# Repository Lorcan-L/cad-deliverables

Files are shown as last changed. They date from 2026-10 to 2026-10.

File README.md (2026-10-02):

# CAD 交付文件

本仓库公开制作深化图纸、可编辑CAD、逐件下料、采购清单与复核说明；R04同版交互三维可用于装配定位，R03保留为历史资料。

## 当前项目

[HW73005-L2000体验桌](https://lorcan-l.github.io/cad-deliverables/hw73005-l2000/)默认R04：22页图册、83项部件、35项五金组件、19种平板激光DXF与1种矩管锯切资料。R03/R02/R01历史下载保持原路径。

[R04同版三维装配查看器](https://lorcan-l.github.io/cad-deliverables/hw73005-l2000/files/R04/viewer/)可按件号旋转、分离、定位孔和线路，并跳转22页图册；三维用于装配定位，制作仍以正式图纸为准。

[AI 接单能力蒸馏方案](https://lorcan-l.github.io/cad-deliverables/ai-order-sop/)以 R04 和工程师反馈为回放材料，提出 Skill、状态工作流、独立校验器与分级交付的实施路径；方案本身不代表生产放行。

## 文件结构

project.json记录版次、可用状态、大小和SHA256。当前文件及同版三维位于files/R04；R03历史三维仍位于files/R03/viewer。预览来自各版最终PDF。

## 验收边界

R04为制造审核版，未生产放行。材料、割缝、折弯与V槽、结构荷载、五金配装及电气须首件和实物检验；数字回读不等同接收方CAD操作验收。

## 本地及Pages

仓库根运行`python3 -m http.server 8765`。GitHub Pages从main分支根目录发布。

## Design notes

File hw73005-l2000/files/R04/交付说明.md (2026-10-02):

# HW73005-L2000_R04 制造审核交付说明

2026-10-02；单位mm；每桌数量。此版为制造审核版，尚未生产放行。

## 交付内容

- DWG2004可编辑工程图、同版DXF、22页矢量PDF。PDF文字已转路径，不支持文字选取。
- 83项部件与35项五金组件的XLSX；公开参考价按销售包装换算，H04锁具套件仍缺精确单价。
- 19种平板激光DXF、1种矩管锯切说明，以及1张不另领料的S03A V槽工序辅图。
- 下料与工序索引.csv、page_manifest.json、validation.json。

## 已验证

- 图册22页；DWG回读22布局、10996模型实体、215原生尺寸。
- 全22页PDF逐页目检；下料文件已逐件几何与预览复核；同版SHA见validation.json。
- DXF的CUT层为名义净形；CAM割缝补偿不得混入图形。ETCH/GROOVE/INFO/REFERENCE不可作切穿。

## 生产放行前须确认

- 材料牌号、公差、割缝；同材同厚试折反算R/K与V槽余厚，复核刀具和回弹。
- 折盘与焊接首件、装配外包和孔位；H26压入H25后的保持力、可拔力和顶面齐平；SOSS 101开合。
- 4.0m国标16A CCC厂制主线规格、报价、外径及近C防拉脱拉力；JB1最终接头开孔模板。
- H04锁具完整套件价格；接收方CAD打开、量测、编辑及工厂首件验收。

历史R01/R02/R03不由本交付包改写；公开发布仅作制造审核资料，不代表生产放行。

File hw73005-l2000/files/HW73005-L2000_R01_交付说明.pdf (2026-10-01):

HW73005-L2000 · R01 · 2026-10-01 · 单位mm | 1

# HW73005-L2000

# 体验桌制作深化交付说明

R01 · 2026-10-01

## 本版依据顾客DWG有效模型、引用块、尺寸和五张参考照片制作。顾客确认桌面共2组翻盖，每组1个三位五孔并 带3USB的排插，总计2个；色号、光泽、图示指定公差及外观工艺按样板。

控制项 | 同版结论
成品外包 | 2000×1200×900；单位mm
桌面 | T18阻燃多层三聚氰胺板，双贴面；周边T0.25科技木皮
金属 | 侧边/腿T1.5，底盘T1.0，C筋T2.0；外观按样板
供电配置 | 桌面排插2；桌肚八位五孔排插2；明装五孔安全插座1
过线小件 | 外护套20；内盖10；镀锌内片10
成果 | 原生DWG 2004、同版PDF、BOM四表、交付说明与ZIP
当前级别 | R01成型深化稿。含设计调整、配作接口和首件工序；尚未生产放行。

# 文件使用边界

## DWG中每个图页有独立布局，模型实体以mm绘制；总装/零件图按图签比例输出，明确标出的局部放大图除外。 纸面标注优先，不从截图量尺寸。图签未填写实际审核人的姓名。

## 数字结构校核、PDF视觉检查和公开下载验证各自独立。它们不替代接收方CAD实机编辑、实际样板核对、工厂 折弯试制、电气装配检验或首件验收。

# 图号、PDF页码与件号索引

页 | 图号 | 内容 | 件号
1 | A01 | 整桌总装 · 三视、基准与装配尺寸 | A01
2 | A02 | 总装拆件 · 构件分离轴测与安装层次 | W01、W02A、W02B、A05、S01、S02、S04 、S05、S07、A07
3 | A04 | 钢结构总成 · 底视布置、三视与焊接 | A04
4 | A03 | 桌面与翻盖总成｜孔位、毛刷及护口布置 | A03
5 | A05 | 承托盒总成｜两组翻盖下方安装 | A05
6 | W01 | W01 桌面成品板｜实际切口与封边控制 | W01
7 | W02 | W02A / W02B 翻盖板｜有槽与实板配对 | W02A、W02B
8 | W03 | W03 承托盒长侧板｜阻燃多层板 | W03
9 | W04 | W04A / W04B 承托盒短侧板｜有孔与无孔分件 | W04A、W04B
10 | W05 | W05 承托盒底板｜托底构造与三视 | W05
11 | S01 | 长边斜腹板 · 成型与端部放样 | S01
12 | S02 | 短边斜腹板 · 成型与端部放样 | S02
13 | A07 | 刀形桌腿总成 · 分缝、脚件与过线 | A07
14 | S03A | 刀形腿壳 · 成型三视与焊缝 | S03A
15 | S03BC | 刀形腿封板 · 内端板与底封板 | S03B、S03C
16 | S04 | 桌肚底盘 · 折边、检修口与定位 | S04
17 | S07 | 检修门 · 门缝、铰链与排插固定 | S07
18 | S05 | S05 长向 C 型加强筋成型制作 | S05
19 | S06 | S06 U 型卡槽成型制作与安装 | S06
20 | A06 | A06 小孔过线护口组件｜配合与安装 | A06
21 | M01 | M01 304不锈钢过线外护套｜20件/桌 | M01
22 | M02 | M02 304不锈钢过线内盖｜10件/桌 | M02
23 | M03 | M03 内盖镀锌内贴片｜10件/桌 | M03
24 | E01 | 电气安装与走线｜位置、连接及R01过线调整 | E01、E02、E03、E04、E05、E06
25 | H01 | 五金与毛刷配套｜数量、接口及模板配钻 | H01、H02、H03、H04、H05、H06、H07、H 08、H09、B01、B02

BOM中的总成行用于装配追溯，不与子件重复领料；左右或异形件分别计数。线缆、管材和保护材料按现场实际长度配置，未知值保持空值， 不以0代替。

# R01尺寸协调与设计改变

项目 | 原图问题 / 本版处理
总高 | 源钢腿882加脚伸出5及桌面18会达到905；本版采用钢腿877、脚伸出5、桌面18，闭合为900。
桌体外包 | 源底视深向几何1200而覆字1190；本版金属1990×1190，桌面四边各退5。
加强筋 | 源T3线稿与T2文字冲突，采用T2；30×97、唇13，净距430、外跨490。
筋端干涉 | 原斜端与腹板内面局部交叉；本版上端及斜面向桌内净退至少1，保留阶梯和底退台。
翻盖 | 每组开口300×140；A有槽盖、B实截面各1片；每片298×58×18，长度方向1+298+1。
承托盒 | 每盒330×230×96；R01选T15阻燃多层板侧板、T5底板；每盒一个短侧板φ50过线孔。
底盘/检修门 | 底盘外包1769.4×969.4×15，定位115.3/115.3；检修孔X500，Y190/850，1000×160；门994.8×154.8，边缝2.6。
腿分片/底板 | 开口刀形壳+内端板+底封板；底封板T1.5、M8焊母8、调节脚8。分缝和底板厚为R01选定。
桌面紧固 | R01定12枚Φ4×12木螺钉；钢件φ4.5；木板预钻φ2.5深10，避免打穿。
过线冲突 | 源≥25铁管与刀形腿净腔约24.7不相容。本版提出管止于腿上口、腿内线缆保护引出；需实物样板/工厂复核该改变。

# 加工、装配与外协执行

## 木作：先核对板材和样板，按W01孔槽加工；翻盖从同纹理区配取并保持A/B方向。工厂结合实际刀具、锯缝和封 边厚度分配余量，不将成品2000×1200直接当基板尺寸。全桌20个小孔按外护套主体φ10.9配合试钻，φ11.9是法 兰，不能误作通孔。

## 钣金：按成型三视和截面开工艺展开；结合实际材料、内R、折弯扣除和焊接收缩先试1件。腹板端口、刀形壳与 底封板需按1:1成型轮廓配切。先焊母和内附件、后封壳；骨架点固校方，再对称分段焊。外露焊缝打磨及表面处 理按样板。

## 车加工：M01/M02采用304不锈钢棒；按同版剖面保留法兰、台阶、通孔/盲孔及圆角。M03为φ6×3镀锌内片。先 加工一组外护套/内盖试配，再按图示公差与样板执行；内片粘接后不得脱落或凸出妨碍装配。

## 装配：钢架完成外观处理后装脚、门、护口与线缆保护；试装桌面、承托盒和翻盖，检查中心毛刷净槽20及启闭 空间。排插及固定器避开门锁舌和合页转轴。接线采用源指定3×1.5mm²，端子连接处加黄腊管，线缆夹持并消除

锐边。

# 必须在工厂完成的具体闭合项

对象 | 所缺实物或工艺数据 | 影响
S01/S02/S03/S04/ S05/S06/S07 | 实际板材、折弯机/模具、K因子或实测扣除、焊接收缩 | 不能将成型外包当最终激光展开料
S03C及腿端口 | 首件壳体与腹板成型实物 | 底板内轮廓和顶斜口需套样配切
锁/铰链/排插固定 器/毛刷 | 实际品牌型号及安装模板、样板 | 孔形、夹持接口及毛刷卡入尺寸需实配
腿内过线 | 顾客样板或等效实物、实际护管和线缆 | 核实≥25管与腿腔矛盾的解决方案
整桌 | 首件与使用条件 | 静载/稳定性、翻盖与检修门、脚调节、电气检 验尚未实测

# 原图参考照片与对应工序

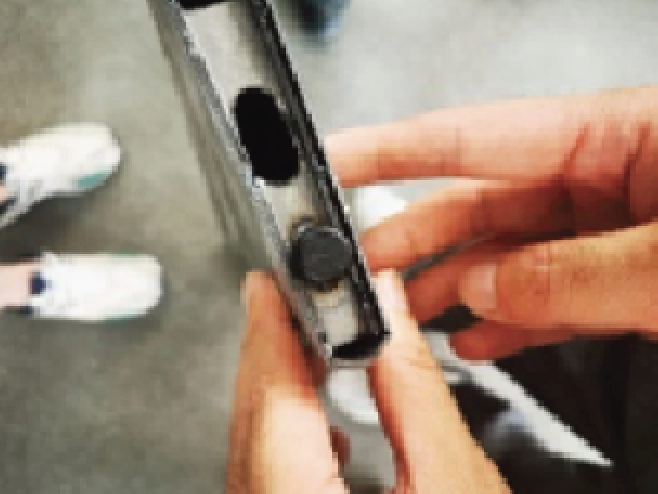
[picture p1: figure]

刀形腿内脚件：隐形调节脚及底部装配。

来源：顾客DWG有效图片 C908

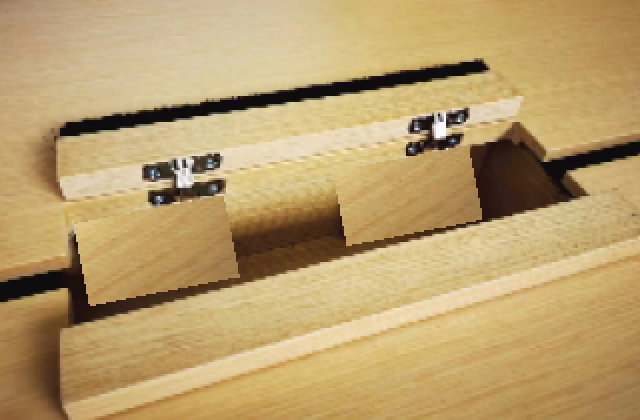
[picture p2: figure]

翻盖合页示意：闭合、开启与接缝按实配。

来源：顾客DWG有效图片 C909

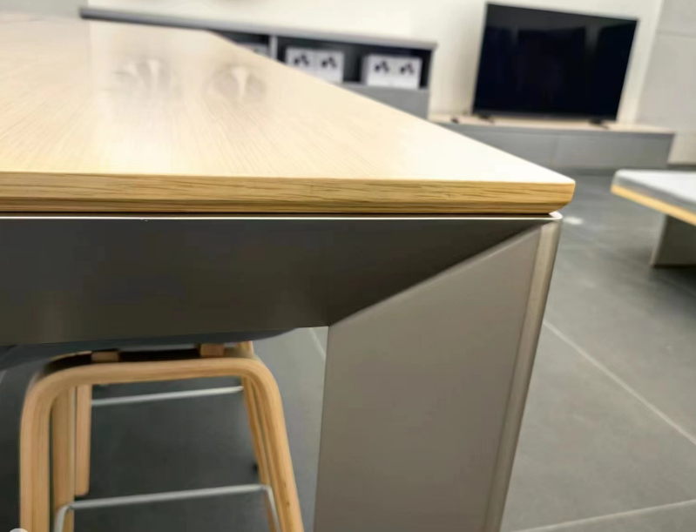
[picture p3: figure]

木饰面与钢侧边：纹理、封边和外观按样板。

来源：顾客DWG有效图片 C90A

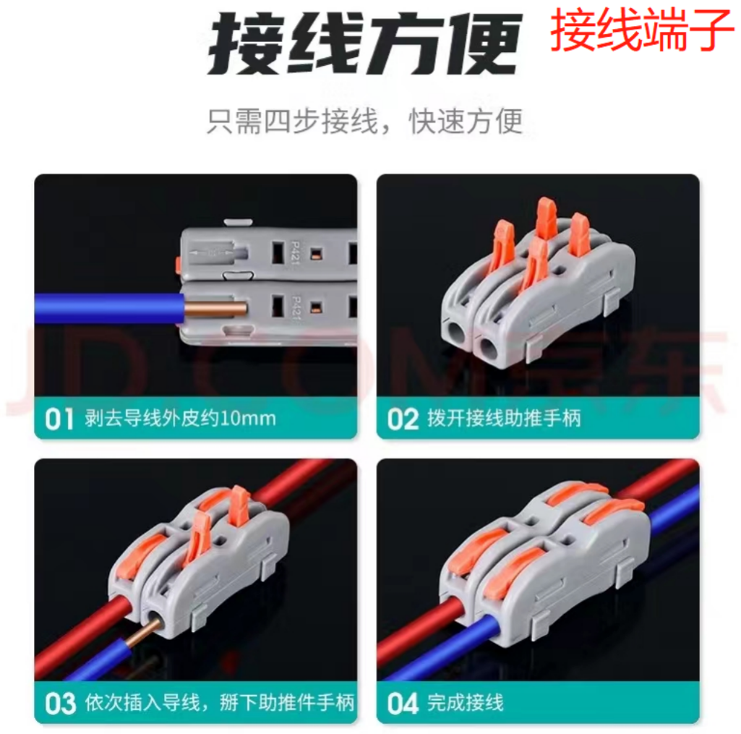
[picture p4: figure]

端子参考：按实际端子和线径完成绝缘保护。

来源：顾客DWG有效图片 C90B

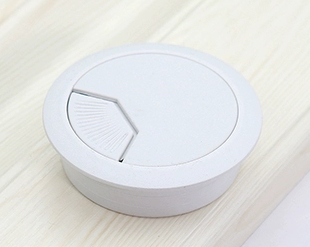
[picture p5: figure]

白色护口：承托盒φ50安装孔，选件实配。

来源：顾客DWG有效图片 D95E

# 逐类验证记录

类别 | 检查范围 / 结果
来源 | 顾客DWG：有效模型/引用块与五张图片已提取 旧未引用说明未纳入；原件副本只读归档
三视/接口 | 总装、分总成及制作件：已绘并进行图页复核；配作接口另列 各件front/top/side字段指向对应图页；曲面壳、折弯展开和到货五金仍须首件
CAD结构 | 同版DXF/DWG：DWG2004回读及逐实体校核通过 真AC1018、mm、25布局、144原生尺寸；29031项数值比较最大差5.83e-11，小于1e-7；转换副本补齐尺寸缓存和 VIEWPORTS图层
PDF视觉 | 全图册：25页逐页目检通过 中文、页码、图签、裁切与重叠检查；第9页尺寸已修；PDF SHA256 0c985bdb8ef0cef5bd1bed98eaff329f0e4b17fdf5297fe6138f533186925f31
同版清单 | 件号/页码/数量：42项件号、数量和父级核对通过 25图号映射一致，无缺失父级或自指；装配与领料分别计数；E04/E05长度留空
制造 | 钣金展开及腿配切：外部待定 需实际板材/刀具、折弯扣除、成型首件和焊接收缩；未发布最终展开下料
外购接口 | 锁/铰链/排插/毛刷：按到货模板及样板配作 型号未指定；本版已定安装基准，孔形/型材卡入尺寸不得猜测
过线冲突 | 刀形腿与≥25铁管：R01提出调整，实物待核 腿净腔约24.7；管止于腿上口，腿内线缆加保护与夹持；不得当原管贯穿已满足
接收方CAD | 实际接收软件/版本：未执行 ODA转换和ezdxf回读不替代接收方CAD操作验收
首件/电气 | 工厂实物：未执行 强度稳定性、脚调节、门盖启闭及电气检验须实物完成

# 文件身份与使用

### 正式下载文件及SHA-256以网页 project.json 和交付包内交付清单.json为准。哈希用于核对下载完整性，不是加工

## 正确性证明。原顾客文件保存在本地source目录，未被覆盖。

## 未完成的外部验收：实际接收方CAD打开/重生成/编辑、工厂展开及首件、电气装配测试。公开本版用于复核和工 厂深化配作，不等同于批量生产放行。

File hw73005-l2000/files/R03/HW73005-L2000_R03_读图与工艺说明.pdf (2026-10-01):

HW73005-L2000 · R03 · 单位mm · 未生产放行 | 1

# 体验桌 R03 读图与工艺说明

## 先定位，再看接口，最后按尺寸加工。

图册52页；BOM共84项。三维网页、装配模型、PDF、二维CAD及清单共用件号。总成数量用于装配追溯，不能 与子件相加领料。

1 找件号 | I01制作件与总成；I02五金；I03电气。按件号查三维图、加工/接口图和孔号。
2 看位置 | 整桌 A02 / P05；桌面 V02 / P06；木盒 V10 / P07；钢架 V03 / P08；检修 V04 / P09。
3 看接口 | 五金局部 V05 / P10、V07 / P12；电器 V06 / P11；端子箱 V08 / P13；PE/入口 V09 / P14。
4 看尺寸 | 按引线旁的图号及页码打开制作三视。图纸里的跨图引用和目录带PDF内链；CAD中每张图有同名布 局。
5 查线孔 | 电气导航 E01 / P43；原理 E02 / P44；端子 E03 / P45；入口、C筋及木盒孔见E04～E06。
6 用三维 | 按件号搜索 → 选中 → 只看选中。分离滑杆用于拆装关系；看孔与路线时自动回到安装位置。选择孔 号可查看孔径、所在件及经过线路。

## 图形读法

彩色实体表示已建的成型几何或采购件简化外形；线框安装区不表示厂家完整实体。小符号表示已知安装位置而 外形待核。虚线板件用于定位；三维轴测不能量取加工尺寸。

外形未核的排插、插座、箱体接头等不伪造孔径。标为“待核”的孔禁止按规划点直接钻孔。

## R03修订与装配顺序

木盒出线 | 原短侧W04A取消。两块近侧W03A开φ50，孔心局部165/51；远侧W03无此孔，W04B统一4块。H0 6从外面装入22、内凸约7。见W03 / P22、E06 / P48。
内部装配 | 四根螺接横梁、木盒及电器留在钢架；八点M6使整块桌面可拆。检修口和工具通道不作走线占用。
分线箱 | E07采购一套：1557HA2GY箱体1件＋另购1557HPL内板1件。E15为150导轨1段＋端挡2件＋绝缘 端板3件，不能只采购裸导轨。
移动检修 | 载板名义下放175.45。防坠索孔心距183不是盖板垂降；盖板服务位和两组独立锚点按S10F / P16。线束和PE不承重。
模型修正 | 后门排插固定器按全局X1100/1400布置；箱内19端子操作面向下，导轨包络以线框表示。所有模型 页码重新绑定R03图册。

## 现场装配顺序

① 钢架点固校方、焊接和表面处理 → ② 装四横梁、盒抱角和检修支承 → ③ 装木盒、端子箱和成品五金 → ④ 按线路号穿孔、固定、端接并检查PE → ⑤ 试门盖及载板全行程 → ⑥ 装桌面、翻盖和毛刷 → ⑦ 完成首件检验后放行。

检修时先停负载、断电、拔下总输入并由检修者控制插头，验无电后再操作。松防脱螺钉之前确认相应防坠索已 可靠连接。回装检查夹线、接地、紧固与启闭。

## 制作控制 · 按图号回查

W01 / P20 | B：φ10，顶钻深11.5；C：φ10起试，孔深≤14；C：留面≥4，嵌母齐底；基板1999.5×1199.5；四边 T0.25木皮；外R15
W02 / P21 | 2×φ10深11.5；u=50 / 248；底余厚6.5；A在低Y侧，槽口朝中间；B在高Y侧；每盖两只BH104；端 缝各1；周边缝2；A/B各2片，同板顺纹；底槽沿A盖全长；抬90°检修，勿踩踏
D02 / P25 | RS 326-9808；2根×1m；段间缝1；总覆盖1420；每段2枚φ3×8木螺钉；座孔φ3.5；木盲钻≤6；BH 104共8只；φ10顶钻深11.5；距开合边6.8；边缝2；抬90°检修
S03A / P29 | 冷轧钢板T1.5；数量4；鼻端保留R8；内R6.5；端板分缝朝桌内；顶口u18..131.062降100；首件检 截面及腹板贴合；切割 → 包折 → 试装；装底板焊母 → 封板焊接；外露缝磨平后表面处理
S03BC / P30 | B/C各4片；冷板T1.5；C沿壳内廓配切，缝0.2；C下表面内沉1；先焊M8母，通规后封B；不设腿内 过线孔
S05 / P33 | 冷板T2；数量2；截面30×97；斜边净退≥1；先试装再焊；展开按首件试折，不取投影周长；C口相 向；净距430；M5柱朝C内；详E03/E16
S09B / P38 | 钢板T3；宽40×包40×高35；槽6.6×12沿X；距端13；竖腿焊于C筋外腹面；焊后校准8耳共面；内R 与扣除经首件试折
S10C / P41 | 钢板T3；宽20；数量4；右侧绕Z转180°；先焊M5母；四臂下面Z874共面；吊线只接左前/右后；固 定锚见S10F；M4×16头部至木底净≥0.75
A06 / P52 | H25 CHC-S18BL：20只；孔φ14 +0.5/0；H26 045.00.332：10只；有线孔不装盖；衬套入孔16；法 兰2；加盖总突出4；跨品牌组合：首件验卡紧与拔出保持

本页只汇总当前R03工艺控制。孔位、三视、板厚及节点尺寸均以同版制作图为准；历史迁出的长说明不作为当前加工指令。

## 电气工艺说明 · 1

## NE01 现场保护 · E02 / P44

QF0为现场边界，过流允许值不大于10A，Type A 30mA；曲线、分断和上下级配合由现场核定，不表示已安装。 I1+I2+I3+I4+I5≤I_allow≤10A，I_allow取上游、P0/X0、线束及最弱器件的最小允许值，不得相加各排插标称功率

。

## NE02 原装线与支路 · E02 / P44

P0整根国标10A/C13成品线；四排插各接独立固定插座，保留原装线和插头，不互相串接、不剪改。W00/W1~W 5铜芯护套线3×1.5mm²，L棕/N蓝/PE黄绿，两端永久套号。

## NE03 端子工艺 · E03 / P45

WAGO2002按厂家剥线10~12mm；软线适配端头冷压，一夹一线，不用浸锡线夹压。L灰/N蓝各自用一根2002-4 06六连桥，PE专用接地脚与连续导轨，绝不N-PE跨接。端挡249-116两只、隔板2002-1291三只，DIN35×7.5轨 约150实装核。

## NE04 绝缘和抗拉 · E04 / P46

X0使用6100.3300、RC320-03后罩、TE735278全绝缘快接L/N/PE各一；不从视图猜端脚顺序。后罩/快接不抗拉 ，独立机械夹护套；黄腊管只附加绝缘，不替代护套、护口、封闭盒和应力释放。

## NE05 保护连接 · E03 / P45

E16七条2.5mm²黄绿线：XPE6到PE0、PE0到焊组、另三梁到焊组、两门到焊组。11只FV2-5、2只FV2-4，10只 M5×20焊柱及各齿/平垫/防松母、2套门M4紧固、1只3202533套管；不含E21~E24中央两线。PE不断开，不经开 关熔断器，不用油漆面、铰链或结构螺钉代替。

## NE06 断电检修 · E03 / P45

停负载、断现场保护、拔P0并由检修者控制插头挂牌；测试器前后自验并验无电，等待成品电源放电。确认两防 坠线承重后卸防脱螺钉，下放载板175.45；盖索孔心距183，服务位见S10F；线不受拉再检修。按端子号复接， 验PE连续性、极性、绝缘、端子、抗拉、门全启闭与保护动作，负载预算核定后复装送电。

## NE07 入口弯线 · E04 / P46

W00护套外径≤8.5，厂家允许静态最小弯曲半径≤30；后罩至Z834、木底Z882，线弯外包不得超Z882。该约束是 选线条件，尚待到货曲率和全轨迹首件；活动段另核，不把折线当可实际锐折。入口切口28(+0.2/0)×20(+0.2/0)， R≤3，2φ3.5孔距40±0.2。

## NE08 C孔和过梁层 · E05 / P47

两S05 C腹板φ20/T2仅穿护套线，护管止于孔前；实际护管外径≤25方可进入Z848..882净34的过梁层，路线中心 暂Z865。DN25不是外径25；线夹、弯头、护口内径和侧向通路均需实物核定，不绕C筋近乎无净空端部。

## NE09 门排插包络 · E05 / P47

GN-604每门一只；400×100×86.5是固定器、原线及用户插头总验收包络，顶≤Z870，不能冒充厂家外形。X3/X4 固定插座符号只指安装区，配合门启闭、锁舌、铰链、8点工具柱试装后锁定支架/孔。

## NE10 木盒原装线 · E06 / P48

R03将两个原装线孔移至近侧W03A长板，取消W04A短端孔：孔心左X600/右X1400、Y492.5/Z842，局部165/51 ；φ50/T15，Häfele429.99.735白护口入孔22向内约7。板外Y485至C筋Y385净100，孔边至最近横梁面净155， 上边余15/下边26。U1/U2从长边孔接X1/X2；原装插头通过、护口拆装顺序和弯曲半径仍需首件，禁止剪改原装 插头或梁。

## NE11 待核开孔 · E04 / P46

JB1 K10~K16中心继承R02路线端点，接头型号、孔径、绝缘和抗拉尚待选型；不得照规划点钻孔。X1~X5外包/ 固定孔未知，保持null。箱内150轨、19端子和182方内板按E03设计面Z862装配；内板柱高/紧固孔与盖内净距首 件核。中国适用认证、到货CCC、完整保护和通电试验未执行，不据图直接生产放行。

## NE12 中央移动余量 · E03 / P45

JB1盖向下，200×200×70；左右接头突出≤30。载板下放175.45；盖索孔心距183、锚点垂降181.227，服务位见 S10F；各两条防坠索独立承重；电缆和两条2.5mm²中央PE额外维护余量初设≥250，按厂家弯曲半径及全程实物 定长，PE不吊重。E21两线独立回PE0；E22/E23环端各两只，E24移动M4套两套。

## NE13 用户孔 · E06 / P48

W01二排20孔，X235+170n（n0..9）、Y250/950，φ14+0.5/0，配CHC-S18BL内φ12。UC01~UC20仅表示预留 过孔，用户设备和下方终点未指定；不将任意孔接到本机市电支路。闲置10孔盖与衬套为跨品牌组合，首件配装 待核。

## 同版使用与验收范围

有效文件 | 本次仅成套使用R03。R01/R02保留作历史记录，不混用旧W04A短侧孔、旧模型坐标及旧页码。
二维工程 | DWG/DXF含原生尺寸、线弧和同图号布局。按制作三视加工；最终折弯展开仍需工厂用实际板厚、 内R及折弯扣除试折确定。
三维工程 | 装配DXF/DWG使用同源网格面、实例块和件号信息。采购包络为线框；用于定位和拆件，不是参数 化实体或展开加工模型。
采购与替代 | 按采购XLSX中的型号、套件组成、包装量及原厂来源核实。替代品改变外径、板厚、孔距、锁舌或 接头时，回到接口图复核。
实物首件 | 承载、稳定性、焊缝、脚件净空、翻盖、插头通过、下放余量、线夹抗拉、PE连续性、绝缘/极性和 保护动作尚待工厂及电气首件。
三维访问 | 优先从交付网页打开三维索引。ZIP内viewer目录是同版备份；离线查看时需通过本地HTTP服务打开 ，直接双击HTML可能无法载入模块。

本轮验证区分图面可读性、同源几何和文件完整性。程序检查、模型核对及浏览器操作不替代接收方CAD编辑验 证或实物验收。

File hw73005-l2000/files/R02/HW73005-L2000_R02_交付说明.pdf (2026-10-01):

HW73005-L2000 · R02 · 2026-10-01 · 单位mm | 1

# HW73005-L2000

# 体验桌制作深化交付说明

# R02 · 可拆检修修订 · 2026-10-01

## 本版按“桌面检修、灵活固定、成品五金清单、线路图、桌肚内部加强及检修位置”的反馈修订。沿用顾客DWG外 形及两组桌面供电配置，新增内部机构和可重复拆装接口。颜色、光泽、图示指定公差及外观工艺按样板。

控制项 | R02同版结论
成品外包 | 2000×1200×900；T18阻燃多层三聚氰胺板双贴面；T0.25科技木皮封边
固定与加强 | 桌面8点M6机螺钉/嵌母；4根40×50×T2可拆横梁；承托盒固定钢架
检修 | 2个长检修门、1个中央检修盖；盒及排插留在钢架；中央接线吊板可下放
供电 | 2个桌面三位五孔+3USB排插；2个桌肚八位排插；1个安全五孔；五路并联
小护口/毛刷 | 20套CHC-S18BL护口配10只成品盖；毛刷按固定板和翻盖分5段
成果 | 37页图册、84项BOM、独立采购清单、交付说明及ZIP
当前级别 | 成型深化稿；已绘成品接口、三视及检修动作，尚未生产放行。

# 使用规则

## R01保留作为历史版本；本次制造复核只使用R02整套文件，不混用旧脚孔、护口孔、12点木螺钉及检修门坐标。 DWG按mm绘制，每图号有独立布局；局部放大按页内说明。不得从截图量取加工尺寸。

## 模型/尺寸校核、PDF目检和下载哈希各自独立；不替代接收方CAD编辑、厂家实物配装、结构承载或电气首件验

收。

# 图号与PDF页码索引（1～19）

页 | 图号 | 图页内容 | 件号
1 | A01 | 整桌总装 · 三视、基准与装配尺寸 | A01
2 | A02 | 总装拆件 · 构件分离轴测与安装层次 | W01、 W02A、 W02B、 A05、 S01、 S02、 S04、 S05、 S07、 A07、 S08、 S10A、 S10B
3 | A04 | 钢结构总成 · 底视布置、三视与焊接 | A04
4 | A03 | 桌面与翻盖总成｜孔位、毛刷及护口布置 | A03
5 | A05 | 承托盒总成｜两组翻盖下方安装 | A05
6 | W01 | W01 桌面成品板｜实际切口与封边控制 | W01
7 | W02 | W02A / W02B 翻盖板｜有槽与实板配对 | W02A、 W02B
8 | W03 | W03 承托盒长侧板｜阻燃多层板 | W03
9 | W04 | W04A / W04B 承托盒短侧板｜有孔与无孔分件 | W04A、 W04B
10 | W05 | W05 承托盒底板｜托底构造与三视 | W05
11 | D02 | 翻盖与成品毛刷安装 · 顶装桶铰链、承托及分段 | W01、 W02A、 W02B
12 | S01 | 长边斜腹板 · 成型与端部放样 | S01
13 | S02 | 短边斜腹板 · 成型与端部放样 | S02
14 | A07 | 刀形桌腿总成 · 分缝与成品脚件 | A07
15 | S03A | 刀形腿壳 · 成型三视与焊缝 | S03A
16 | S03BC | 刀形腿封板 · 内端板与底封板 | S03B、 S03C
17 | S04 | 桌肚底盘 · 折边、检修口与定位 | S04
18 | S07 | 检修门 · 门缝、铰链与排插固定 | S07
19 | S05 | S05 长向 C 型加强筋成型制作 | S05

总成行用于装配追溯，不与子件重复领料；各件数量均按每张桌。线缆长度、包装数量与装配用量分开，未定数值保留空值。

# 图号与PDF页码索引（20～37）

页 | 图号 | 图页内容 | 件号
20 | S06 | S06 U 型卡槽成型制作与安装 | S06
21 | A08 | R02 内部加强与检修 · 八点拆面、横向框架及接近通道 | A08
22 | S08 | S08 可拆横梁总成 / S08A 矩管身 · 成型三视与端接口 | S08、 S08A
23 | S09A | S09A 横梁端板 · 焊母接口及C腹板连接 | S09A
24 | S09B | S09B 桌面固定耳 · 原检修口上方八点可拆接口 | S09B
25 | S09C | S09C 承托盒抱角 · 盒固定在钢架且可拆 | S09C
26 | S10 | S10 中央检修盖与吊检修板 · 三视、支承及防坠 | S10A、 S10B
27 | S10C | S10C 检修板悬臂 · 左右转向装配、焊母及防坠锚点 | S10C
28 | S10DE | S10D 补强片 / S10E 锁接收座 · 成型三视与接触剖面 | S10D、 S10E
29 | S10F | S10F 中央检修服务位 · 成品索长度、独立锚点及实体行程 | S10A、 S10B、 S10C、 H23、 H24
30 | D01 | D01 桌面可拆固定 · M6嵌件节点、工具柱及拆卸顺序 | W01、 S09B、 H09
31 | E01 | R02 电气物理布线｜成品入口、五末端及三向检修位置 | E01、 E02、 E03、 E04、 E05、 E06、 E07、 E08、 E09、 E10、 E11、 E12、 E13、 E14、 E15、 E16、 E17、 E18、 E19、 E20、 E21、 E22、 E23、 E24
32 | E02 | R02 五路电气原理｜L/N/PE分别接线，连接示意不按空间比例
33 | E03 | R02 端子接线与检修｜逐点编号、线色线径、脱开与复装
34 | H01 | H01 成品五金采购索引与每桌用量 | H05、 H06、 B01、 B03、 H23、 H24
35 | H02 | H02 桌面、调节脚及防脱紧固接口 | H01、 H02、 H09、 H10、 H11、 H13、 H14、 H15、 H16、 H17、 H18、 H22
36 | H03 | H03 检修门、工具锁与小翻盖安装接口 | H03、 H04、 H07、 H12、 H19、 H20、 H21
37 | A06 | A06 成品小孔衬套与闲置孔盖装配接口 | A06、 H25、 H26

总成行用于装配追溯，不与子件重复领料；各件数量均按每张桌。线缆长度、包装数量与装配用量分开，未定数值保留空值。

# R01 → R02 修订及接口替换

对象 | 本版改变
可拆桌面 | 原12枚木螺钉改8组M6×12+平垫+RAMPA SKD30 M6×12。孔心X580/850/1150/1420，Y328/872；木底预钻10～10.5、深≤14。
内部横梁 | 4根RHS40×50×T2，管长472，端板T3后总长478；每端2枚M6×20及4mm垫层，共16螺钉、64片1mm垫。
承托盒 | 两个330×230×96承托盒由8个S09C抱角托住；8枚M4×25由盒内穿端板紧固。拆桌面时盒与电器留钢架。
长检修门 | 窗口X500..1500，Y180..340/860..1020；994.8×154.8门四边缝2.6。HG-OTA75合页及MS705-1-1锁均绘真实接口。
中央检修 | 净窗300×340，X850..1150/Y430..770；340×380盖搭接20；240×300接线吊板独立支承，盖及吊板各4枚防脱螺钉。
脚与高度 | 成品TG-20：φ20×高6、M8×15；底封板内沉1，外露5。脚孔移u80/110、v13.9665避开腿壳窄端，取消旧34×14穿线 孔。
小护口 | 原定制M01/M02/M03退出R02领料，换CHC-S18BL20套+Häfele盖10。W01安装孔改φ14(+0.5/0)，外法兰φ18；跨品 牌盖须实配。
翻盖/毛刷 | BH104桶铰链每盖2只共8；顶面φ10深11.5，闭合共面时可见链节。SU-30S角码承托。毛刷分160/298/500/298/160 五段，两298段随A盖抬起。
供电入口 | 取消腿内穿主电源；成品国标10A/C13线接桌底X0 C14。X0中心280/430，28×20切口、两φ3.5孔中心距40。原厂RC320-03后罩保护端接。
线路图 | E01物理布线，E02五路L/N/PE原理，E03端子/检修。四排插保留原插头，禁止互插；上游QF0为现场供电边界。

# 加工与装配顺序

## 1. 木作先核板材和样板。W01按切口、φ14护口孔和八点嵌母盲孔加工；嵌母试装后确认不鼓面。BH104从顶面

### 钻φ10深11.5，不能从底面反钻；四盖保持A/B方向和连续木纹。SU-30S配φ3×12螺钉，不使用长于侧板厚度的原

## 配螺钉。

## 2. 钣金以真实成型三视、源线弧截面和节点为基准。实际内R、折弯扣除、焊接收缩由工厂试折确定；成型外包不 是激光展开料。刀腿底封板依成型内腔留0.2配切，先焊母、后封壳；两脚φ20包络与斜内壁最小余量约0.4，首件 检查不可省略。

## 3. 钢架点固校正后对称焊接。两C筋各8个φ6.6横梁连接孔、1个φ20护口孔；四横梁及端板先核净长和转出动作， 再紧固。固定耳、盒抱角、中央悬臂、补强片和锁座按本版坐标焊装。

## 4. 两承托盒放入抱角；从盒内装M4×25和垫片。安装两桌面排插及固定分支插座，原装线整理并夹持。毛刷铝座 按五段裁切、去毛刺，每段两枚φ3×8固定；毛刷沉入28×7槽，不宣称刷顶齐台面。

## 5. 固定中央接线盒至吊板，接好两独立防坠件与专用柔性PE，再固定四枚防脱螺钉。防坠件锚点和标准长度按S1

### 0/S10C/H02最终图执行；不得自行剪短、打结或用电缆承重。

## 6. 安装长门成品合页、锁、接收座及排插固定器。门上的电缆和PE留活动弧，开门后八个φ12工具通道保持可达 。试合门、拔插总入口、中央盖拆装和吊板下放，确认不夹线再进入电气检验。

## 7. 最后安装木桌面。M6螺钉从检修门向上旋入，采用细杆长5mm内六角工具；不从上表面打穿。确认全部桌面载 荷落在钢架支承面，再锁紧八点。

不能省略的实物确认 | 对应图/说明
腿壳截面、脚可调/不碰壳、整桌900高 | A07、S03A/S03BC、H02
BH104方向、盖缝、独立承托、插头实插净空 | W01/W02、D02、H03
横梁转出与门工具通道 | A08、S08/S09、D01
防坠/下放、线束弯曲、触电防护与接地 | S10、E01～E03

# 检修路径与拆装操作

## 所有检修先停止负载、断开现场供电并拔总输入P0；由检修者控制插头，确认下游无电。拆木面前先移走用户设 备及穿过小孔/毛刷的线，避免外部线缆牵挂。

场景 | 入口与操作 | 回装检查
桌面插拔/小翻盖 | 从桌面两组翻盖操作；盖向上手扶约90°，BH104无停留扭矩。 | 闭合由SU-30S独立承托；不靠铰链承受台 面载荷。
整面拆卸 | 开两长检修门，沿X580/850/1150/1420、Y328/872直达八枚M6；全部 拆下后多人平稳抬面。 | 承托盒和电器留钢架；确认八点嵌母未松 脱、工具通道无新线束。
更换桌面排插 | 断电后打开翻盖并拔对应原装插头；必要时拆整面，从盒内卸4枚M4后 取该盒。 | 不剪原装插头，不让木板承担接线盒重量 。
长门排插 | 开启相应转舌锁，下翻门并保护活动线/PE；需拆门时使用可缩轴合页 。 | 锁舌搭接S10E、门缝2.6，线圈不进入合 页和锁区域。
中央接线检修 | 先确认中央盖两防坠件，松4颗防脱螺钉将盖挂至窗外；再确认吊板两 独立防坠件，松4颗防脱螺钉后受控下放。 | S10F名义下放175.45；实物线缆弯曲限制 优先。下放件有机械支承，PE仅负责保护 连接。
横梁拆换 | 断电、拆桌面及相关承托盒/吊件；标记并断开该梁PE，再松端部M6， 按A08上移越过C下唇，再转约35°上取。 | 附件先移除；复装先恢复PE并测连续性； 转出不能带盒硬扭，不以481.75转角包络 代替实物演练。

## 复装后逐项确认螺钉、防脱件、防坠件、线缆夹持、保护接地、门盖启闭及工具通道；按电气检验记录合格后恢 复供电。

# 成品五金采购清单的使用方法

## 独立采购XLSX是本版对外询价入口。每行区分厂家技术来源、销售入口、每桌装配用量、包装量及到货条件。官 网可订购或经销商列货不等于国内现货；未下单，不在图册中承诺交期。

采购组 | 锁定内容 | 到货必核
桌面与钢架紧固 | RAMPA SKD30 439612001、M6×12、M6×20、DIN988 垫片及各规格DIN929焊母 | 螺纹、长度、焊母定位凸台；焊母与通孔不能混为普通 间隙孔
调节/门五金 | LAMP TG-20、HG-OTA75、恒珠MS705-1-1完整套件 | 锁芯/35长舌/GH18版本；不能混用同名不同锁舌长度
翻盖 | SOSS BH104×8、LAMP SU-30S×8、指定长度木螺钉及软垫 | T18试装、顶钻方向、角码承托、螺钉不得穿板
小孔 | CHC-S18BL×20、Häfele045.00.332盖×10 | 跨品牌组合不是厂家认证配套；试插拔/卡紧；包装数量 不等于使用数量
中央检修 | NBK SSC-M5-8共8、匹配M5焊母、防坠成品共4 | 有效牙长及板层厚度、防脱动作、标准防坠长度、锚点 保持力
毛刷 | RS PRO326-9808，1m成品2根 | 基座/毛长与28×7槽实配；按5段切割留锯缝
电气 | E01～E03列成品排插与插座，E07后续列分线盒、端子、 后罩及端接辅件 | CCC/适用认证、原装线、保护门、外包、插头与门盖净 空

## 采购先按清单型号及图号核实，再选择同型号销售渠道。任何替代品改变外径、板厚、安装孔、锁舌、接头或线 径时，都应回到相应图页核对，不能只以外观相似替换。

## R02取消原定制小护口的车加工领料，但S08/S09/S10等钢制支架、端板、抱角仍按本项目制作图加工；它们属于 结构制造件。未知线缆长度须在样机布线后定长，不填0，不凭二维投影折线直接领料。

# 线路图与电气执行边界

### 五路星形并联：现场保护QF0 → 接地插座 → 原装国标10A/C13成品线P0 → 桌底C14入口X0 → 中央分线盒JB1 →

### X1～X5。X1/X2供两桌面排插，X3/X4供两门排插，X5为安全五孔。四排插均保留原装插头及软线。

图页 | 执行内容
E01 物理布线 | 标出X0、JB1、五个固定终端、两C筋护口、活动线和总输入隔离；坐标只是布置中心，成品外包另须实测 。
E02 L/N/PE原理 | L、N各6只WAGO2002直通端子、各自独立6连桥；7只专用PE端子经已接地DIN轨连接。PE不得与N跨接 。
E03 端子与检修 | 列电源/支路去向、端子标记及检修顺序；线端永久套号，弹簧端子按厂家适配线径和剥线长度执行。

### X0的SCHURTER6100.3300配原厂RC320-03绝缘后罩及6.35×0.81全绝缘母快接；后罩/出口及独立应力释放按E

## 页执行。主进线改沿腿外侧可拆线夹固定，腿内不再强穿≥25护管。

## 上游保护尚属现场边界；浅盒只装分线端子，不伪称已装入普通深型RCBO。总允许电流按现场保护、10A入口及 最弱器件/敷设条件取最小值；设备USB电源的AC输入也计入同时负载，不能将各排插标称功率相加。

## 四根螺接横梁分别通过专用PE焊柱连接主框架；两活动门、中央盖和吊板使用独立柔性PE跨接，不依靠铰链、漆 面接触或防坠钢索导电。电线和PE均不得承担盖或盒重量。

## 放行前需要：适用认证与型号实物一致、上游保护配合、五支路负载记录、端接与夹持、极性、绝缘、保护接地 连续性及保护动作检验。当前图册未宣称这些实物检验已完成。

# 原图参考照片与R02对应关系


刀形腿隐形脚：R02按TG-20重新核定宽端孔位。

来源：顾客DWG有效图片 C908


原翻盖意向：R02采用BH104顶装并独立承托。

来源：顾客DWG有效图片 C909


木饰面与钢侧边：纹理、封边及外观按样板。

来源：顾客DWG有效图片 C90A


原端子意向：R02以WAGO端子及分路图为执行依据。

来源：顾客DWG有效图片 C90B


原白护口意向：盒端φ50孔按成品实配。

来源：顾客DWG有效图片 D95E

# 逐类验证与未完成的实物验收

类别 | 范围 / 结果
来源 | 顾客DWG：有效模型/引用块与五张图片已提取 旧未引用说明未纳入；原件副本只读归档
三视/接口 | 总装、分总成及制作件：已绘并进行图页复核；配作接口另列 各件front/top/side字段指向对应图页；曲面壳、折弯展开和到货五金仍须首件
CAD结构 | 同版DXF/DWG：DWG2004回读通过；37布局、202原生尺寸、49,208项数值一致 同版DXF/DWG SHA绑定；最大绝对差5.82×10⁻¹¹mm；audit错误0，修复0
PDF视觉 | 全图册：37页已逐页目检通过 最终PDF SHA绑定01～20、21～30、31～33及34～37页报告；中文/尺寸/图签和检修接口可读
同版清单 | 件号/页码/数量：84项件号、父级、图号、页码与三视引用检查通过 含8条装配追溯行，不与子件重复领料；E04/E05长度保留空值；两份XLSX另附公式/超链接验证
制造 | 钣金展开及腿配切：外部待定 需实际板材/刀具、折弯扣除、成型首件和焊接收缩；未发布最终展开下料
外购接口 | 成品五金及电器：已选可购型号，分列厂家实证和到货项 hardware_sources及electrical_design；M6嵌母、桶铰链、锁、合页和护口接口已纳图
拆装检修 | 八点桌面、四横梁、三检修口：R02机构与工具通道已绘 八点Y328/872、两门Y180/860、中央300×340；实物动作/强度未验证
电气 | 总输入与五支路：三页物理布线/原理/端子表已绘 排插原插头保留；X0可达总入口；L/N/PE分配及活动件PE跨接
接收方CAD | 实际接收软件/版本：未执行 ODA转换和ezdxf回读不替代接收方CAD操作验收
首件/电气 | 工厂实物：未执行 强度稳定性、脚调节、门盖启闭及电气检验须实物完成

# 文件身份

### 同版文件与SHA-256以公开网页project.json和ZIP内交付清单.json为准；哈希仅用于核对下载完整性。R01原件和

## 顾客文件保留未覆盖。此版可供工厂按明确接口试制与复核，最终展开、承载稳定性、到货适配和电气首件均须 实际完成后放行。

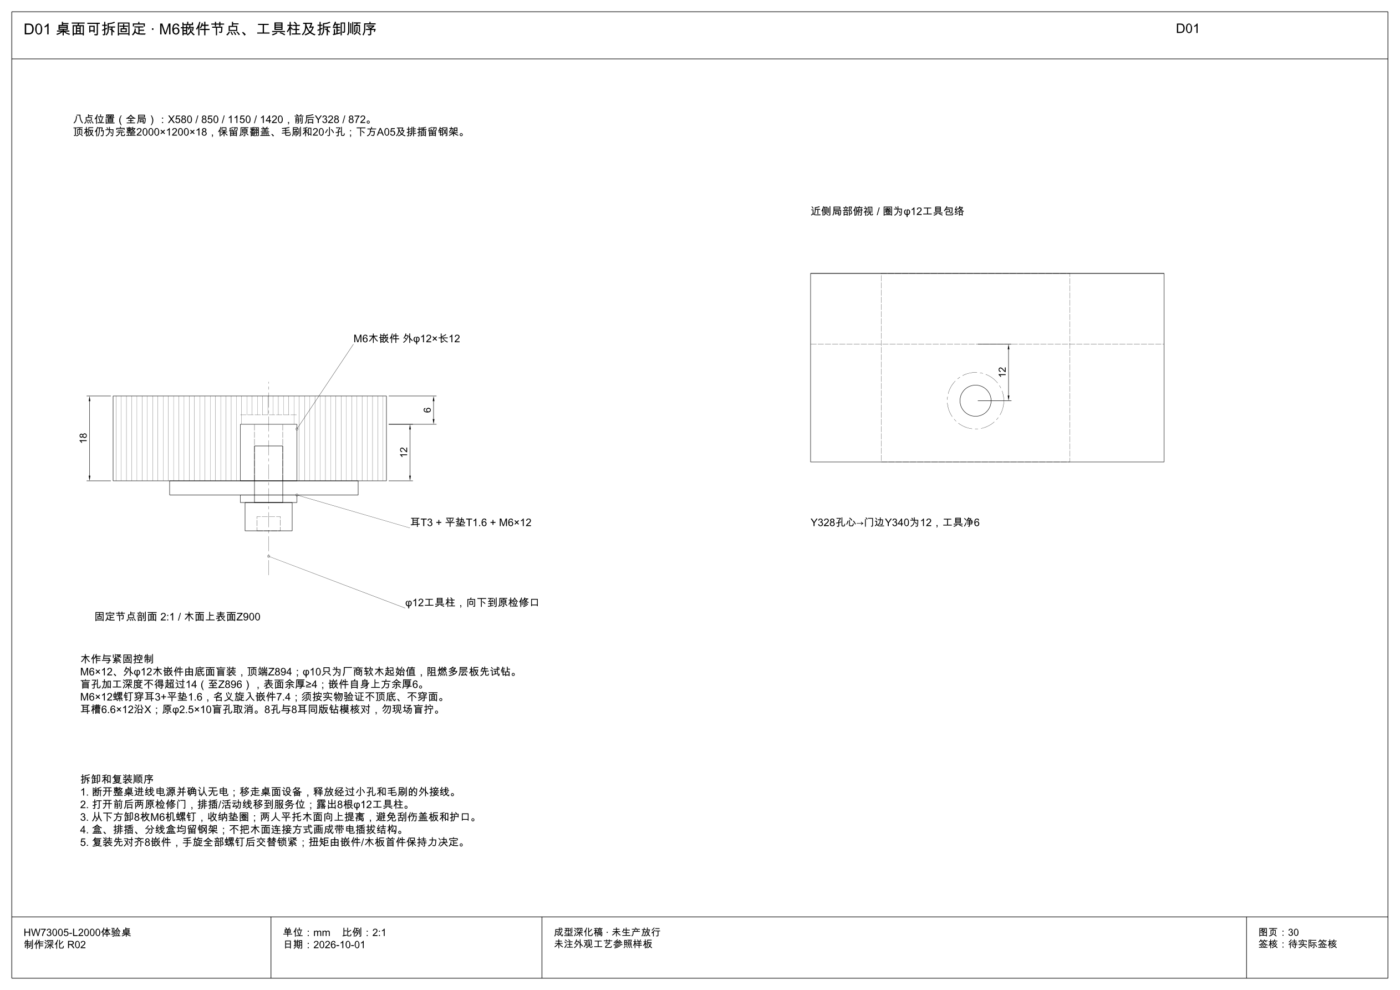
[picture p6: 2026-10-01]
hw73005-l2000/previews/R02/D01-page-30.png

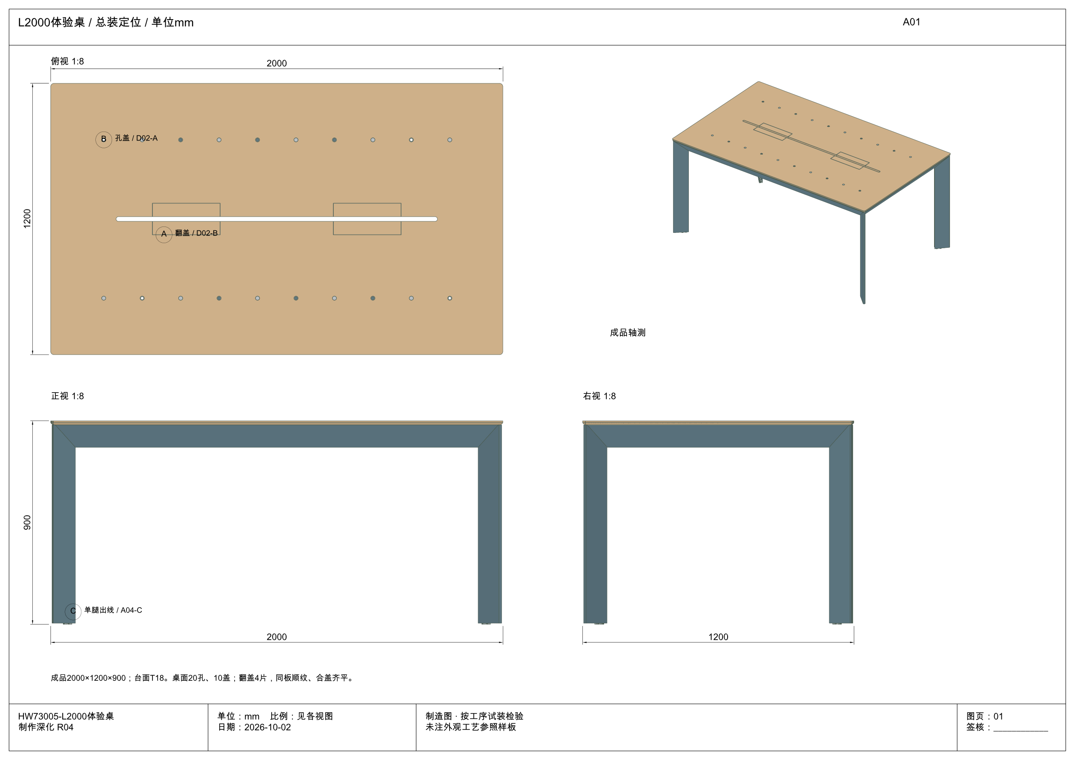
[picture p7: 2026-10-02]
hw73005-l2000/previews/R04/page-01.png

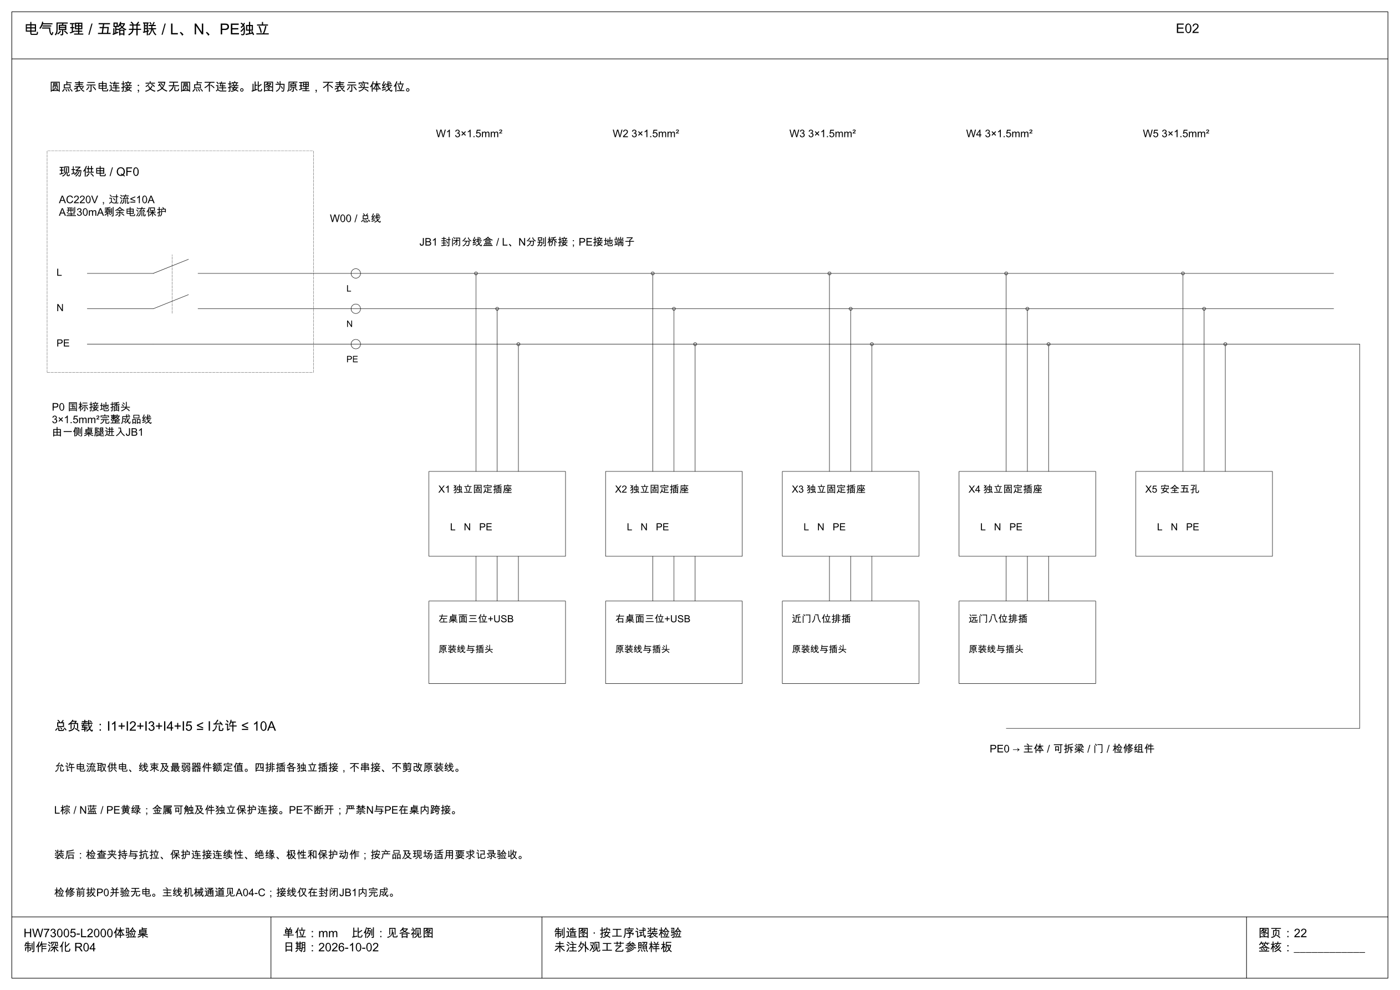
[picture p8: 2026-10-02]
hw73005-l2000/previews/R04/page-22.png

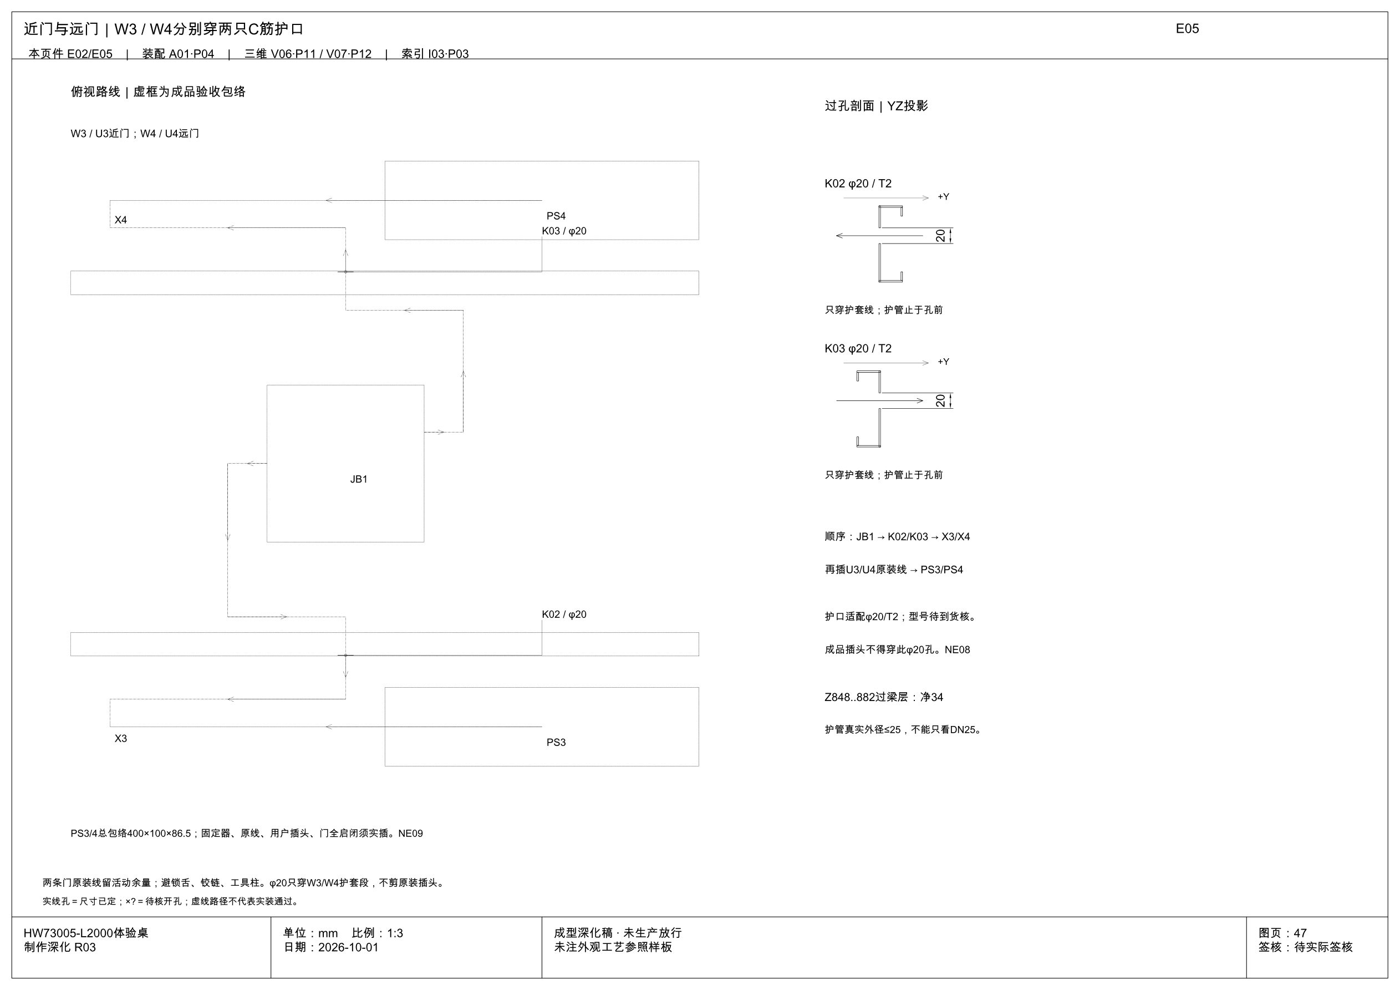
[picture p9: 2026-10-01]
hw73005-l2000/previews/R03/E05-page-47.png

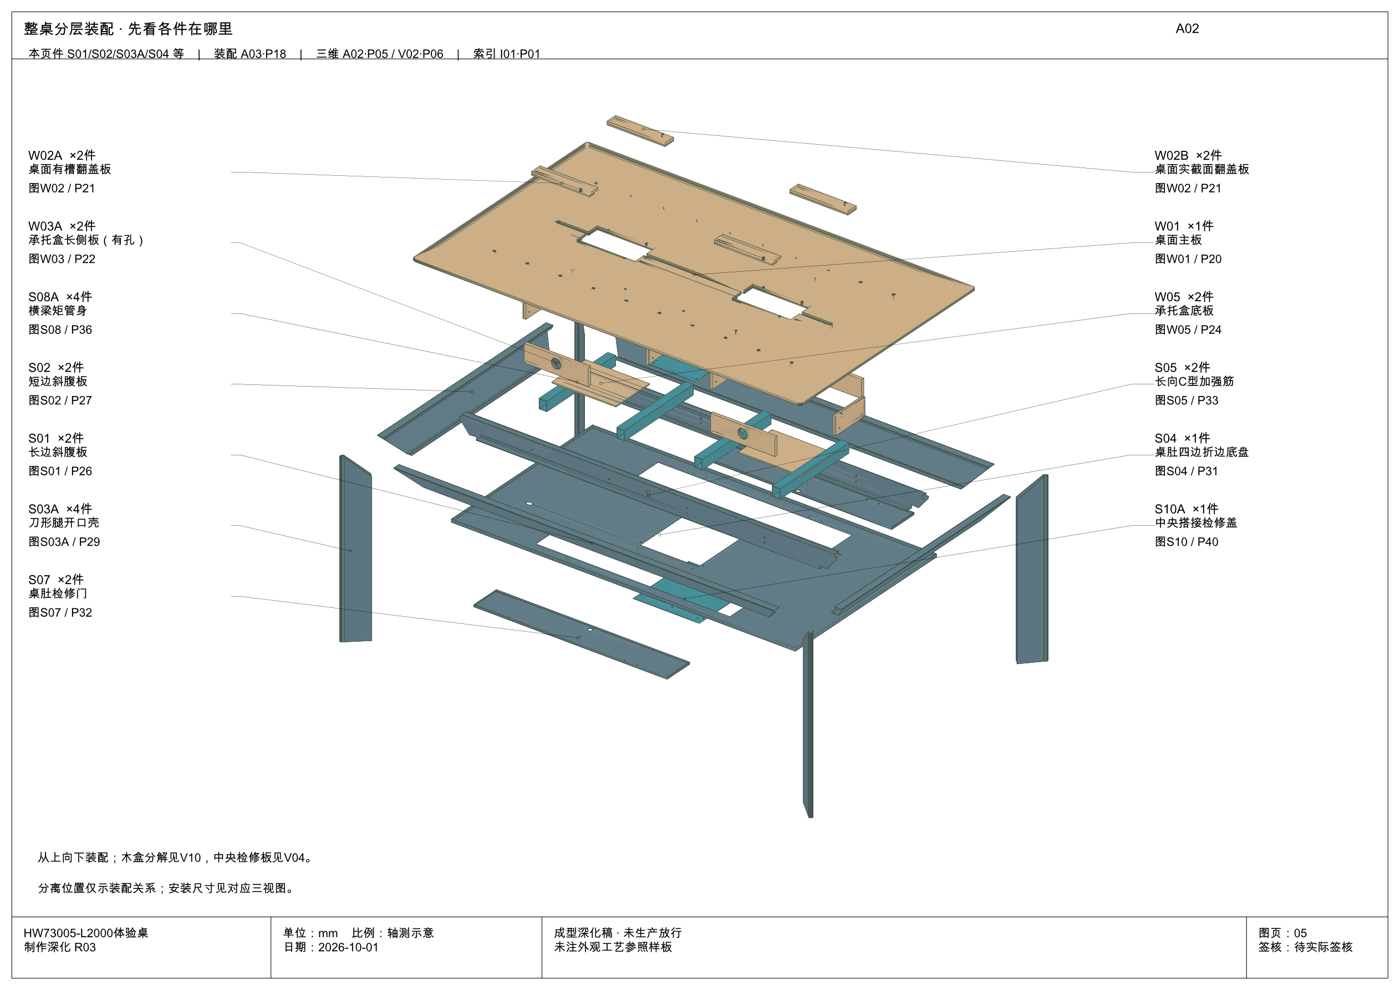
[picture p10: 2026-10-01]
hw73005-l2000/previews/R03/A02-page-05.png

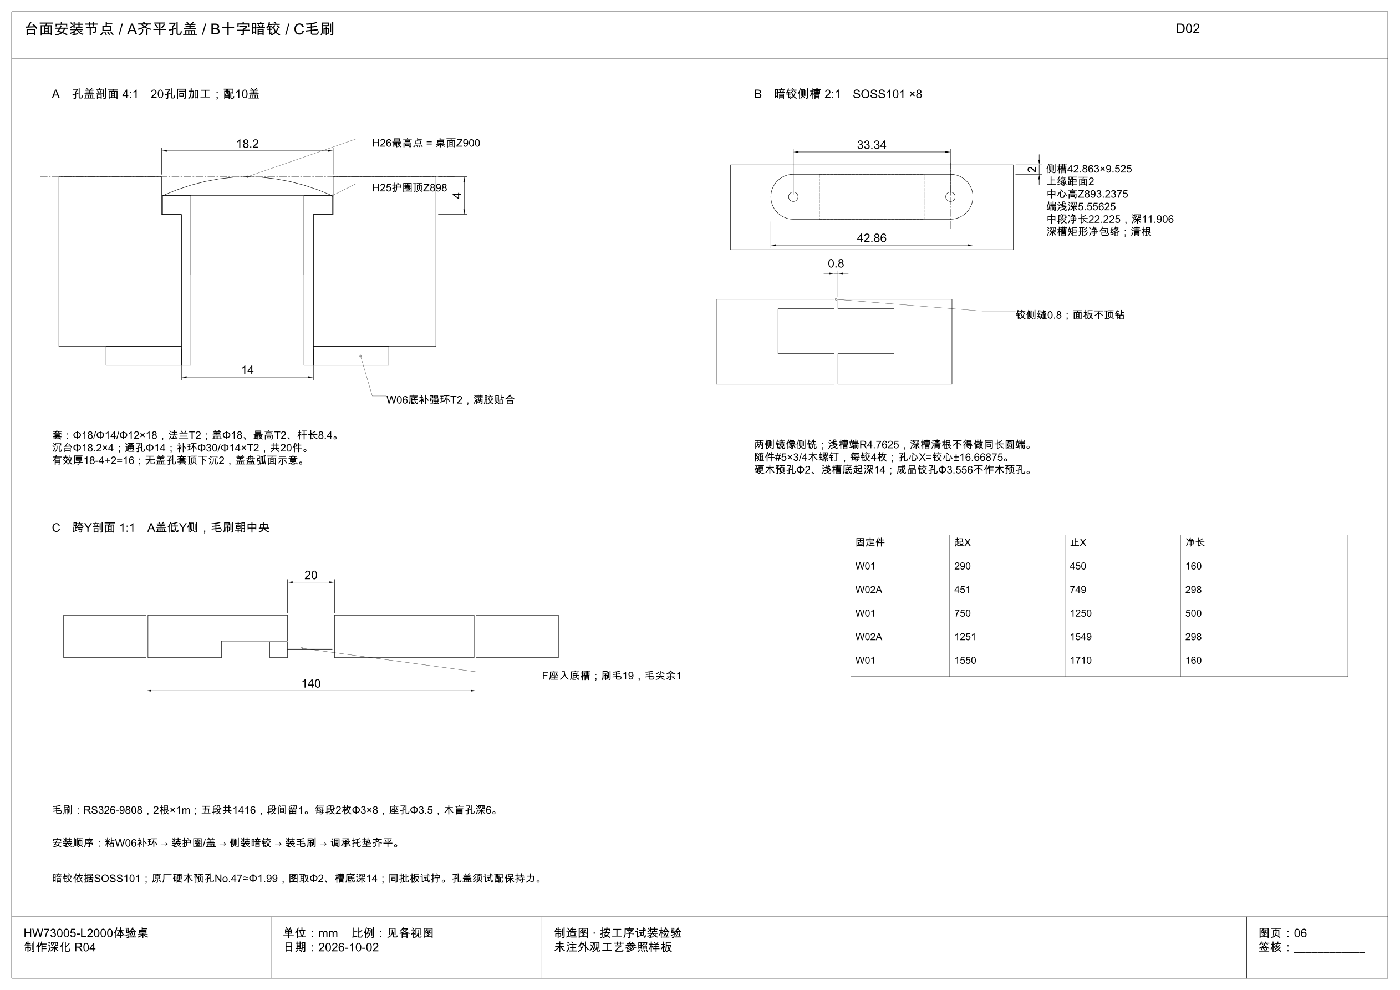
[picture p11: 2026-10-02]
hw73005-l2000/previews/R04/page-06.png

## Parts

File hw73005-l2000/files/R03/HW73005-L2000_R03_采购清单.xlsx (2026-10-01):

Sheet: 采购总表
五金与电气成品采购总表
HW73005-L2000 R03 核对日期 2026-10-01 成型深化稿，未生产放行
本批桌数 | 1
黄色格可改批量；空数量/空包装表示待核，不能当0。套内子件见“配套拆分”，可点击来源见“来源链接”。
件号 | 名称 | 类别 | 品牌 / 型号 | 所属装配 | 每桌用量 | 单位 | 本批用量 | 图号 | 包装量 | 包装单位 | 成品 / 已核规格 | 安装及待核条件 | 采购状态
H01 | 薄型调节脚 | 五金 | LAMP / Sugatsune；TG-20 | A07 | 8 | 只 | 8 | H02 |  |  | 底φ20；M8×1.25；螺杆长15；底高6；总高21 | S03C内沉1，脚底名义外露5；每腿2只；调节后复核整桌900高及螺纹搭接；S03C脚孔局部u80/110、v13.9665，孔距30 | 中国官方页有订购入口；库存未核
H02 | M8六角焊接螺母 | 五金 | 标准件；DIN 929 M8 钢本色 | S03C | 8 | 只 | 8 | H02 | 1 | 只 | M8×1.25；对边14；螺母厚6.5；定位凸台径10.45最大 | S03C定位孔φ10.5 H11；不能沿用原φ8.5；焊后通规检查 | 准确规格商品/可选规格页可网购；中国配送及实时库存未核
H03 | 检修门可脱卸合页 | 五金 | LAMP / Sugatsune；HG-OTA75 / 170-090-942 | S07 | 4 | 只 | 4 | H03 |  |  | 展开50×75×T1.5；4×φ3.8；孔距38×63.5；轴径6；厚向包络9.5 | 每门2只；孔中心相对铰链展开中心为(±19, ±31.75)；轴线方向沿75边；M3穿透连接 | 中国官方页有订购入口；库存未核
H04 | 直槽工具转舌锁（完整套件） | 五金 | 益升华恒珠 Hengzhu；MS705-1-1 | S07 | 2 | 套 | 2 | H03 |  |  | 面头φ28×4；开孔φ22.5与20.1方形交集；GH18；H19.5；锁舌35×20×T3（35为轴心至端） | 适门T1~5，含35长舌、螺母、止退件；锁头法兰贴门底Z782，末端接触面H19.5为Z801.5；S10E接收顶Z801.3留0.2，不能按近轴GH18定位接收面。锁舌扫掠留净。 | 国内厂家官方商城入口；须按完整套件型号订购并核库存
H05 | 排插滑拆固定器组 | 五金 | UGREEN 绿联；LP332 / 每组2套 | S07 | 2 | 组 | 2 | H01 |  |  | 每门2套滑拆固定器；包装尺寸99.5×45×9.2非工程外形 | GN-604背部与喷涂门内面平整清洁，按厂家胶粘并充分固化；每组2套同向滑轨；不钻排插壳。活动门倒置、抗滑脱和热老化未获厂家证明，须连同用户插头做启闭/抗拉首件验证。 | 厂家直链天猫成品；活动门应用为待验证候选
H06 | 承托盒白色穿线护口 | 五金 | Häfele；429.99.735 | W03A | 2 | 只 | 2 | H01 | 1 |  | φ50安装孔；两件式；经销规格入孔深22 | W03A长侧T15板φ50孔；局部u165/v51，全局(600/1400,492.5,842)，孔朝近侧-Y。筒向盒内突出约7；保持周围净空，按厂家允许压装或胶粘。可取盖穿原装插头，再恢复护口；开口及插头穿越须首件核实。 | 可网购具体型号；到货φ50孔配装及入孔深待复核
H07 | 小翻盖隐藏桶式铰链 | 五金 | SOSS；BH104 | A03 | 8 | 只 | 8 | H03 |  |  | 桶径10；盲孔φ10深11.5；孔心距朝开口边6.8；D≥2；E≤1.8；最小板厚12.7；开启180° | T18盖及桌面均从顶面钻φ10深11.5；剩板厚6.5。每盖u50/248、孔心距外侧开合边6.8；180°展开对应桌面闭合共面，操作抬90°。 | 厂家官网可加入购物车；中国现货和进口交期未核
H09 | 桌面M6机螺钉 | 五金 | 标准件；ISO 4762 / DIN 912 M6×12 | A03 | 8 | 只 | 8 | H02 | 1 | 只 | M6×1；公称杆长12；配平垫6.4×12×1.6 | 穿T3固定耳＋T1.6垫片，进入桌面嵌母7.4；由桌下拆装；成对点X580/850/1150/1420×Y328/872 | 准确规格商品/可选规格页可网购；中国配送及实时库存未核
H10 | 桌面M6木用嵌入螺母 | 五金 | RAMPA；SKD30 439612001 | W01 | 8 | 只 | 8 | H02 |  |  | 外径12；L12；内牙M6；内六角SW6；厂家底孔10.0~10.5 | 从桌面底安装；试样底孔φ10.5深14、面层最小保留4；嵌件法兰与底面齐，深度限位钻孔 | 厂家官网可在线订购；中国现货和进口交期未核
H11 | M6平垫圈 | 五金 | 标准件；ISO 7089 / DIN 125-A 6 | A03 | 8 | 只 | 8 | H02 | 1 | 只 | φ6.4×φ12×T1.6 | 与8只M6×12配套；覆盖6.6×12长圆调节孔 | 准确规格商品/可选规格页可网购；中国配送及实时库存未核
H12 | 检修门合页螺钉配套 | 五金 | 标准件；M3×8盘头＋M3防松螺母＋M3平垫 | S07 | 16 | 套 | 16 | H03 |  |  | M3×0.5×8；每合页4套 | 穿φ3.8合页孔与门/底盘配孔；每套1螺钉1平垫1防松螺母；组装后验轴芯可操作 | 准确规格商品/可选规格页可网购；中国配送及实时库存未核
H13 | 检修盖及吊板防脱螺钉 | 五金 | NBK；SSC-M5-8 | A04 | 8 | 只 | 8 | H02 |  |  | M5×0.8；杆长8；末端牙长4；颈径3.9；头φ8.5×5；内六角4 | 中央盖4：T1.5攻M5防脱＋T1底盘＋T2补强＋DIN929 M5，夹紧栈4.5，啮合3.5。吊板4：T2攻M5防脱＋T3臂＋DIN929 M5，夹紧栈5，啮合3。 | NBK中国官方询价/官方1688渠道；库存未核
H25 | 成品过线衬套 | 五金 | LAMP / Sugatsune；CHC-S18BL | A06 | 20 | 只 | 20 | A06 | 1 | 只 | 外缘φ18；嵌入φ14；内孔φ12；总高18；法兰高2 | W01孔φ14+0.5/0；按桌面/设备过线设计装20只；衬套面高出桌面2 | 厂家美国官网可按只加购物车；中国配送和库存未核
H26 | 闲置孔成品盖 | 五金 | Häfele；045.00.332 | A06 | 10 | 只 | 10 | A06 | 500 | 只 | 适φ12孔；头φ18；H2；插杆8.4 | 装入CHC-S18BL内φ12；组合总突出约4；首件实配通过前不得当认证配套 | 国外经销商网购500只/包；单桌用10只，中国配送及实时库存未核
H14 | 检修盖及吊板M5焊接螺母 | 五金 | 标准件；DIN929 M5 钢本色 | A04 | 8 | 只 | 8 | H02 | 1 | 只 | M5×0.8；对边10；厚4；定位凸台6.96最大 | 盖T2补强片或吊板T3臂均φ7 H11定位后焊；盖4、板4；对应SSC-M5-8。 | 准确规格商品/可选规格页可网购；中国配送及实时库存未核
H15 | 横梁M6连接螺钉配套 | 五金 | 标准件；ISO4762 M6×20＋ISO7089平垫6 | S09A | 16 | 套 | 16 | H02 |  |  | M6×20；头下垫6.4×12×T1.6；每套各1 | C筋T2＋每螺栓4mm调整片＋S09A T3端板＋DIN929M6；每端2点，共16套。 | 准确规格商品/可选规格页可网购；中国配送及实时库存未核
H16 | 横梁M6焊接螺母 | 五金 | 标准件；DIN929 M6 钢本色 | S09A | 16 | 只 | 16 | H02 | 100 | 只 | M6×1；对边11；厚5；定位凸台7.96最大 | S09A T3端板φ8 H11；焊母朝管腔；孔心(30,18)/(30,42) | 准确规格商品/可选规格页可网购；中国配送及实时库存未核
H17 | 承托盒M4连接螺钉配套 | 五金 | 标准件；M4×25＋M4平垫 | S09C | 8 | 套 | 8 | H02 |  |  | M4×25；每套1螺钉1平垫 | 轴水平X；穿木板φ4.5后入抱角焊母 | 准确规格商品/可选规格页可网购；中国配送及实时库存未核
H18 | 承托盒M4焊接螺母 | 五金 | 标准件；DIN929 M4 钢本色 | S09C | 8 | 只 | 8 | H02 | 1 | 只 | M4×0.7；对边9；厚3.5；定位凸台5.97最大 | T2抱角φ6 H11定位焊；与M4×25配套 | 准确规格商品/可选规格页可网购；中国配送及实时库存未核
H19 | 翻盖独立承托角码 | 五金 | LAMP / Sugatsune；SU-30S / 120-030-070 | A03 | 8 | 只 | 8 | H03 |  |  | 30×30×宽12×T2.5；4×φ3.5沉φ6.5；两面孔距直角基准11/24 | 每盖两短端各1只；角码钢顶Z882−实测含胶软垫厚（名义879.77）；X450..480/720..750及+800；Y中心552/648 | 成品或标准件可订购；未下单、实时库存未核
H20 | 角码木螺钉 | 五金 | Wovar；WV007880 / φ3×12沉头TX10 | A03 | 16 | 只 | 16 | H03 | 200 | 只 | 每角码竖面2只；杆φ3、长12 | 经T2.5角码横向入T15板约9.5；预钻孔径按实际木料试样，深度限位 | 准确规格商品/可选规格页可网购；中国配送及实时库存未核
H21 | 角码软垫 | 五金 | Fugendichtband24；100191 / EAN4260627935185 | A03 | 8 | 片 | 8 | H03 | 1 | 片200×300 | 实心EPDM片200×300×T2，胶另约0.22~0.24；裁8片24×12 | 含胶名义2.23；按实测总厚定位角码钢顶Z882−实测厚，使软垫顶882 | 德国厂家网店可下单1片；国内配送和库存未核
B01 | 成品毛刷条 | 五金 | RS PRO；RS PRO 326-9808 | A03 | 2 | 根 | 2 | H01 | 1 | 根 | 每根1000；尼龙毛长19；F型铝座；截面总26.5、座6.7×6.7 | 切160+298+500+298+160=1416；4处1缝合计覆盖1420；低Y侧28×7槽，刷毛向+Y，尖端留1 | 成品或标准件可订购；未下单、实时库存未核
B03 | 毛刷固定木螺钉 | 五金 | QUARKZMAN；000338aa230623qmaneu / φ3×8 | A03 | 10 | 只 | 10 | H01 | 100 | 只 | 每毛刷段2枚；5段共10枚 | 成品铝型材自配φ3.5孔；不得把型材截面剪短；木板槽后余厚11，限深避免穿面 | 准确规格商品/可选规格页可网购；中国配送及实时库存未核
H22 | 横梁调整垫片 | 五金 | WKOOA；W29338 / DIN988 6×12×1 | S09A | 64 | 片 | 64 | H02 | 100 | 片 | 内径6、外径12、厚1；每个螺栓4片叠为4 | 16个M6螺栓位置×4片=64；每端2螺栓8片；使478总长梁装入486内净距 | 厂家网店100片/包可加入购物车；国内配送和库存未核
H23 | 检修盖及吊板防坠索 | 五金 | Elesa+Ganter；GN111.2-150-C-BL | A04 | 4 | 根 | 4 | H01 | 1 | 根 | 钢索φ1.6；索环根间150；两端片孔φ5.3、宽14、T1.5；拉直孔心距约183 | 盖2根、吊板2根；载板平差X40/Y20、初始Z差2，下放约175.45；盖竖挂平差10、上下差182.73；有效长度按实物核 | 经销网店可加入购物篮但页面无现货；须核交期及中国配送
H24 | 防坠索端片紧固配套 | 五金 | 标准件；ISO7045 M4×16＋2×DIN9021 M4＋DIN985 M4 | A04 | 8 | 套 | 8 | H01 |  |  | 每套1盘头螺钉、2大垫φ4.3×12×T1、1防松母；M4母总高5 | 悬臂螺钉从上向下，头＋上垫最大4.25；端片直接贴钢件下侧，下垫及防松母夹紧；木底净0.75 | 螺钉准确型号可网购；套内垫圈与螺母分购，国内配送及库存未核
E01 | 桌面三位五孔+3USB排插 | 电气 | 公牛UU3653（候选） | A04 | 2 | 个 | 2 | E06 |  |  | 厂家官网：3个五孔AC，1USB-A+2USB-C，USB最大输出65W | AC额定值、到货外包、原装线规格、同时插3只用户插头时翻盖净空；若样板要求3个USB-A，本型号不等同，仍须换配 | 端口数量符合3USB概念；非3USB-A；机电外包待核
E02 | 桌肚八位五孔排插 | 电气 | 公牛GN-604（候选） | S07 | 2 | 个 | 2 | E05 |  |  | 厂家官网8位，最大10A，250V，过载保护，3m/5m原装线 | 本体外包、固定器、绕线余量及门启闭干涉 | 孔位数与接口额定可核，外形待实物
E03 | 明装安全五孔插座 | 电气 | 正泰NEW1-C11100A（采购候选） | A01 | 1 | 个 | 1 | E01 |  |  | 可检索到明装五孔销售型号 | 未取得完整厂家安装图、接线端子图与到货CCC证书；不锁定孔距和外包 | 仅采购候选，不以商城文案作电气安装证据
E07 | 中央成品分线盒与内板 | 电气 | Hammond1557HA2GY箱体＋1557HPL内板各1 | S10B | 1 | 套 | 1 | E04 |  |  | 箱体外包200×200×70；另购1557HPL原厂内板，工程图外182×182、T2.05、4φ4孔距170；网页187规格概略不作加工依据。 | R03内板操作面Z862为安装设计；原盒内柱高度/紧固件和内盖真实净距首件核；改孔后不宣称IP68。 | 主选，裸盒外包已核
E08 | 排插独立固定分支插座 | 电气 | 公牛GN-N1110或同级带保护门单插座（候选） | A01 | 4 | 只 | 4 | E01 |  |  | 厂家GN-N1110为自接线10A/250V、1+1插口、防拉脱，原装插头可插入 | 固定安装方法、外包和完整CCC/接线说明；到货后用绝缘固定支架，无厂家许可不得钻穿壳体 | X1~X4隐藏分支插座；不得用四位排插替代星形固定分线
E09 | C14电源入口 | 电气 | SCHURTER6100.3300 C14电源入口 | A01 | 1 | 只 | 1 | E04 |  |  | C14，IEC10A/250V，6.3×0.8快接，螺钉固定，原厂含尺寸图 | 中国适用认证和到货同版外形；后罩另列E18、快接E19、紧固E20。 | X0安装接口候选，禁止按UL15A当中国10A接口升级
E10 | 国标10A/C13成品电源线 | 电气 | 百格/亿晟PSB-10W—C13-10W成品线，订3×1.5mm² | A01 | 1 | 条 | 1 | E04 |  |  | 厂家列国标双头线、10A/250V、3×0.75~1.5、长度可定 | 选定1.5版本的完整CCC证书和绝缘外径；网购成品替代可核广昌兴PCC311331D51003，但商城参数不替代厂家证书 | 主选3×1.5完整成品；SCHURTER6051.2032虽CCC但3×1.0不符合本项目线径，已排除
E11 | L灰色直通端子 | 电气 | WAGO2002-1201 | A01 | 6 | 只 | 6 | E03 |  |  | 灰色2.5mm²导轨直通端子，单电位，适用DIN35×7.5 | XL0~5；端子与电流/导线厂家数据复核后实施 | XL0~5；端子与电流/导线厂家数据复核后实施
E12 | N蓝色直通端子 | 电气 | WAGO2002-1204 | A01 | 6 | 只 | 6 | E03 |  |  | 蓝色2.5mm²导轨直通端子，单电位，适用DIN35×7.5 | XN0~5；与L分隔、不同色 | XN0~5；与L分隔、不同色
E13 | 黄绿PE端子 | 电气 | WAGO2002-1207 | A01 | 7 | 只 | 7 | E03 |  |  | 黄绿2.5mm²专用PE端子，适用DIN35×7.5 | XPE0~6；连续导轨、接地脚与PE0导通须验证 | XPE0~6；连续导轨、接地脚与PE0导通须验证
E14 | 六位连续跨接桥 | 电气 | WAGO2002-406 | A01 | 2 | 根 | 2 | E03 |  |  | 6位连续跨接桥，厂家2002系列配套 | L/N各一根；严禁错购/020-000三对独立桥 | L/N各一根；严禁错购/020-000三对独立桥
QF0 | 施耐德A9D32610（外部保护候选） | 电气 | 施耐德A9D32610（外部保护候选） |  |  | 待定 |  |  |  |  | 官方10A、1P+N、C曲线、6kA、30mA、TypeA；可隔离L/N | 本地适用认证、曲线/分断能力/上游选择性及外部箱体；某市场已替代，不锁定采购 | 现场边界内候选，不计已装件、不假定现场已具备
E18 | C14原厂绝缘后罩 | 电气 | SCHURTER RC320-03，3-125-663 | A01 | 1 | 只 | 1 | E04 |  |  | 原厂列适配6100-3；尺寸31.2×23.5×51，出线口内径8.5、外颈径11.5。 | 主选原厂后罩；销售页支持订购但未称现货，安装全罩合与线径首件核定 | 主选原厂后罩；销售页支持订购但未称现货，安装全罩合与线径首件核定
E19 | 全绝缘快接母端 | 电气 | TE Connectivity735278 | A01 | 3 | 只 | 3 | E04 |  |  | 全绝缘母快接6.35×0.81，适1~1.5mm²，直型长21.6，导体绝缘径≤3.3，尼龙绝缘。 | L/N/PE各1只；厂家配套工具压接及拉脱验收 | L/N/PE各1只；厂家配套工具压接及拉脱验收
E20 | C14入口固定紧固件 | 电气 | M3×8沉头螺钉、平垫、防松螺母 | A01 | 2 | 套 | 2 | E04 |  |  | 按SCHURTER6100.3300厂家2×φ3.5固定孔及沉孔配置。 | 两套入口固定件；实际叠厚和尾端突出量首件核定，不作PE连接 | 两套入口固定件；实际叠厚和尾端突出量首件核定，不作PE连接
E21 | 中央组件柔性PE线 | 电气 | 黄绿柔性铜芯PE线2.5mm² | A01 | 2 | 根 | 2 | E03 |  |  | S10A与S10B各1条独立回固定钢架；截面为R02设计值，长度待实测。 | 活动线材按厂家允许弯曲条件选配；250维护余量不当作总领料长度 | 活动线材按厂家允许弯曲条件选配；250维护余量不当作总领料长度
E22 | 中央PE移动端M4环端子 | 电气 | JST FV2-4 | A01 | 2 | 只 | 2 | E03 |  |  | M4环端，厂家适线1.04~2.63mm²；匹配2.5mm²移动端。 | 两根中央PE各1只；依厂家工具压接 | 两根中央PE各1只；依厂家工具压接
E23 | 中央PE固定端M5环端子 | 电气 | JST FV2-5 | A01 | 2 | 只 | 2 | E03 |  |  | M5环端，厂家适线1.04~2.63mm²；匹配2.5mm²固定端。 | 两根中央PE各1只；PE0预留两环端可靠夹持空间，禁止无限叠端 | 两根中央PE各1只；PE0预留两环端可靠夹持空间，禁止无限叠端
E24 | 中央组件PE专用紧固件 | 电气 | M4×10螺钉、平垫、齿形垫、防松螺母 | A01 | 2 | 套 | 2 | E03 |  |  | 配S10A孔(1000,450)、S10B孔(1000,460)，两孔φ4.5为R02结构接口。 | 每移动组件1套，螺纹向上；去漆、防松并测连续性，PE不兼吊线 | 每移动组件1套，螺纹向上；去漆、防松并测连续性，PE不兼吊线
E06 | 绝缘套管及线号配套 | 电气 | 永久线号、绝缘套管配套 | A01 | 1 | 套 | 1 | E03 |  |  | W00/W1~W5两端线号、L/N/PE颜色与端子号；按实测裁切热缩或黄腊管，只作附加绝缘。 | 数量按接线点配足，不重复采购E11~E14端子或跨接桥；实际套管内径按导体和端头外包确定 | 数量按接线点配足，不重复采购E11~E14端子或跨接桥；实际套管内径按导体和端头外包确定
E15 | 导轨端挡与绝缘端板 | 电气 | WAGO210-112导轨、249-116端挡2只、2002-1291端/隔板3只 | A01 | 1 | 套 | 1 | E03 |  |  | DIN35×7.5长150；19端子宽98.8＋端挡2×6＋隔板3×0.8＝113.2，轨两端各余18.4；箱内排序见terminalLayout。 定型210-112为35×7.5、T1、EN60715；采购2m一支截150，腰宽/R/槽孔模板仍按厂家实物。 | 端挡2、L/N/PE每组闭合侧各1板；导轨须连续并与PE端子可靠连接；不把端挡当接地件 | 端挡2、L/N/PE每组闭合侧各1板；导轨须连续并与PE端子可靠连接；不把端挡当接地件
E16 | 金属件保护连接配套 | 电气 | 固定钢组/三梁/两门7条黄绿2.5mm²跨接与端头紧固包 | A01 | 1 | 套 | 1 | E03 |  |  | 7条线分别为XPE6→PE0、PE0→焊接主框架、其余3根螺接梁→主框架、两活动门→主框架；JST FV2-5 11只、FV2-4 2只，WAGO侧1端用Phoenix3202533（AI2.5-10BU）冷压套管，不另算环端。 | 线长待实测；10柱及指定叠层已落钢图，焊接保持力/防松/PE连续性首件核验；与中央E21~E24去重。 | 线长待实测；10柱及指定叠层已落钢图，焊接保持力/防松/PE连续性首件核验；与中央E21~E24去重。
E04 | 三芯内部分支线束 | 补充采购 | 3×1.5mm²；W00/W1~W5 | A01 |  | m |  | E01 |  |  | 3×1.5mm²；W00/W1~W5 | W00外径≤8.5且厂家静态弯曲半径≤30；活动段另核；不剪改排插原线 | 长度待实测；未填0或估算领料
E05 | 桌肚过线保护管 | 补充采购 | 实际外径≤25；本版过梁层净34 | A01 |  | m |  | E05 |  |  | 实际外径≤25；本版过梁层净34 | 源≥25管须核外径，DN25不等于外径25；不进入桌腿 | 长度待实测；未填0或估算领料
E17 | 进线与线束固定护口配套 | 补充采购 | 适配线径的成品线夹/防拉脱件 | A01 | 1 | 套 | 1 | E04 |  |  | 适配线径的成品线夹/防拉脱件 | X0独立夹护套；后罩/快接不抗拉；不破坏原装护套 | 数量与接口已定；产品适用认证/到货模板/实物验收待核

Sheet: 配套拆分
组合紧固件与接地包拆分
HW73005-L2000 R03 核对日期 2026-10-01 成型深化稿，未生产放行
本批桌数 | 1
本表子项已包含在采购总表父级内，不能与父级套件叠加计数；建议包数只在包装量已知时计算。
子项编号 | 父级套件 | 独立采购规格 | 每桌用量 | 单位 | 本批用量 | 每包装量 | 建议包数 | 计数 / 裁切说明
H05.1 | H05 | LP332 | 4 | 只 | 4 |  |  | 每套2×2套；；；

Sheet: 来源链接
厂家技术依据与购买页面
HW73005-L2000 R03 核对日期 2026-10-01 成型深化稿，未生产放行
本批桌数 | 1
技术来源用于型号/尺寸核对，购买页面用于采购入口；官方首页入口不等同现货。仅有技术链接的条目仍需锁定购买SKU。
对应编号 | 来源类型 | 可点击链接 | 已核事实 / 边界 | 完整URL（复制用）
H01 | 技术依据 | 打开 global.sugatsune.com (https://global.sugatsune.com/cn/zh-cn/tech/products/22772_t) | PDF第22页（目录页662） | https://global.sugatsune.com/cn/zh-cn/tech/products/22772_t
H01 | 厂家附加来源 | 打开 www.sugatsune.com (https://www.sugatsune.com/content/page-files/product-literature/catalog-201c-641-667-casters-and-leveling-glides.pdf) | PDF第22页（目录页662） | https://www.sugatsune.com/content/page-files/product-literature/catalog-201c-641-667-casters-and-leveling-glides.pdf
H01 | 购买页面 | 打开 global.sugatsune.com (https://global.sugatsune.com/cn/zh-cn/tech/products/22772_t) | PDF第22页（目录页662） | https://global.sugatsune.com/cn/zh-cn/tech/products/22772_t
H02 | 技术依据 | 打开 www.nufast.co.uk (https://www.nufast.co.uk/uploads/DIN_929.pdf) | 第1页M8行 | https://www.nufast.co.uk/uploads/DIN_929.pdf
H02 | 厂家附加来源 | 打开 eshop-sk.boellhoff.com (https://eshop-sk.boellhoff.com/out/media/pdf/DIN_929_Stahl___en.pdf) | 第1页M8行 | https://eshop-sk.boellhoff.com/out/media/pdf/DIN_929_Stahl___en.pdf
H02 | 购买页面 | 打开 www.orbitalfasteners.co.uk (https://www.orbitalfasteners.co.uk/products/m8-mild-steel-hexagon-we-ld-nut-self-colour) | 第1页M8行 | https://www.orbitalfasteners.co.uk/products/m8-mild-steel-hexagon-we-ld-nut-self-colour
H03 | 技术依据 | 打开 global.sugatsune.com (https://global.sugatsune.com/cn/zh-cn/tech/products/21654_t?category=100218) | 第1页下半HG-OTA75 | https://global.sugatsune.com/cn/zh-cn/tech/products/21654_t?category=100218
H03 | 厂家附加来源 | 打开 www.sugatsune.com (https://www.sugatsune.com/content/site-assets/501_PDF/HG-OT.pdf) | 第1页下半HG-OTA75 | https://www.sugatsune.com/content/site-assets/501_PDF/HG-OT.pdf
H03 | 购买页面 | 打开 global.sugatsune.com (https://global.sugatsune.com/cn/zh-cn/tech/products/21654_t?category=100218) | 第1页下半HG-OTA75 | https://global.sugatsune.com/cn/zh-cn/tech/products/21654_t?category=100218
H04 | 技术依据 | 打开 www.hengzhu.com (https://www.hengzhu.com/cn/product/587/Locks/MS705) | 官方当前尺寸图上半MS705-1-1 | https://www.hengzhu.com/cn/product/587/Locks/MS705
H04 | 厂家附加来源 | 打开 www.hengzhu.com (https://www.hengzhu.com/upload/image/20250827/1756267038328022627.jpg) | 官方当前尺寸图上半MS705-1-1 | https://www.hengzhu.com/upload/image/20250827/1756267038328022627.jpg
H04 | 购买页面 | 打开 www.hengzhu.com (https://www.hengzhu.com/cn/static/mall-shop) | 官方当前尺寸图上半MS705-1-1 | https://www.hengzhu.com/cn/static/mall-shop
H05 | 技术依据 | 打开 www.lulian.cn (https://www.lulian.cn/product/751-cn.html) | 不把包装尺寸充当外形；承载额定、装配外包、店铺实时库存未核。 | https://www.lulian.cn/product/751-cn.html
H05 | 购买页面 | 打开 detail.tmall.com (https://detail.tmall.com/item.htm?id=630347182725) | 不把包装尺寸充当外形；承载额定、装配外包、店铺实时库存未核。 | https://detail.tmall.com/item.htm?id=630347182725
H06 | 技术依据 | 打开 www.hafele.com (https://www.hafele.com/INTERSHOP/static/WFS/Haefele-HAC-Site/-/Haefele-HAC/en_US/opentext/assets/hac/Closet_Catalog_2022.pdf) | 目录129页；白色φ50型号表。深度22见经销规格，完整安装图待核。 | https://www.hafele.com/INTERSHOP/static/WFS/Haefele-HAC-Site/-/Haefele-HAC/en_US/opentext/assets/hac/Closet_Catalog_2022.pdf
H06 | 购买页面 | 打开 www.wurthmachinery.com (https://www.wurthmachinery.com/50mm-Cable-Grommet-with-Spring-Loaded-White.html) | 目录129页；白色φ50型号表。深度22见经销规格，完整安装图待核。 | https://www.wurthmachinery.com/50mm-Cable-Grommet-with-Spring-Loaded-White.html
H07 | 技术依据 | 打开 www.soss.com (https://www.soss.com/product/barrel-hinge/) | 尺寸图第1页；安装说明第2页BHC104行 | https://www.soss.com/product/barrel-hinge/
H07 | 厂家附加来源 | 打开 www.soss.com (https://www.soss.com/wp-content/uploads/2015/04/SOSS_BH104R.pdf) | 尺寸图第1页；安装说明第2页BHC104行 | https://www.soss.com/wp-content/uploads/2015/04/SOSS_BH104R.pdf
H07 | 购买页面 | 打开 www.soss.com (https://www.soss.com/product/barrel-hinge/) | 尺寸图第1页；安装说明第2页BHC104行 | https://www.soss.com/product/barrel-hinge/
H09 | 技术依据 | 打开 www.nbk1560.com (https://www.nbk1560.com/en-US/products/specialscrew/nedzicom/socketheadcapscrew/SNS/) | 8点为R02设计数量；拧紧扭矩按实际阻燃多层板试验，不能套用钢连接满扭矩。 | https://www.nbk1560.com/en-US/products/specialscrew/nedzicom/socketheadcapscrew/SNS/
H09 | 购买页面 | 打开 www.f-e-s.co.uk (https://www.f-e-s.co.uk/m6-x-12-socket-cap-screws-grade-12-9-zinc-plated-din-912.html) | 8点为R02设计数量；拧紧扭矩按实际阻燃多层板试验，不能套用钢连接满扭矩。 | https://www.f-e-s.co.uk/m6-x-12-socket-cap-screws-grade-12-9-zinc-plated-din-912.html
H10 | 技术依据 | 打开 www.rampa.com (https://www.rampa.com/eu/en/rampa-inserts-type-skd30/439612001010) | 第1页439 612 001行 | https://www.rampa.com/eu/en/rampa-inserts-type-skd30/439612001010
H10 | 厂家附加来源 | 打开 www.rampa.com (https://www.rampa.com/na/en/rampadownloads/092e80313dbe48e18b4c28e5343939fe) | 第1页439 612 001行 | https://www.rampa.com/na/en/rampadownloads/092e80313dbe48e18b4c28e5343939fe
H10 | 购买页面 | 打开 www.rampa.com (https://www.rampa.com/eu/en/rampa-inserts-type-skd30/439612001010) | 第1页439 612 001行 | https://www.rampa.com/eu/en/rampa-inserts-type-skd30/439612001010
H11 | 购买页面 | 打开 www.mofakult.fr (https://www.mofakult.fr/en/washer-m6-6-4-12-1-6-galvanized-29733) | 不要用不同厚度弹垫替代，否则有效啮合长度变化。 | https://www.mofakult.fr/en/washer-m6-6-4-12-1-6-galvanized-29733
H12 | 购买页面 | 打开 www.vital-parts.co.uk (https://www.vital-parts.co.uk/phillips-pan-head-machine-screws-din-7985h/17017-pph7985h-m3-8-a2) | 合页叶片T1.5＋门T1.5（或支撑板）；M3×8避免长端侵入活动区。 | https://www.vital-parts.co.uk/phillips-pan-head-machine-screws-din-7985h/17017-pph7985h-m3-8-a2
H13 | 技术依据 | 打开 www.nbk1560.com (https://www.nbk1560.com/en-US/products/specialscrew/nedzicom/captivescrew/SSC/SSC-M5/SSC-M5-8/) | 第1页M5及安装示意 | https://www.nbk1560.com/en-US/products/specialscrew/nedzicom/captivescrew/SSC/SSC-M5/SSC-M5-8/
H13 | 厂家附加来源 | 打开 www.nbk1560.com (https://www.nbk1560.com/images/en/product/captivescrew/SSC/SSC_1.pdf) | 第1页M5及安装示意 | https://www.nbk1560.com/images/en/product/captivescrew/SSC/SSC_1.pdf
H13 | 购买页面 | 打开 www.nbk1560-chn.com.cn (https://www.nbk1560-chn.com.cn/products/specialscrew/nedzicom/captivescrew/SSC/) | 第1页M5及安装示意 | https://www.nbk1560-chn.com.cn/products/specialscrew/nedzicom/captivescrew/SSC/
H25 | 技术依据 | 打开 www.sugatsune.com (https://www.sugatsune.com/content/site-assets/201B_PDF/CHC-S.pdf) | 第1页CHC-S18BL行 | https://www.sugatsune.com/content/site-assets/201B_PDF/CHC-S.pdf
H25 | 厂家附加来源 | 打开 www.sugatsune.com (https://www.sugatsune.com/content/site-assets/201B_PDF/CHC-S.pdf) | 第1页CHC-S18BL行 | https://www.sugatsune.com/content/site-assets/201B_PDF/CHC-S.pdf
H25 | 购买页面 | 打开 www.sugatsune.com (https://www.sugatsune.com/split-cable-grommet-chc-s18bl/) | 第1页CHC-S18BL行 | https://www.sugatsune.com/split-cable-grommet-chc-s18bl/
H26 | 技术依据 | 打开 hafelethailand.com (https://hafelethailand.com/wp-content/uploads/2025/12/13-Tooling-Screws-and-Consumables.pdf) | PDF第35页（FF13.35）045.00.332 | https://hafelethailand.com/wp-content/uploads/2025/12/13-Tooling-Screws-and-Consumables.pdf
H26 | 厂家附加来源 | 打开 hafelethailand.com (https://hafelethailand.com/wp-content/uploads/2025/12/13-Tooling-Screws-and-Consumables.pdf) | PDF第35页（FF13.35）045.00.332 | https://hafelethailand.com/wp-content/uploads/2025/12/13-Tooling-Screws-and-Consumables.pdf
H26 | 购买页面 | 打开 www.ungrund.store (https://www.ungrund.store/OE-12mm-Abdeckkappe-fuer-Blindbohrung-tiefschwarz-VE-500/PID426816.1) | PDF第35页（FF13.35）045.00.332 | https://www.ungrund.store/OE-12mm-Abdeckkappe-fuer-Blindbohrung-tiefschwarz-VE-500/PID426816.1
H14 | 技术依据 | 打开 www.nufast.co.uk (https://www.nufast.co.uk/uploads/DIN_929.pdf) | 订单具体SKU、包装量和库存待采购核对。 | https://www.nufast.co.uk/uploads/DIN_929.pdf
H14 | 购买页面 | 打开 boltworld.co.uk (https://boltworld.co.uk/products/m5-hexagon-weld-nut-self-colour-din-929/) | 订单具体SKU、包装量和库存待采购核对。 | https://boltworld.co.uk/products/m5-hexagon-weld-nut-self-colour-din-929/
H15 | 技术依据 | 打开 www.misumi.com.cn | 订单具体SKU、包装量和库存待采购核对。 | https://www.misumi.com.cn/
H15 | 购买页面 | 打开 www.fixaball.co.uk (https://www.fixaball.co.uk/products/m6-socket-cap-screw-high-tensile-12-9-zinc-din-912) | 订单具体SKU、包装量和库存待采购核对。 | https://www.fixaball.co.uk/products/m6-socket-cap-screw-high-tensile-12-9-zinc-din-912
H16 | 技术依据 | 打开 www.nufast.co.uk (https://www.nufast.co.uk/uploads/DIN_929.pdf) | 订单具体SKU、包装量和库存待采购核对。 | https://www.nufast.co.uk/uploads/DIN_929.pdf
H16 | 购买页面 | 打开 www.orbitalfasteners.co.uk (https://www.orbitalfasteners.co.uk/products/m6-mild-steel-hexagon-we-ld-nut-self-colour) | 订单具体SKU、包装量和库存待采购核对。 | https://www.orbitalfasteners.co.uk/products/m6-mild-steel-hexagon-we-ld-nut-self-colour
H17 | 技术依据 | 打开 www.misumi.com.cn | 订单具体SKU、包装量和库存待采购核对。 | https://www.misumi.com.cn/
H17 | 购买页面 | 打开 www.fastenersfixingsandtools.co.uk | 订单具体SKU、包装量和库存待采购核对。 | https://www.fastenersfixingsandtools.co.uk/products/soc-cap-for-zinc-m4x25odin-912-grd129-300mm-keyoo
H18 | 技术依据 | 打开 www.nufast.co.uk (https://www.nufast.co.uk/uploads/DIN_929.pdf) | 订单具体SKU、包装量和库存待采购核对。 | https://www.nufast.co.uk/uploads/DIN_929.pdf
H18 | 购买页面 | 打开 schrauben-expert.de (https://schrauben-expert.de/weld-groove-DIN-929-M4-Steel) | 订单具体SKU、包装量和库存待采购核对。 | https://schrauben-expert.de/weld-groove-DIN-929-M4-Steel
H19 | 技术依据 | 打开 global.sugatsune.com (https://global.sugatsune.com/cn/zh-cn/arch/products/22735_a) | 第1页上段SU-30/S | https://global.sugatsune.com/cn/zh-cn/arch/products/22735_a
H19 | 厂家附加来源 | 打开 www.sugatsune.com (https://www.sugatsune.com/content/site-assets/201B_PDF/474.pdf) | 第1页上段SU-30/S | https://www.sugatsune.com/content/site-assets/201B_PDF/474.pdf
H19 | 购买页面 | 打开 global.sugatsune.com (https://global.sugatsune.com/cn/zh-cn/arch/products/22735_a) | 第1页上段SU-30/S | https://global.sugatsune.com/cn/zh-cn/arch/products/22735_a
H20 | 技术依据 | 打开 www.misumi.com.cn | 订单具体SKU、包装量和库存待采购核对。 | https://www.misumi.com.cn/
H20 | 购买页面 | 打开 www.wovar.co.uk (https://www.wovar.co.uk/chipboard-screws-galvanised-3x12mm/) | 订单具体SKU、包装量和库存待采购核对。 | https://www.wovar.co.uk/chipboard-screws-galvanised-3x12mm/
H21 | 技术依据 | 打开 www.fugendichtband24.de (https://www.fugendichtband24.de/EPDM-Vollgummimatte-2mm-Staerke-200mm-x-300mm-einseitig-selbstklebend-ca-65-Shore-A.htm) | Shore A约65；每桌切8片净面积2304mm²；1片原板足够。含胶厚必须到货实测。 | https://www.fugendichtband24.de/EPDM-Vollgummimatte-2mm-Staerke-200mm-x-300mm-einseitig-selbstklebend-ca-65-Shore-A.htm
H21 | 购买页面 | 打开 www.fugendichtband24.de (https://www.fugendichtband24.de/EPDM-Vollgummimatte-2mm-Staerke-200mm-x-300mm-einseitig-selbstklebend-ca-65-Shore-A.htm) | Shore A约65；每桌切8片净面积2304mm²；1片原板足够。含胶厚必须到货实测。 | https://www.fugendichtband24.de/EPDM-Vollgummimatte-2mm-Staerke-200mm-x-300mm-einseitig-selbstklebend-ca-65-Shore-A.htm
B01 | 技术依据 | 打开 uk.rs-online.com (https://uk.rs-online.com/web/p/door-seals/3269808) | 第2页3269808行 | https://uk.rs-online.com/web/p/door-seals/3269808
B01 | 厂家附加来源 | 打开 docs.rs-online.com (https://docs.rs-online.com/635a/A700000015884303.pdf) | 第2页3269808行 | https://docs.rs-online.com/635a/A700000015884303.pdf
B01 | 购买页面 | 打开 uk.rs-online.com (https://uk.rs-online.com/web/p/door-seals/3269808) | 第2页3269808行 | https://uk.rs-online.com/web/p/door-seals/3269808
B03 | 技术依据 | 打开 www.misumi.com.cn | 订单具体SKU、包装量和库存待采购核对。 | https://www.misumi.com.cn/
B03 | 购买页面 | 打开 www.ubuy.do (https://www.ubuy.do/en/productde/JSV81LXF4-quarkzman-3-mm-x-8-mm-phillips-pan-head-self-tapping-screw-pack-of-100-304-stainless-steel-round-head-wood-screw-fu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) | 订单具体SKU、包装量和库存待采购核对。 | https://www.ubuy.do/en/productde/JSV81LXF4-quarkzman-3-mm-x-8-mm-phillips-pan-head-self-tapping-screw-pack-of-100-304-stainless-steel-round-head-wood-screw-fu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
H22 | 技术依据 | 打开 www.wkooa.com (https://www.wkooa.com/product/6x12x1-shim-washers-stainless-steel-round-metric-din988-w29338) | 成品调整片，不能按8个梁端误计32；安装实测总厚及孔径通过性。 | https://www.wkooa.com/product/6x12x1-shim-washers-stainless-steel-round-metric-din988-w29338
H22 | 购买页面 | 打开 www.wkooa.com (https://www.wkooa.com/product/6x12x1-shim-washers-stainless-steel-round-metric-din988-w29338) | 成品调整片，不能按8个梁端误计32；安装实测总厚及孔径通过性。 | https://www.wkooa.com/product/6x12x1-shim-washers-stainless-steel-round-metric-din988-w29338
H23 | 技术依据 | 打开 www.ganternorm.com (https://www.ganternorm.com/en/products/3.2-Mounting-Positioning-Leveling-with-Retaining-Cables-Screws-Clamping-and-Supporting-Elements/Retaining-cables/GN-111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) | 第1页C型双端片及150规格 | https://www.ganternorm.com/en/products/3.2-Mounting-Positioning-Leveling-with-Retaining-Cables-Screws-Clamping-and-Supporting-Elements/Retaining-cables/GN-111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
H23 | 厂家附加来源 | 打开 www.elesa-ganter.com.cn (https://www.elesa-ganter.com.cn/siteassets/PDF/ZH/GN%20111.2.pdf) | 第1页C型双端片及150规格 | https://www.elesa-ganter.com.cn/siteassets/PDF/ZH/GN%20111.2.pdf
H23 | 购买页面 | 打开 biotek.hu (https://biotek.hu/termek/ele85413-gn-1112-150-c-bl?lang=en) | 第1页C型双端片及150规格 | https://biotek.hu/termek/ele85413-gn-1112-150-c-bl?lang=en
H24 | 技术依据 | 打开 www.westfieldfasteners.co.uk (https://www.westfieldfasteners.co.uk/Standards/Washer-od3nom-M.pdf) | 悬臂T3＋两垫T1＋端片T1.5＋防松母高5，M4×16末端余4.5；已核下方不撞梁/箱体。盖锚(860/1140,440)，底盘锚同X、Y400。 | https://www.westfieldfasteners.co.uk/Standards/Washer-od3nom-M.pdf
H24 | 购买页面 | 打开 www.vital-parts.co.uk (https://www.vital-parts.co.uk/phillips-pan-head-machine-screws-din-7985h/17031-pph7985h-m4-16-a2) | 悬臂T3＋两垫T1＋端片T1.5＋防松母高5，M4×16末端余4.5；已核下方不撞梁/箱体。盖锚(860/1140,440)，底盘锚同X、Y400。 | https://www.vital-parts.co.uk/phillips-pan-head-machine-screws-din-7985h/17031-pph7985h-m4-16-a2
E01 | 技术依据 | 打开 www.gongniu.cn (https://www.gongniu.cn/show-186-625-1.html) | 厂家官网：3个五孔AC，1USB-A+2USB-C，USB最大输出65W | https://www.gongniu.cn/show-186-625-1.html
E02 | 技术依据 | 打开 www.gongniu.cn (https://www.gongniu.cn/show-24-814-1.html) | 厂家官网8位，最大10A，250V，过载保护，3m/5m原装线 | https://www.gongniu.cn/show-24-814-1.html
E03 | 购买页面 | 打开 www.ehsy.com (https://www.ehsy.com/product-CYV274) | 可检索到明装五孔销售型号 | https://www.ehsy.com/product-CYV274
E07 | 技术依据 | 打开 www.hammfg.com (https://www.hammfg.com/part/1557HA2GY) | 箱体外包200×200×70；另购1557HPL原厂内板，工程图外182×182、T2.05、4φ4孔距170；网页187规格概略不作加工依据。 | https://www.hammfg.com/part/1557HA2GY
E07 | 安装说明 | 打开 www.hammfg.com (https://www.hammfg.com/files/products/1557/wall-mount-foot-installipt.pdf?v=1697662067) | 箱体外包200×200×70；另购1557HPL原厂内板，工程图外182×182、T2.05、4φ4孔距170；网页187规格概略不作加工依据。 | https://www.hammfg.com/files/products/1557/wall-mount-foot-installipt.pdf?v=1697662067
E07 | 购买页面 | 打开 twen.rs-online.com (https://twen.rs-online.com/web/p/pcb-mounting-enclosures/1974346) | 箱体外包200×200×70；另购1557HPL原厂内板，工程图外182×182、T2.05、4φ4孔距170；网页187规格概略不作加工依据。 | https://twen.rs-online.com/web/p/pcb-mounting-enclosures/1974346
E07 | 厂家附加来源 | 打开 www.hammfg.com (https://www.hammfg.com/part/1557HA2GY) | 箱体外包200×200×70；另购1557HPL原厂内板，工程图外182×182、T2.05、4φ4孔距170；网页187规格概略不作加工依据。 | https://www.hammfg.com/part/1557HA2GY
E07 | 厂家附加来源 | 打开 www.hammfg.com (https://www.hammfg.com/part/1557HPL) | 箱体外包200×200×70；另购1557HPL原厂内板，工程图外182×182、T2.05、4φ4孔距170；网页187规格概略不作加工依据。 | https://www.hammfg.com/part/1557HPL
E07 | 厂家附加来源 | 打开 www.hammfg.com (https://www.hammfg.com/files/parts/pdf/1557HPL.pdf) | 箱体外包200×200×70；另购1557HPL原厂内板，工程图外182×182、T2.05、4φ4孔距170；网页187规格概略不作加工依据。 | https://www.hammfg.com/files/parts/pdf/1557HPL.pdf
E08 | 技术依据 | 打开 www.gongniu.cn (https://www.gongniu.cn/show-213-967-1.html) | 厂家GN-N1110为自接线10A/250V、1+1插口、防拉脱，原装插头可插入 | https://www.gongniu.cn/show-213-967-1.html
E09 | 技术依据 | 打开 www.schurter.com (https://www.schurter.com/de/datasheet/6100-3) | C14，IEC10A/250V，6.3×0.8快接，螺钉固定，原厂含尺寸图 | https://www.schurter.com/de/datasheet/6100-3
E09 | 厂家附加来源 | 打开 www.schurter.com (https://www.schurter.com/en/pdf/english/typ_6100-3.pdf) | C14，IEC10A/250V，6.3×0.8快接，螺钉固定，原厂含尺寸图 | https://www.schurter.com/en/pdf/english/typ_6100-3.pdf
E10 | 技术依据 | 打开 www.ibiger.com (https://www.ibiger.com/Products/sxwwst.html) | 厂家列国标双头线、10A/250V、3×0.75~1.5、长度可定 | https://www.ibiger.com/Products/sxwwst.html
E10 | 购买页面 | 打开 item.jd.com (https://item.jd.com/product/vUDomLiQGLyNsxPIm4fmTA.html) | 厂家列国标双头线、10A/250V、3×0.75~1.5、长度可定 | https://item.jd.com/product/vUDomLiQGLyNsxPIm4fmTA.html
E11 | 技术依据 | 打开 www.wago.com (https://www.wago.com/global/rail-mount-terminal-blocks/2-conductor-through-terminal-block/p/2002-1201) | 灰色2.5mm²导轨直通端子，单电位，适用DIN35×7.5 | https://www.wago.com/global/rail-mount-terminal-blocks/2-conductor-through-terminal-block/p/2002-1201
E12 | 技术依据 | 打开 www.wago.com (https://www.wago.com/gb/rail-mount-terminal-blocks/2-conductor-through-terminal-block/p/2002-1204) | 蓝色2.5mm²导轨直通端子，单电位，适用DIN35×7.5 | https://www.wago.com/gb/rail-mount-terminal-blocks/2-conductor-through-terminal-block/p/2002-1204
E13 | 技术依据 | 打开 www.wago.com (https://www.wago.com/de/reihenklemmen/2-leiter-schutzleiterklemme/p/2002-1207) | 黄绿2.5mm²专用PE端子，适用DIN35×7.5 | https://www.wago.com/de/reihenklemmen/2-leiter-schutzleiterklemme/p/2002-1207
E14 | 技术依据 | 打开 www.wago.com (https://www.wago.com/gb/rail-mount-terminal-blocks/jumper/p/2002-406) | 6位连续跨接桥，厂家2002系列配套 | https://www.wago.com/gb/rail-mount-terminal-blocks/jumper/p/2002-406
QF0 | 技术依据 | 打开 www.se.com (https://www.se.com/in/en/product/A9D32610/acti-9-idpn-n-vigi-rcbo-1p%2Bn-10a-c-curve-6000a-30ma-type-a/) | 官方10A、1P+N、C曲线、6kA、30mA、TypeA；可隔离L/N | https://www.se.com/in/en/product/A9D32610/acti-9-idpn-n-vigi-rcbo-1p%2Bn-10a-c-curve-6000a-30ma-type-a/
E18 | 技术依据 | 打开 www.schurter.com (https://www.schurter.com/en/datasheet/RC320) | 原厂列适配6100-3；尺寸31.2×23.5×51，出线口内径8.5、外颈径11.5。 | https://www.schurter.com/en/datasheet/RC320
E18 | 厂家附加来源 | 打开 www.schurter.com (https://www.schurter.com/en/datasheet/typ_RC320.pdf) | 原厂列适配6100-3；尺寸31.2×23.5×51，出线口内径8.5、外颈径11.5。 | https://www.schurter.com/en/datasheet/typ_RC320.pdf
E18 | 购买页面 | 打开 eu.mouser.com (https://eu.mouser.com/en/ProductDetail/Schurter/3-125-663?qs=7D1LtPJG0i0StJU2LYjKow%3D%3D) | 原厂列适配6100-3；尺寸31.2×23.5×51，出线口内径8.5、外颈径11.5。 | https://eu.mouser.com/en/ProductDetail/Schurter/3-125-663?qs=7D1LtPJG0i0StJU2LYjKow%3D%3D
E19 | 技术依据 | 打开 www.te.com (https://www.te.com/en/product-735278.html) | 全绝缘母快接6.35×0.81，适1~1.5mm²，直型长21.6，导体绝缘径≤3.3，尼龙绝缘。 | https://www.te.com/en/product-735278.html
E19 | 厂家附加来源 | 打开 www.te.com (https://www.te.com/commerce/DocumentDelivery/DDEController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) | 全绝缘母快接6.35×0.81，适1~1.5mm²，直型长21.6，导体绝缘径≤3.3，尼龙绝缘。 | https://www.te.com/commerce/DocumentDelivery/DDEController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
E19 | 购买页面 | 打开 www.digikey.com (https://www.digikey.com/en/products/detail/te-connectivity-amp-connectors/735278/2054388) | 全绝缘母快接6.35×0.81，适1~1.5mm²，直型长21.6，导体绝缘径≤3.3，尼龙绝缘。 | https://www.digikey.com/en/products/detail/te-connectivity-amp-connectors/735278/2054388
E20 | 技术依据 | 打开 www.schurter.com (https://www.schurter.com/en/pdf/english/typ_6100-3.pdf) | 按SCHURTER6100.3300厂家2×φ3.5固定孔及沉孔配置。 | https://www.schurter.com/en/pdf/english/typ_6100-3.pdf
E21 | 待补来源 | 尚无可核直接链接 | 活动线材按厂家允许弯曲条件选配；250维护余量不当作总领料长度
E22 | 技术依据 | 打开 www.jst-mfg.com (https://www.jst-mfg.com/product/pdf/eng/eRING2.pdf) | M4环端，厂家适线1.04~2.63mm²；匹配2.5mm²移动端。 | https://www.jst-mfg.com/product/pdf/eng/eRING2.pdf
E22 | 购买页面 | 打开 cz.mouser.com (https://cz.mouser.com/ProductDetail/JST-Commercial/FV2-4?qs=cIziFXvMxOUAUZffk7L1Xw%3D%3D) | M4环端，厂家适线1.04~2.63mm²；匹配2.5mm²移动端。 | https://cz.mouser.com/ProductDetail/JST-Commercial/FV2-4?qs=cIziFXvMxOUAUZffk7L1Xw%3D%3D
E23 | 技术依据 | 打开 www.jst-mfg.com (https://www.jst-mfg.com/product/pdf/eng/eRING2.pdf) | M5环端，厂家适线1.04~2.63mm²；匹配2.5mm²固定端。 | https://www.jst-mfg.com/product/pdf/eng/eRING2.pdf
E24 | 待补来源 | 尚无可核直接链接 | 每移动组件1套，螺纹向上；去漆、防松并测连续性，PE不兼吊线
E06 | 待补来源 | 尚无可核直接链接 | 数量按接线点配足，不重复采购E11~E14端子或跨接桥；实际套管内径按导体和端头外包确定
E15 | 厂家附加来源 | 打开 www.wago.com (https://www.wago.com/gb/accessories/screwless-end-stop/p/249-116) | DIN35×7.5长150；19端子宽98.8＋端挡2×6＋隔板3×0.8＝113.2，轨两端各余18.4；箱内排序见terminalLayout。 定型210-112为35×7.5、T1、EN60715；采购2m一支截150，腰宽/R/槽孔模板仍按厂家实物。 | https://www.wago.com/gb/accessories/screwless-end-stop/p/249-116
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

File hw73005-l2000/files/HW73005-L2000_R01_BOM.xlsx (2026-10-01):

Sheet: 零件清单
体验桌零件与采购清单
HW73005-L2000 L2000体验桌 R01 尺寸单位 mm
批量（套） | 1 |  | 版次日期 | 2026-10-01
黄色单元格为本批套数。本批数量 = 单套数量 × 套数；空白数量表示待核实。总成与子件不叠加汇总。
编号 | 零件名称 | 所属总成 | 制造 / 采购类别 | 材料 | 厚度 mm | 单套数量 | 单位 | 本批数量 | 成品尺寸 mm | 开料尺寸 mm | 工艺 / 表面处理 | 图号 | PDF 页 | 状态 | 计数口径 | 依据 | 备注
A01 | 体验桌总装 | 整桌 | 装配 | 详见子件 |  | 1 | 套 | 1 | 2000×1200×900 |  | 按图装配→试装检验 | A01 | 1 | 图纸数字核对；实物首件未执行 | 装配数量；材料按子件领用 | 顾客DWG；R01尺寸协调 | 总成数量不重复计入领料
A04 | 焊接钢结构总成 | A01 | 装配 | 详见子件 |  | 1 | 套 | 1 | 1990×1190×882（含脚） |  | 按图装配→试装检验 | A04 | 3 | 图纸数字核对；实物首件未执行 | 装配数量；材料按子件领用 | 顾客DWG；R01尺寸协调 | 总成数量不重复计入领料
A03 | 桌面翻盖总成 | A01 | 装配 | 阻燃多层三聚氰胺板+科技木皮 | 18 | 1 | 组 | 1 | 2000×1200×18 | 不另计材料 | 同板裁切、开槽、钻孔、封边、磨边 | A03 | 4 | 成型三视已绘；五金安装按实物配孔 | 装配数量；材料按子件领用 | 原图总装顶视及D节点；同版控制R01 | R01成品含封边；Ø10.9名义孔配合按样板；不得把护套Ø11.9法兰当通孔。底面12个φ2.5深10盲孔配H09木螺钉。
A05 | 翻盖承托盒总成 | A03 | 装配 | R01选用阻燃多层板 |  | 2 | 组 | 2 | 330×230×96；内净300×200 | 不另计材料 | 侧板围合、底板托底；预装后配孔固定 | A05 | 5 | 成型三视已绘；五金安装按实物配孔 | 装配数量；材料按子件领用 | 原图总装顶视及D节点；同版控制R01 | 盒材质原图未单独引线；R01选材。有孔端朝走线侧。
W01 | 桌面主板 | A03 | 木作 | 阻燃多层三聚氰胺板+科技木皮 | 18 | 1 | 件 | 1 | 2000×1200×18 | 基板1999.5×1199.5×18，四周封T0.25木皮 | 同板裁切、开槽、钻孔、封边、磨边 | W01 | 6 | 成型三视已绘；五金安装按实物配孔 | 制造零件数量 | 原图总装顶视及D节点；同版控制R01 | R01成品含封边；Ø10.9名义孔配合按样板；不得把护套Ø11.9法兰当通孔。底面12个φ2.5深10盲孔配H09木螺钉。
W02A | 桌面有槽翻盖板 | A03 | 木作 | 同桌面T18阻燃多层三聚氰胺板 | 18 | 2 | 件 | 2 | 298×58×18，底侧28×7让位 | 同W01原板顺纹裁切；保留锯缝工艺量 | 同板取料、开让位、磨边、五金配孔 | W02 | 7 | 成型三视已绘；五金安装按实物配孔 | 制造零件数量 | 原图总装顶视及D节点；同版控制R01 | 源D 0x8469…0x846e；R01长度298；安装在开口Y低值侧，槽口朝中央毛刷。
W02B | 桌面实截面翻盖板 | A03 | 木作 | 同桌面T18阻燃多层三聚氰胺板 | 18 | 2 | 件 | 2 | 298×58×18，实截面 | 同W01原板顺纹裁切；保留锯缝工艺量 | 同板取料、磨边、五金配孔 | W02 | 7 | 成型三视已绘；五金安装按实物配孔 | 制造零件数量 | 原图总装顶视及D节点；同版控制R01 | 源D 0x8465…0x8468；R01长度298；安装在开口Y高值侧，不复制A盖让位槽。
W03 | 承托盒长侧板 | A05 | 木作 | R01选用阻燃多层板 | 15 | 4 | 件 | 4 | 330×91×15 | 按成品净形，磨边余量按工艺 | 裁切、磨边、饰面、试装配孔 | W03 | 8 | 成型三视已绘；五金安装按实物配孔 | 制造零件数量 | 原图总装顶视及D节点；同版控制R01 | 每盒2片；源330/300、230/200链推算T15，材质为R01选择。
W04A | 承托盒短侧板（有孔） | A05 | 木作 | R01选用阻燃多层板 | 15 | 2 | 件 | 2 | 200×91×15，φ50孔中心100/51 | 按成品净形 | 裁切、开φ50孔、护口试装、磨边 | W04 | 9 | 成型三视已绘；五金安装按实物配孔 | 制造零件数量 | 原图总装顶视及D节点；同版控制R01 | 源0x84dd圆心/半径；每盒有孔端1件，朝接线通道。
W04B | 承托盒短侧板（实板） | A05 | 木作 | R01选用阻燃多层板 | 15 | 2 | 件 | 2 | 200×91×15 | 按成品净形 | 裁切、磨边、试装配孔 | W04 | 9 | 成型三视已绘；五金安装按实物配孔 | 制造零件数量 | 原图总装顶视及D节点；同版控制R01 | R01另一端保留实板；不按未证实的对称关系增加过线孔。
W05 | 承托盒底板 | A05 | 木作 | R01选用阻燃多层板 | 5 | 2 | 件 | 2 | 330×230×5 | 按成品净形 | 裁切、磨边、围板托底装配 | W05 | 10 | 成型三视已绘；五金安装按实物配孔 | 制造零件数量 | 原图总装顶视及D节点；同版控制R01 | T5为源D节点实线归一结果；材质选用在R01声明。
S01 | 长边斜腹板 | A04 | 钣金 | 冷轧钢板 | 1.5 | 2 | 件 | 2 | 上口1958.5 / 下口1779.06 × 高100；截面横包110.3 | 按成型图、实际板材与折弯机试折反算 | 激光切割→折弯/成型→端口放样→点固校方→焊接打磨→按样板表面处理 | S01 | 11 | 成型控制；展开补偿按设备首件 | 制造零件数量 | 顾客DWG有效图形 + R01分片 | 颜色、光泽、焊缝处理按样板；去毛刺、不得割手
S02 | 短边斜腹板 | A04 | 钣金 | 冷轧钢板 | 1.5 | 2 | 件 | 2 | 上口1158.5 / 下口979.056 × 高100；截面横包110.3 | 按成型图、实际板材与折弯机试折反算 | 激光切割→折弯/成型→端口放样→点固校方→焊接打磨→按样板表面处理 | S02 | 12 | 成型控制；展开补偿按设备首件 | 制造零件数量 | 顾客DWG有效图形 + R01分片 | 颜色、光泽、焊缝处理按样板；去毛刺、不得割手
A07 | 刀形桌腿焊接总成 | A04 | 装配 | 冷轧钢板 + M8脚件 |  | 4 | 组 | 4 | 131.062×27.933×882（含脚5） |  | 点固→校正→焊接→打磨→装脚 | A07 | 13 | R01分片与高度修正 | 装配数量；材料按子件领用 | 顾客DWG有效图形 + R01分片 | 颜色、光泽、焊缝处理按样板；去毛刺、不得割手
S03A | 刀形腿开口壳 | A07 | 钣金 | 冷轧钢板 | 1.5 | 4 | 件 | 4 | 131.062×27.933×877（低端777） | 按成型图、实际板材与折弯机试折反算 | 激光切割→包折/卷弯→焊接打磨 | S03A | 14 | 成型控制；首件顶口放样 | 制造零件数量 | 顾客DWG有效图形 + R01分片 | 颜色、光泽、焊缝处理按样板；去毛刺、不得割手
S03B | 刀形腿内端封板 | A07 | 钣金 | 冷轧钢板 | 1.5 | 4 | 件 | 4 | 24.733×777×1.5 | 24.733×777×1.5 | 激光切割→焊接→打磨 | S03BC | 15 | 成型控制；展开补偿按设备首件 | 制造零件数量 | 顾客DWG有效图形 + R01分片 | 颜色、光泽、焊缝处理按样板；去毛刺、不得割手
S03C | 刀形腿底封板 | A07 | 钣金 | 冷轧钢板 | 1.5 | 4 | 件 | 4 | 随壳内轮廓配切；外包≤128.1×24.9 | 沿S03A成型内轮廓留0.2间隙 | 内轮廓套样→切孔→焊母→焊接 | S03BC | 15 | 配切件；按首件成型内腔 | 制造零件数量 | 顾客DWG有效图形 + R01分片 | 颜色、光泽、焊缝处理按样板；去毛刺、不得割手
S04 | 桌肚四边折边底盘 | A04 | 钣金 | 冷轧钢板 | 1 | 1 | 件 | 1 | 1769.4×969.4×15 | 按成型图、实际板材与折弯机试折反算 | 切割→四边折弯→焊接 | S04 | 16 | R01接口闭合；展开按实际折弯补偿 | 制造零件数量 | 顾客DWG有效图形 + R01分片 | 颜色、光泽、焊缝处理按样板；去毛刺、不得割手
S07 | 桌肚检修门 | A04 | 钣金 | 冷轧钢板 | 1.5 | 2 | 件 | 2 | 994.8×154.8×10 | 按成型图、实际板材与折弯机试折反算 | 切割→折弯→模板配孔→装五金 | S07 | 17 | 成型已定；五金孔形按到货件配钻 | 制造零件数量 | 顾客DWG有效图形 + R01分片 | 颜色、光泽、焊缝处理按样板；去毛刺、不得割手
S05 | 长向C型加强筋 | A04 | 钣金制造件 | 冷轧钢板 | 2 | 2 | 件 | 2 | 最大投影1943×30×97；上边1915.4；下边1767 |  | T2折弯成C；两端阶梯与斜切避让；装配焊接；表面处理随金属总成 | S05 | 18 | 成型已绘；工艺试制待核 | 制造零件数量 | 源BV-BV 0x7EC7..0x7EF2；D节点0x84A2..0x84D5；R01包络与筋距统一 | 每桌2根；唇边13，C口相向；净430/外跨490。端接口、折弯补偿与焊接收缩未放行。
S06 | U型卡槽 | A04 | 钣金制造件 | 冷轧钢板 | 1 | 2 | 件 | 2 | 100长×25底宽×20高；喉口18 |  | T1折弯；口沿外翻；与底板焊接；表面处理随金属总成 | S06 | 19 | 成型已绘；工艺试制待核 | 制造零件数量 | 源U型卡槽0xD353..0xD35F及18/20/25/100标注；R01按T1归整 | 底宽不含外翻唇；中心(315.5,595)/(1674.5,595)，相距1359；先试卡，展开补偿待核。
A06 | 小孔过线护口组件 | A03 | 装配 | M01+M02+M03 | — | 1 | 套 | 1 | 封盖单元φ11.9×18.2；20孔/桌 | 不单独领料 | 配套车工、胶接装配 | A06 | 20 | 装配关系完成 | 装配数量；材料按子件领用 | SRC-05：0x6389..0x6390、0x63d9..0x63e4、0xca02；桌面20孔/源内盖10件 | 装配行仅统计覆盖；材料数量计入M01/M02/M03
M01 | 304过线外护套 | A06 | 机加工 | 304不锈钢棒 | — | 20 | 件 | 20 | φ11.9×18.2；体φ10.9；孔φ8.8/φ9.9 | 车工棒料，工艺余量自定 | 车削+成型口缘+去毛刺+样板饰面 | M01 | 21 | 完成 | 制造零件数量 | SRC-05：0x638d..0x6390、0x63dc..0x63e2；口缘0x63c3..0x63c6，CX倍率归一 | 源G01；下外R0.3、内R0.15；配合公差参照样板
M02 | 304过线内盖 | A06 | 机加工 | 304不锈钢棒 | 顶壁0.9 | 10 | 件 | 10 | 头φ9.84/身φ8.65×10；盲孔φ6.5×9.1 | 车工棒料，工艺余量自定 | 车削+去毛刺+镭射面按样板 | M02 | 22 | 完成 | 制造零件数量 | SRC-05：0x6389..0x638b、0x63d9..0x63db、0x63e3/0x63e4、0xca04/0xca06 | 源G02；顶面光滑无刀痕；与M01成套适配
M03 | 内盖镀锌内贴片 | A06 | 金属平板 | 镀锌钢板 | 3 | 10 | 件 | 10 | φ6×3 | φ6×T3圆片 | 圆片下料+去毛刺+胶接 | M03 | 23 | 完成 | 制造零件数量 | SRC-05：0xca02 原注“内粘φ6*3厚镀锌板”；内盖10件 | 源G03；每M02一片，共10片，居中贴于盲孔顶壁
E01 | 桌面三位五孔+3USB排插 | A03 | 电气采购 | 定型采购 |  | 2 | 个 | 2 | 3位五孔+3USB；每翻盖组1个 | 定型采购；按样板与安装接口选配 | 按样板选型、盒内固定 | E01 | 24 | 规格数量已定；型号/安装孔按到货模板 | 采购数量 | 顾客DWG现行电气/五金原注；R01翻盖2组、检修门2件、前左腿出线 | 核对300×200盒内净空、翻盖运动及孔位；不预设电流/功率
E02 | 桌肚八位五孔排插 | A04 | 电气采购 | 定型采购 |  | 2 | 个 | 2 | 8位五孔；每检修门1个 | 定型采购；按样板与安装接口选配 | 粘装固定器、随门开启 | E01 | 24 | 规格数量已定；型号/安装孔按到货模板 | 采购数量 | 顾客DWG现行电气/五金原注；R01翻盖2组、检修门2件、前左腿出线 | 配H05固定器；活动线缆留余量，避让锁舌和铰链
E03 | 明装安全五孔插座 | A04 | 电气采购 | 定型采购 |  | 1 | 个 | 1 | 五孔安全型；桌肚明装 | 定型采购；按样板与安装接口选配 | 按到货模板固定 | E01 | 24 | 规格数量已定；型号/安装孔按到货模板 | 采购数量 | 顾客DWG现行电气/五金原注；R01翻盖2组、检修门2件、前左腿出线 | R01安装区X280/Y450；设备外廓和固定孔按选型
E04 | 3芯电源线束 | A01 | 电气辅材 | 定型采购 |  |  | m |  | 3×1.5mm²；3C认证电源 | 定型采购；按样板与安装接口选配 | 按实测配长、涮锡、端子连接 | E01 | 24 | 长度按实配，未填估算值 | 采购数量 | 顾客DWG现行电气/五金原注；R01翻盖2组、检修门2件、前左腿出线 | 长度按实配且不填0；前左腿出线，活动段留检修余量
E05 | 桌肚过线保护铁管 | A04 | 电气辅材 | 铁管 |  |  | m |  | 源要求≥25；本版止于腿上口 | 定型采购；按样板与安装接口选配 | 桌肚内护线、管端保护 | E01 | 24 | 长度按实配，未填估算值 | 采购数量 | 顾客DWG现行电气/五金原注；R01翻盖2组、检修门2件、前左腿出线 | R01调整：净约24.7刀形腔及34×14底孔不能容纳≥25管，腿内改线缆加绝缘/夹持，首件核实
E06 | 接线端子与黄腊管配套 | A01 | 电气辅材 | 定型采购 |  | 1 | 套 | 1 | 匹配3×1.5mm²导线；端子/黄腊管按连接点实配 | 定型采购；按样板与安装接口选配 | 接线、绝缘保护、落地端限位 | E01 | 24 | 规格数量已定；型号/安装孔按到货模板 | 采购数量 | 顾客DWG现行电气/五金原注；R01翻盖2组、检修门2件、前左腿出线 | 不得裸接；数量按系统连接点配齐，辅材长度按实配
H01 | M8黑色橡胶调节脚 | A07 | 外购五金 | 定型采购 |  | 8 | 只 | 8 | M8；外φ18/内φ16；调节≤5 | 定型采购；按样板与安装接口选配 | 旋入H02焊母 | H01 | 25 | 规格数量已定；型号/安装孔按到货模板 | 采购数量 | 顾客DWG现行电气/五金原注；R01翻盖2组、检修门2件、前左腿出线 | 每腿2只，共8；高度验收设外露5，底封板孔见S03BC
H02 | M8焊接螺母 | A07 | 外购五金 | 定型采购 |  | 8 | 只 | 8 | M8；匹配S03C的φ8.5孔 | 定型采购；按样板与安装接口选配 | 底封板内侧点焊 | H01 | 25 | 规格数量已定；型号/安装孔按到货模板 | 采购数量 | 顾客DWG现行电气/五金原注；R01翻盖2组、检修门2件、前左腿出线 | 每腿2只，焊渣不得堵螺纹；和H01先试装
H03 | 检修门铰链 | S07 | 外购五金 | 定型采购 |  | 4 | 只 | 4 | 每门2只；型号按样板 | 定型采购；按样板与安装接口选配 | 按到货模板配钻 | H01 | 25 | 规格数量已定；型号/安装孔按到货模板 | 采购数量 | 顾客DWG现行电气/五金原注；R01翻盖2组、检修门2件、前左腿出线 | S07局部u=200/794.8，v=0；不得照符号钻孔
H04 | 无钥匙一字旋钮锁 | S07 | 外购五金 | 定型采购 |  | 2 | 只 | 2 | 每检修门1只 | 定型采购；按样板与安装接口选配 | 按到货锁孔模板配钻 | H01 | 25 | 规格数量已定；型号/安装孔按到货模板 | 采购数量 | 顾客DWG现行电气/五金原注；R01翻盖2组、检修门2件、前左腿出线 | S07锁中心u=497.4，v=134.8；核对锁舌行程
H05 | 八位排插粘贴固定器 | S07 | 外购五金 | 定型采购 |  | 2 | 组 | 2 | 匹配E02；每门1组 | 定型采购；按样板与安装接口选配 | 门背居中粘贴固定 | H01 | 25 | 规格数量已定；型号/安装孔按到货模板 | 采购数量 | 顾客DWG现行电气/五金原注；R01翻盖2组、检修门2件、前左腿出线 | 清洁粘贴面；避开锁舌，先做门启闭和保持力检查
H06 | 白色过线护口 | A05 | 外购五金 | 定型采购 |  | 2 | 只 | 2 | 安装孔φ50；匹配T15侧板 | 定型采购；按样板与安装接口选配 | 装于W04A有孔短端板 | H01 | 25 | 规格数量已定；型号/安装孔按到货模板 | 采购数量 | 顾客DWG现行电气/五金原注；R01翻盖2组、检修门2件、前左腿出线 | 每盒1处；板面200×91，孔心(100,51)，总成见A05
H07 | 翻盖铰接配套件 | A03 | 外购五金 | 定型采购 |  | 4 | 套 | 4 | 每片盖1套；型号按样板 | 定型采购；按样板与安装接口选配 | 按选型配孔、试开合 | H01 | 25 | 规格数量已定；型号/安装孔按到货模板 | 采购数量 | 顾客DWG现行电气/五金原注；R01翻盖2组、检修门2件、前左腿出线 | W02A/W02B各2片；型号和单套组成按样板，不填虚构孔距
H08 | 出线护口、限位及夹持件 | A07 | 外购五金 | 定型采购 |  | 1 | 套 | 1 | 匹配34×14底部长圆孔与实际线径 | 定型采购；按样板与安装接口选配 | 前左过线腿装配 | H01 | 25 | 规格数量已定；型号/安装孔按到货模板 | 采购数量 | 顾客DWG现行电气/五金原注；R01翻盖2组、检修门2件、前左腿出线 | R01单腿出线；腿内加绝缘保护，末端线缆单独引出
H09 | 桌面木螺钉 | A03 | 外购五金 | 定型采购 |  | 12 | 只 | 12 | φ4×12；配φ4.5金属孔 | 定型采购；按样板与安装接口选配 | 木板预钻φ2.5深10 | H01 | 25 | 规格数量已定；型号/安装孔按到货模板 | 采购数量 | 顾客DWG现行电气/五金原注；R01翻盖2组、检修门2件、前左腿出线 | 长边X400/1000/1600,Y30/1170；短边X30/1970,Y300/600/900
B01 | 贯通毛刷组件 | A03 | 毛刷配套 | 定型采购 |  | 1 | 组 | 1 | 覆盖总槽1420×20；端R10 | 定型采购；按样板与安装接口选配 | 按样板型材分段适配 | H01 | 25 | 规格数量已定；型号/安装孔按到货模板 | 采购数量 | 顾客DWG现行电气/五金原注；R01翻盖2组、检修门2件、前左腿出线 | 含翻盖区域毛刷，总覆盖长1420不重复领料；刷顶齐台面
B02 | 翻盖毛刷挡条及卡件 | A03 | 毛刷配套 | 定型采购 |  | 2 | 组 | 2 | 每翻盖组1套；中央净20 | 定型采购；按样板与安装接口选配 | 配W02A底部28×7让位 | H01 | 25 | 规格数量已定；型号/安装孔按到货模板 | 采购数量 | 顾客DWG现行电气/五金原注；R01翻盖2组、检修门2件、前左腿出线 | 型材按样板；毛刷本体计入B01，挡条卡件在此计数

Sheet: 图纸目录
图纸目录
HW73005-L2000 L2000体验桌 R01 尺寸单位 mm
批量（套） | 1 |  | 版次日期 | 2026-10-01
PDF 页码指本次交付图纸文件内的页序；零件编号与清单、图号对应。
图号 | 图纸名称 | PDF 页 | 比例 | 关联零件 / 总成 | 状态 | 内容说明 | 依据
A01 | 整桌总装 · 三视、基准与装配尺寸 | 1 | 1:10 | A01 | 三视已绘 | 整桌总装 · 三视、基准与装配尺寸 | 顾客DWG SRC-02/03/04 + R01统一尺寸
A02 | 总装拆件 · 构件分离轴测与安装层次 | 2 | 1:10 | W01、W02A、W02B、A05、S01、S02、S04、S05、S07、A07 | 真实构件分离轴测；不作加工量测 | 总装拆件 · 构件分离轴测与安装层次 | 顾客DWG SRC-02/03/04 + R01统一尺寸
A04 | 钢结构总成 · 底视布置、三视与焊接 | 3 | 1:10 | A04 | 三视已绘 | 钢结构总成 · 底视布置、三视与焊接 | 顾客DWG SRC-02/03/04 + R01统一尺寸
A03 | 桌面与翻盖总成｜孔位、毛刷及护口布置 | 4 | 1:10 | A03 | 成型三视已绘；配孔及装配按页内说明 | 桌面与翻盖总成｜孔位、毛刷及护口布置 | 原图总装顶视及D节点；同版控制R01
A05 | 承托盒总成｜两组翻盖下方安装 | 5 | 1:2 | A05 | 成型三视已绘；配孔及装配按页内说明 | 承托盒总成｜两组翻盖下方安装 | 原图总装顶视及D节点；同版控制R01
W01 | W01 桌面成品板｜实际切口与封边控制 | 6 | 1:10 | W01 | 成型三视已绘；配孔及装配按页内说明 | W01 桌面成品板｜实际切口与封边控制 | 原图总装顶视及D节点；同版控制R01
W02 | W02A / W02B 翻盖板｜有槽与实板配对 | 7 | 1:2 | W02A、W02B | 成型三视已绘；配孔及装配按页内说明 | W02A / W02B 翻盖板｜有槽与实板配对 | 原图总装顶视及D节点；同版控制R01
W03 | W03 承托盒长侧板｜阻燃多层板 | 8 | 1:2 | W03 | 成型三视已绘；配孔及装配按页内说明 | W03 承托盒长侧板｜阻燃多层板 | 原图总装顶视及D节点；同版控制R01
W04 | W04A / W04B 承托盒短侧板｜有孔与无孔分件 | 9 | 1:2 | W04A、W04B | 成型三视已绘；配孔及装配按页内说明 | W04A / W04B 承托盒短侧板｜有孔与无孔分件 | 原图总装顶视及D节点；同版控制R01
W05 | W05 承托盒底板｜托底构造与三视 | 10 | 1:2 | W05 | 成型三视已绘；配孔及装配按页内说明 | W05 承托盒底板｜托底构造与三视 | 原图总装顶视及D节点；同版控制R01
S01 | 长边斜腹板 · 成型与端部放样 | 11 | 1:10 | S01 | 已绘成型尺寸及工艺说明 | 长边斜腹板 · 成型与端部放样 | 顾客DWG SRC-02/03/04；R01深化
S02 | 短边斜腹板 · 成型与端部放样 | 12 | 1:5 | S02 | 已绘成型尺寸及工艺说明 | 短边斜腹板 · 成型与端部放样 | 顾客DWG SRC-02/03/04；R01深化
A07 | 刀形桌腿总成 · 分缝、脚件与过线 | 13 | 1:5 | A07 | 已绘成型尺寸及工艺说明 | 刀形桌腿总成 · 分缝、脚件与过线 | 顾客DWG SRC-02/03/04；R01深化
S03A | 刀形腿壳 · 成型三视与焊缝 | 14 | 1:5 | S03A | 已绘成型尺寸及工艺说明 | 刀形腿壳 · 成型三视与焊缝 | 顾客DWG SRC-02/03/04；R01深化
S03BC | 刀形腿封板 · 内端板与底封板 | 15 | 1:5 | S03B、S03C | 已绘成型尺寸及工艺说明 | 刀形腿封板 · 内端板与底封板 | 顾客DWG SRC-02/03/04；R01深化
S04 | 桌肚底盘 · 折边、检修口与定位 | 16 | 1:10 | S04 | 已绘成型尺寸及工艺说明 | 桌肚底盘 · 折边、检修口与定位 | 顾客DWG SRC-02/03/04；R01深化
S07 | 检修门 · 门缝、铰链与排插固定 | 17 | 1:5 | S07 | 已绘成型尺寸及工艺说明 | 检修门 · 门缝、铰链与排插固定 | 顾客DWG SRC-02/03/04；R01深化
S05 | S05 长向 C 型加强筋成型制作 | 18 | 1:5 | S05 | 成型已绘；干涉按同版腹板已消除；试装与折弯展开待核 | 长向C筋成型三视、原端部斜切控制与安装横截面；T2、30×97、唇13、净430。 | 源BV-BV 0x7EC7..0x7EF2；D节点0x84A2..0x84D5；R01包络与筋距统一
S06 | S06 U 型卡槽成型制作与安装 | 19 | 1:1 | S06 | 成型已绘；试卡与折弯展开待核 | U槽成型三视与口沿截面；真实底宽25、喉口18、高20，外翻唇单独表达。 | 源U型卡槽0xD353..0xD35F及18/20/25/100标注；R01按T1归整
A06 | A06 小孔过线护口组件｜配合与安装 | 20 | 5:1 | A06 | 已绘并校核 | 20护套、10封盖、10内片；同轴配合及板厚关系 | SRC-05：0x6389..0x6390、0x63d9..0x63e4、0xca02；桌面20孔/源内盖10件
M01 | M01 304不锈钢过线外护套｜20件/桌 | 21 | 5:1 | M01 | 已绘并校核 | 真实口缘线弧、外内径、沉孔、下口圆角及三视投影 | SRC-05：0x638d..0x6390、0x63dc..0x63e2；口缘0x63c3..0x63c6，CX倍率归一
M02 | M02 304不锈钢过线内盖｜10件/桌 | 22 | 5:1 | M02 | 已绘并校核 | 带盲孔的台阶内盖三视、全剖、壁厚和胶接位置 | SRC-05：0x6389..0x638b、0x63d9..0x63db、0x63e3/0x63e4、0xca04/0xca06
M03 | M03 内盖镀锌内贴片｜10件/桌 | 23 | 10:1 | M03 | 已绘并校核 | 圆形内片三视、剖面、直径厚度和配套数量 | SRC-05：0xca02 原注“内粘φ6*3厚镀锌板”；内盖10件
E01 | 电气安装与走线｜位置、连接及R01过线调整 | 24 | 1:10 | E01、E02、E03、E04、E05、E06 | 安装投影/规格数量已绘；外购型号按样板 | 三向安装投影、真实定位、3C/3×1.5mm²及源管径冲突的R01调整 | 顾客DWG现行电气/五金原注；R01翻盖2组、检修门2件、前左腿出线
H01 | 五金与毛刷配套｜数量、接口及模板配钻 | 25 | 1:2 | H01、H02、H03、H04、H05、H06、H07、H08、H09、B01、B02 | 安装投影/规格数量已绘；外购型号按样板 | H01~H09、B01/B02规格数量与接口；外购型号及配孔依到货模板 | 顾客DWG现行电气/五金原注；R01翻盖2组、检修门2件、前左腿出线
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

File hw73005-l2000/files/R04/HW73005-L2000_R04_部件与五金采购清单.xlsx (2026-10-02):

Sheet: 部件清单
R04部件清单
HW73005-L2000 R04 2026-10-02 单位：mm；数量按一桌
价格为公开参考价，未含未声明的税费、运费与进口费用；待核项见第三页。
件号 | 名称 | 类别 | 每桌用量 | 单位 | 成品规格 / 加工外包 | 同版图页 | 所属装配
A01 | 体验桌总装 | 装配 | 1 | 套 | 2000×1200×900 | A01 / 1 | 整桌
A04 | 焊接钢结构总成 | 装配 | 1 | 套 | 1990×1190×882（含脚） | A04 / 3、F01 / 21 | A01
A03 | 桌面翻盖总成 | 装配 | 1 | 组 | 2000×1200×18 | A03 / 2 | A01
A05 | 翻盖承托盒总成 | 装配 | 2 | 组 | 330×230×96；内净300×200 | A03 / 2、W03 / 7 | A04
W01 | 桌面主板 | 木作 | 1 | 件 | 2000×1200×18 | W01 / 4、D02 / 6 | A03
W02A | 桌面有槽翻盖板 | 木作 | 2 | 件 | 298×59.2×18；中央底槽保持 | W02 / 5、D02 / 6 | A03
W02B | 桌面实截面翻盖板 | 木作 | 2 | 件 | 298×59.2×18 | W02 / 5、D02 / 6 | A03
W03 | 承托盒长侧板（无孔） | 木作 | 2 | 件 | 330×91×15 | W03 / 7 | A05
W03A | 承托盒长侧板（有孔） | 木作 | 2 | 件 | 330×91×15，φ50孔中心165/51 | W03 / 7 | A05
W04B | 承托盒短侧板 | 木作 | 4 | 件 | 200×91×15 | W03 / 7 | A05
W05 | 承托盒底板 | 木作 | 2 | 件 | 330×230×5 | W03 / 7 | A05
S01 | 长边斜腹板 | 钣金 | 2 | 件 | 最大沿长投影1957.058448×110.3×100；复合端口见图 | S01 / 8 | A04
S02 | 短边斜腹板 | 钣金 | 2 | 件 | 最大沿长投影1157.058448×110.3×100；复合端口见图 | S02 / 9 | A04
A07 | 刀形桌腿焊接总成 | 装配 | 4 | 组 | 131.062×27.933×882（含脚5） | A04 / 3 | A04
S03A | 刀形腿开口壳 | 钣金 | 4 | 件 | 131.062×27.933×877（低端777） | S03A / 10 | A07
S03B | 刀形腿内端封板 | 钣金 | 3 | 件 | 外包22.503615×777.000000×T1.5；净形/孔见原生轮廓 | S03BC / 17 | A07
S03C | 刀形腿底封板 | 钣金 | 4 | 件 | 外包127.661040×24.428053×T1.5；净形/孔见原生轮廓 | S03BC / 17 | A07
S04 | 桌肚四边折边底盘 | 钣金 | 1 | 件 | 1769.4×969.4×15 | S04 / 11 | A04
S07 | 桌肚检修门 | 钣金 | 2 | 件 | 994.8×154.8×10 | S07 / 12、F01 / 21 | A04
S05 | 长向C型加强筋 | 钣金制造件 | 1 | 件 | 最大投影1943×30×97；上边1915.4；下边1767 | S05 / 13 | A04
S06 | U型卡槽 | 钣金制造件 | 2 | 件 | 100长×25底宽×20高；喉口18 | S06 / 15 | A04
A08 | 桌肚内部加强与检修总成 | 装配 | 1 | 组 | 沿用2000×1200×900；详子件 | A04 / 3 | A04
S08 | 可拆横梁焊接总成 | 装配 | 4 | 组 | 478×60×60；管身40×50×472 | S08A / 16 | A08
S08A | 横梁矩管身 | 钣金制造件 | 4 | 件 | 40×50×T2，L472 | S08A / 16 | S08
S09A | 可拆横梁端板 | 钣金制造件 | 8 | 件 | 外包60.000000×60.000000×T3；净形/孔见原生轮廓 | S09 / 18 | S08
S09B | 桌面M6固定耳 | 钣金制造件 | 8 | 件 | X宽40×水平40×高35；T3；6.6×12槽 | S09 / 18 | A08
S09C | 承托盒抱角 | 钣金制造件 | 8 | 件 | Y宽50×X包35×Z高49；T2；側φ6 H11 | S09 / 18 | A08
S10A | 中央搭接检修盖 | 钣金制造件 | 1 | 件 | 外包340.000000×380.000000×T1.5；净形/孔见原生轮廓 | S10AB / 19、F01 / 21 | A08
S10B | 分线盒吊检修安装板 | 钣金制造件 | 1 | 件 | 外包300.000000×240.000000×T2；净形/孔见原生轮廓 | S10AB / 19、F01 / 21 | A08
S10C | 分线盒检修板悬臂 | 钣金制造件 | 4 | 件 | 沿Y20×X包85×Z高49；T3 | S10CDE / 20 | A08
S10D | 中央盖M5焊母补强片 | 钣金制造件 | 4 | 件 | 外包20.000000×20.000000×T2；净形/孔见原生轮廓 | S10CDE / 20 | A08
S10E | 检修门锁接收槽形座 | 钣金制造件 | 2 | 件 | 30×12×18.3；T1.5 | S10CDE / 20 | A08
E01 | 桌面三位五孔+3USB排插 | 电气采购 | 2 | 个 | 每盒1个；公牛UU3653候选(1A+2C) | E02 / 22 | A04
E02 | 桌肚八位五孔排插 | 电气采购 | 2 | 个 | 公牛GN-604候选；每门1个 | E02 / 22 | S07
E03 | 明装安全五孔插座 | 电气采购 | 1 | 个 | 10A接地安全型；NEW1-C11100A候选 | E02 / 22 | A01
E04 | 三芯内部分支线束 | 电气辅材 |  | m | 3×1.5mm²；W00/W1~W5 | E02 / 22 | A01
E05 | 桌肚过线保护管 | 电气辅材 |  | m | 实际外径≤25；本版过梁层净34 | E02 / 22 | A01
E06 | 绝缘套管及线号配套 | 电气辅材 | 1 | 套 | 黄腊管/热缩管、永久线号 | E02 / 22 | A01
E07 | 中央成品分线盒与内板 | 电气采购 | 1 | 套 | 1557HA2GY箱体＋1557HPL内板各1 | E02 / 22 | S10B
E08 | 排插独立固定分支插座 | 电气采购 | 4 | 只 | X1~X4；10A接地型，GN-N1110候选 | E02 / 22 | A01
E10 | 单腿引出国标16A厂制电源线 | 电气采购 | 1 | 条 | 3×1.5mm² RVV、CCC、黑色；总长建议4.0m，插头模制/盒端自由线 | E02 / 22 | A01
E11 | L灰色直通端子 | 电气采购 | 6 | 只 | WAGO2002-1201；XL0~XL5 | E02 / 22 | A01
E12 | N蓝色直通端子 | 电气采购 | 6 | 只 | WAGO2002-1204；XN0~XN5 | E02 / 22 | A01
E13 | 黄绿PE端子 | 电气采购 | 7 | 只 | WAGO2002-1207；XPE0~XPE6 | E02 / 22 | A01
E14 | 六位连续跨接桥 | 电气采购 | 2 | 根 | WAGO2002-406；L/N各1根 | E02 / 22 | A01
E15 | 导轨端挡与绝缘端板 | 电气辅材 | 1 | 套 | 210-112轨；249-116×2/2002-1291×3 | E02 / 22 | A01
E16 | 金属件保护连接配套 | 电气辅材 | 1 | 套 | 7条2.5黄绿线；FV2-5×11/FV2-4×2 | E02 / 22 | A01
E17 | 单腿入口护口与近C防拉脱配套 | 电气辅材 | 1 | 套 | 腿底Heyco2053/Φ12.7；近C Phoenix Contact 1411133+1411215/Φ20.1-20.2 | E02 / 22 | A01
E21 | 中央组件柔性PE线 | 电气采购 | 2 | 根 | 黄绿铜软线2.5mm²；长度待实测 | E02 / 22 | A01
E22 | 中央PE移动端M4环端子 | 电气采购 | 2 | 只 | JST FV2-4；适1.04~2.63mm² | E02 / 22 | A01
E23 | 中央PE固定端M5环端子 | 电气采购 | 2 | 只 | JST FV2-5；适1.04~2.63mm² | E02 / 22 | A01
E24 | 中央组件PE专用紧固件 | 电气采购 | 2 | 套 | M4×10螺钉+平/齿形垫+防松螺母 | E02 / 22 | A01
H01 | 薄型调节脚 | 采购五金 | 8 | 只 | 底φ20；M8×1.25；螺杆长15；底高6；总高21 | A04 / 3 | A07
H02 | M8六角焊接螺母 | 采购五金 | 8 | 只 | M8×1.25；对边14；螺母厚6.5；定位凸台径10.45最大 | A04 / 3 | S03C
H03 | 检修门可脱卸合页 | 采购五金 | 4 | 只 | 展开50×75×T1.5；4×φ3.8；孔距38×63.5；轴径6；厚向包络9.5 | A04 / 3 | S07
H04 | 直槽工具转舌锁（完整套件） | 采购五金 | 2 | 套 | 面头φ28×4；开孔φ22.5与20.1方形交集；GH18；H19.5；锁舌35×20×T3（35为轴心至端） | A04 / 3 | S07
H05 | 排插滑拆固定器组 | 采购五金 | 2 | 组 | 每门2套滑拆固定器；包装尺寸99.5×45×9.2非工程外形 | A04 / 3 | S07
H06 | 承托盒白色穿线护口 | 采购五金 | 2 | 只 | φ50安装孔；两件式；经销规格入孔深22 | A04 / 3 | W03A
H07 | 侧埋十字暗铰 | 采购五金 | 8 | 只 | SOSS 101CUS26D；8只 | D02 / 6 | A03
H09 | 桌面M6机螺钉 | 采购五金 | 8 | 只 | M6×1；公称杆长12；配平垫6.4×12×1.6 | A04 / 3 | A03
H10 | 桌面M6木用嵌入螺母 | 采购五金 | 8 | 只 | 外径12；L12；内牙M6；内六角SW6；厂家底孔10.0~10.5 | A04 / 3 | W01
H11 | M6平垫圈 | 采购五金 | 8 | 只 | φ6.4×φ12×T1.6 | A04 / 3 | A03
H12 | 检修门合页螺钉配套 | 采购五金 | 16 | 套 | M3×0.5×8；每合页4套 | A04 / 3 | S07
H13 | 检修盖及吊板防脱螺钉 | 采购五金 | 8 | 只 | M5×0.8；杆长8；末端牙长4；颈径3.9；头φ8.5×5；内六角4 | A04 / 3 | A04
H25 | 分体穿线护圈 | 采购五金 | 20 | 只 | Sugatsune CHC-S18BL；20只 | D02 / 6 | A06
H26 | 可拔齐平孔盖 | 采购五金 | 10 | 只 | Häfele 045.00.332；10只 | D02 / 6 | A06
H14 | 检修盖及吊板M5焊接螺母 | 采购五金 | 8 | 只 | M5×0.8；对边10；厚4；定位凸台6.96最大 | A04 / 3 | A04
H15 | 横梁M6连接螺钉配套 | 采购五金 | 16 | 套 | M6×20；头下垫6.4×12×T1.6；每套各1 | A04 / 3 | S09A
H16 | 横梁M6焊接螺母 | 采购五金 | 16 | 只 | M6×1；对边11；厚5；定位凸台7.96最大 | A04 / 3 | S09A
H17 | 承托盒M4连接螺钉配套 | 采购五金 | 8 | 套 | M4×25；每套1螺钉1平垫 | A04 / 3 | S09C
H18 | 承托盒M4焊接螺母 | 采购五金 | 8 | 只 | M4×0.7；对边9；厚3.5；定位凸台5.97最大 | A04 / 3 | S09C
H19 | 翻盖独立承托角码 | 采购五金 | 8 | 只 | 30×30×宽12×T2.5；4×φ3.5沉φ6.5；两面孔距直角基准11/24 | A03 / 2 | A03
H20 | 角码木螺钉 | 采购五金 | 16 | 只 | 每角码竖面2只；杆φ3、长12 | A03 / 2 | A03
H21 | 角码软垫 | 采购五金 | 8 | 片 | 实心EPDM片200×300×T2，胶另约0.22~0.24；裁8片24×12 | A03 / 2 | A03
B01 | 成品毛刷条 | 采购五金 | 2 | 根 | 每根1000；尼龙毛长19；F型铝座；截面总26.5、座6.7×6.7 | A03 / 2 | A03
B03 | 毛刷固定木螺钉 | 采购五金 | 10 | 只 | 每毛刷段2枚；5段共10枚 | A03 / 2 | A03
H22 | 横梁调整垫片 | 采购五金 | 64 | 片 | 内径6、外径12、厚1；每个螺栓4片叠为4 | A04 / 3 | S09A
H23 | 检修盖及吊板防坠索 | 采购五金 | 4 | 根 | 钢索φ1.6；索环根间150；两端片孔φ5.3、宽14、T1.5；拉直孔心距约183 | A04 / 3 | A04
H24 | 防坠索端片紧固配套 | 采购五金 | 8 | 套 | 每套1盘头螺钉、2大垫φ4.3×12×T1、1防松母；M4母总高5 | A04 / 3 | A04
A06 | 成品护口与孔盖组件 | 装配 | 1 | 套 | 20只衬套＋10只盖 | D02 / 6 | A03
W06 | 孔盖底部补强环 | 木作 | 20 | 片 | 外Φ30/内Φ14×T2桦木多层板 | D02 / 6 | A03
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

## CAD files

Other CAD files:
hw73005-l2000/files/HW73005-L2000_R01.dwg
hw73005-l2000/files/R02/HW73005-L2000_R02.dwg
hw73005-l2000/files/R03/HW73005-L2000_R03.dwg
hw73005-l2000/files/R04/HW73005-L2000_R04.dwg
hw73005-l2000/files/R03/HW73005-L2000_R03_三维装配.dwg

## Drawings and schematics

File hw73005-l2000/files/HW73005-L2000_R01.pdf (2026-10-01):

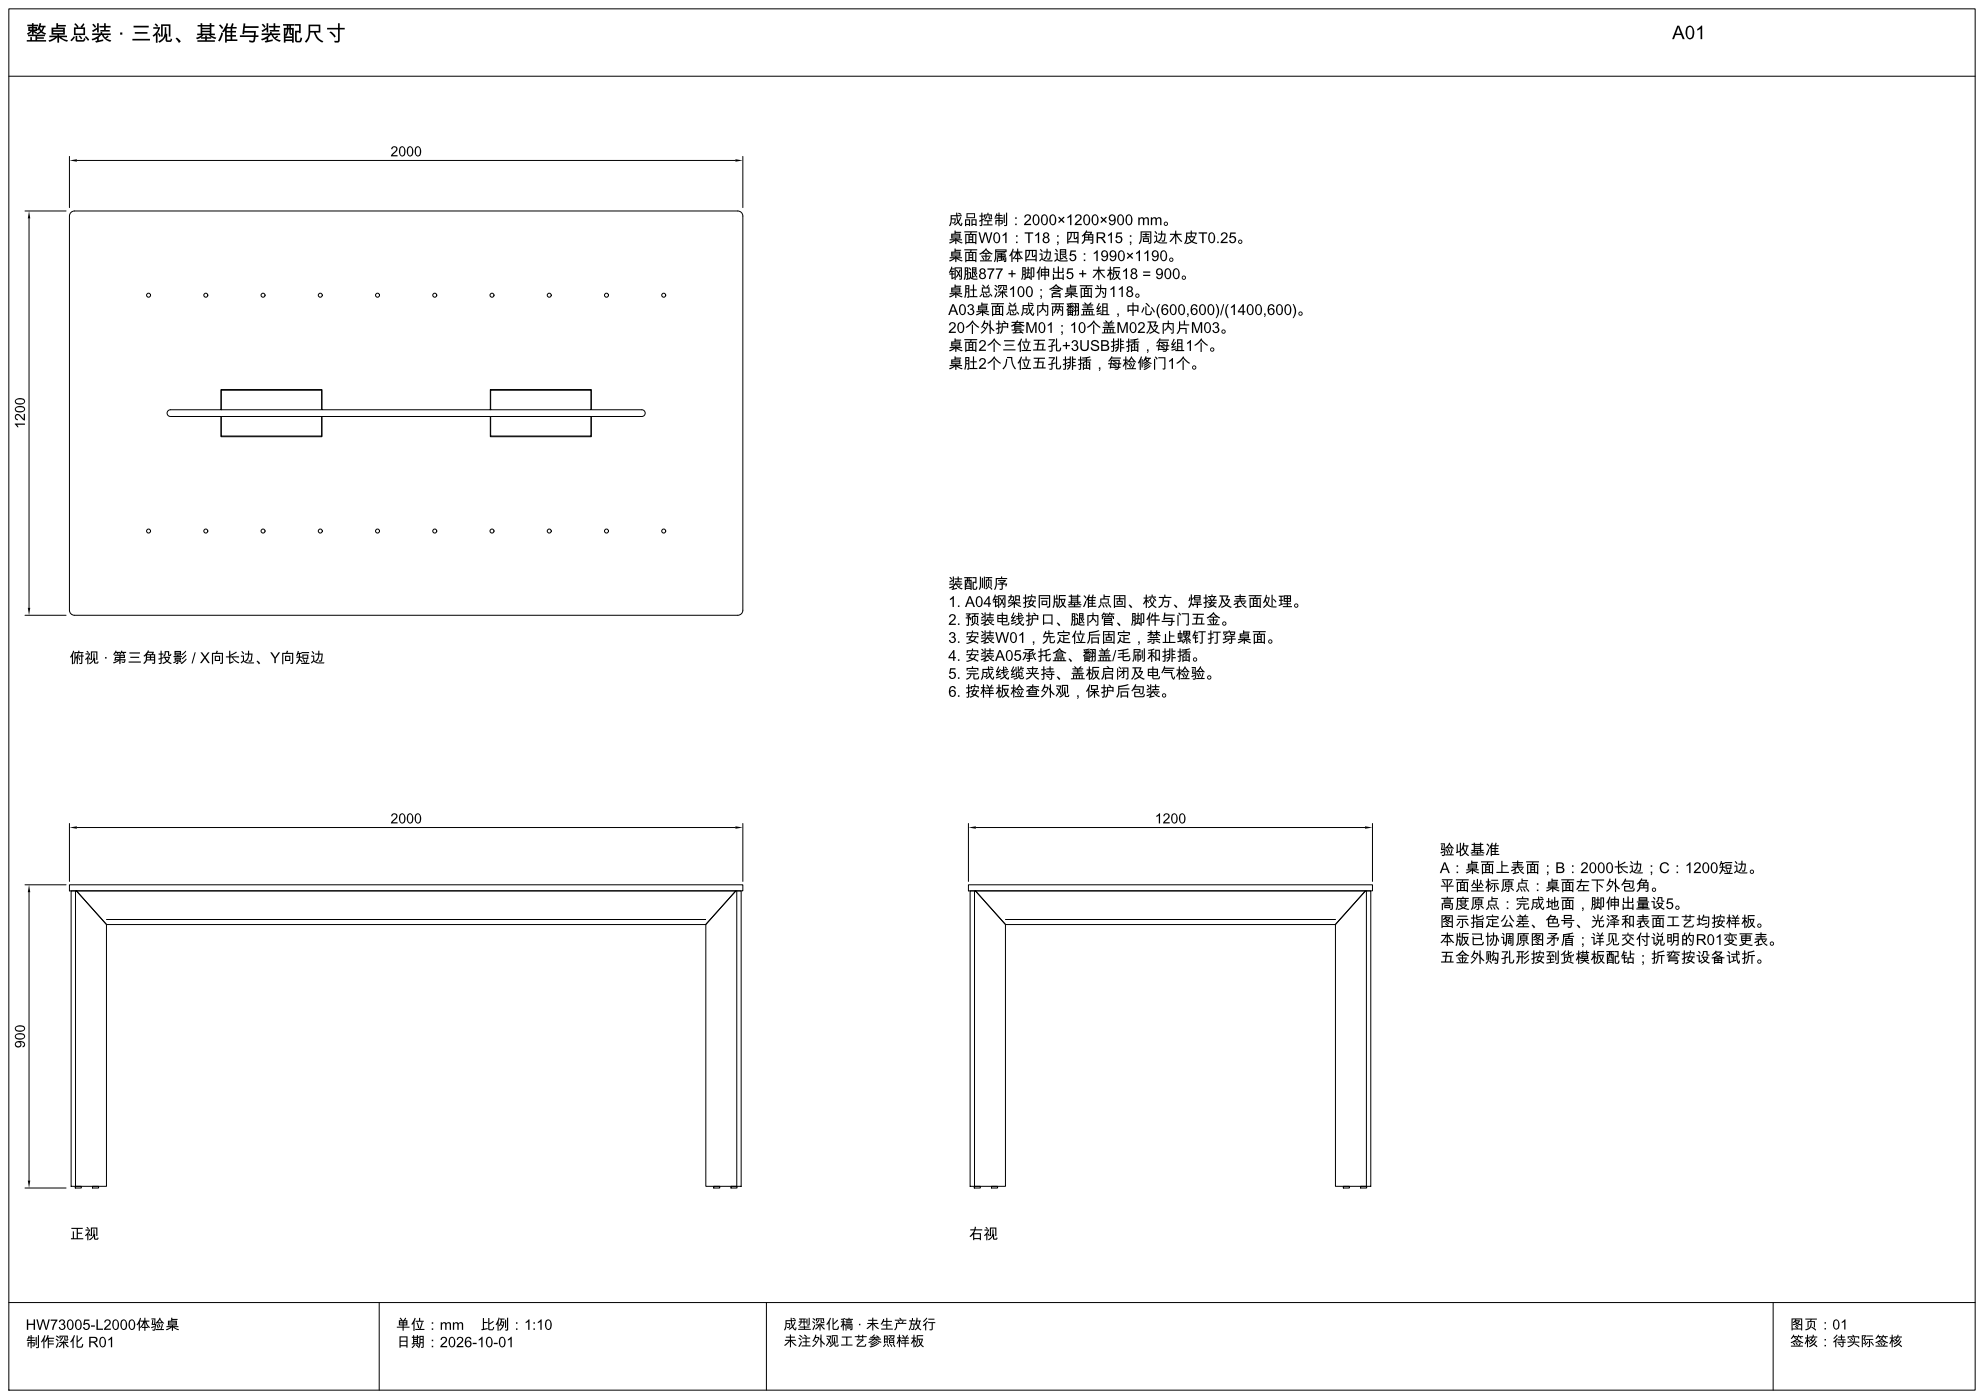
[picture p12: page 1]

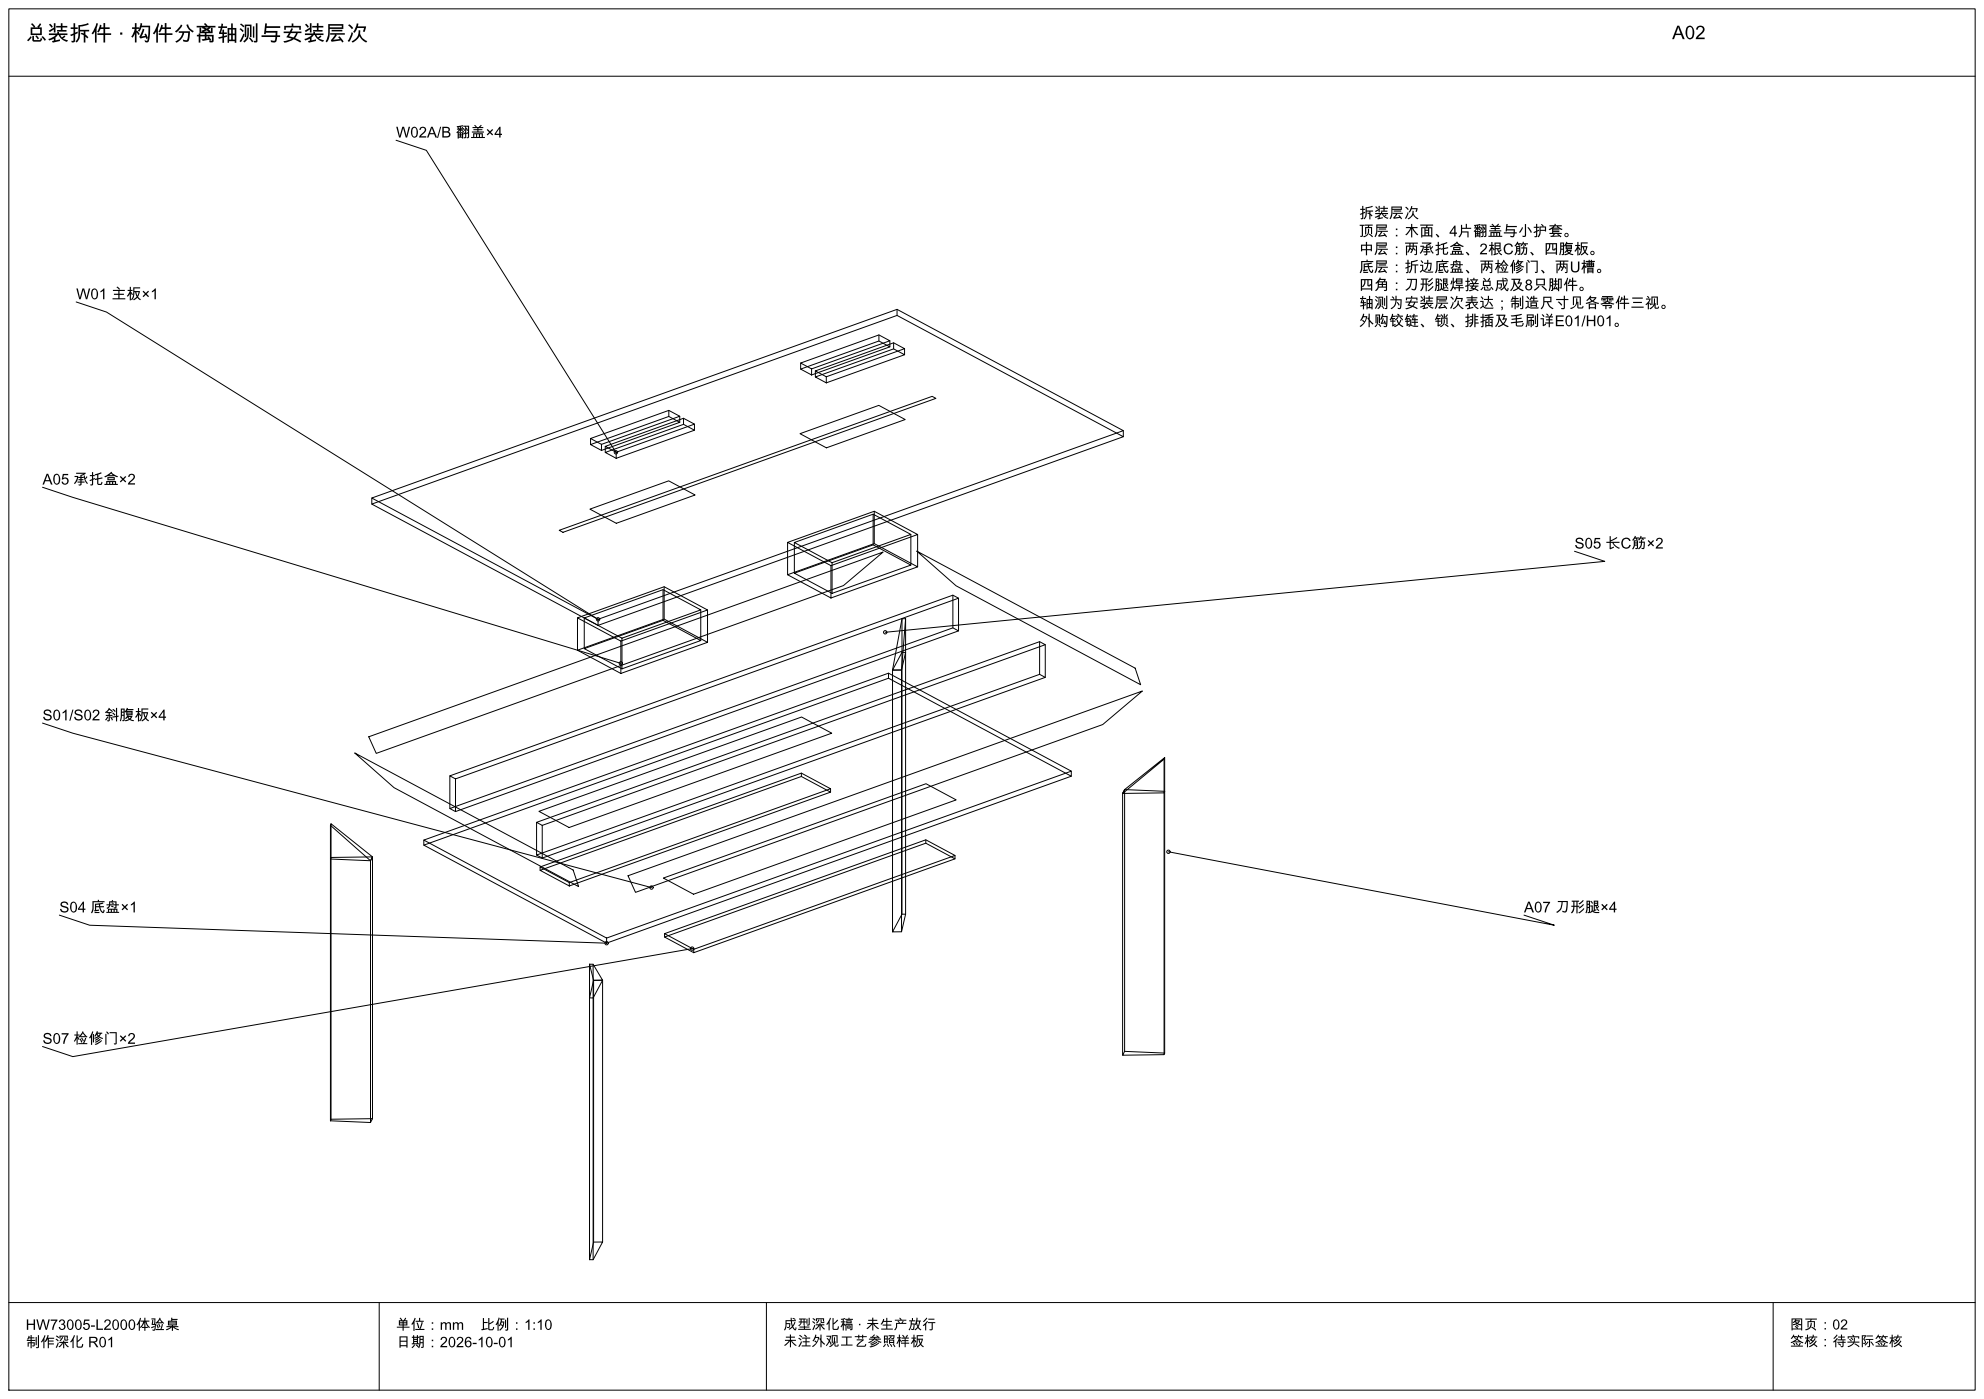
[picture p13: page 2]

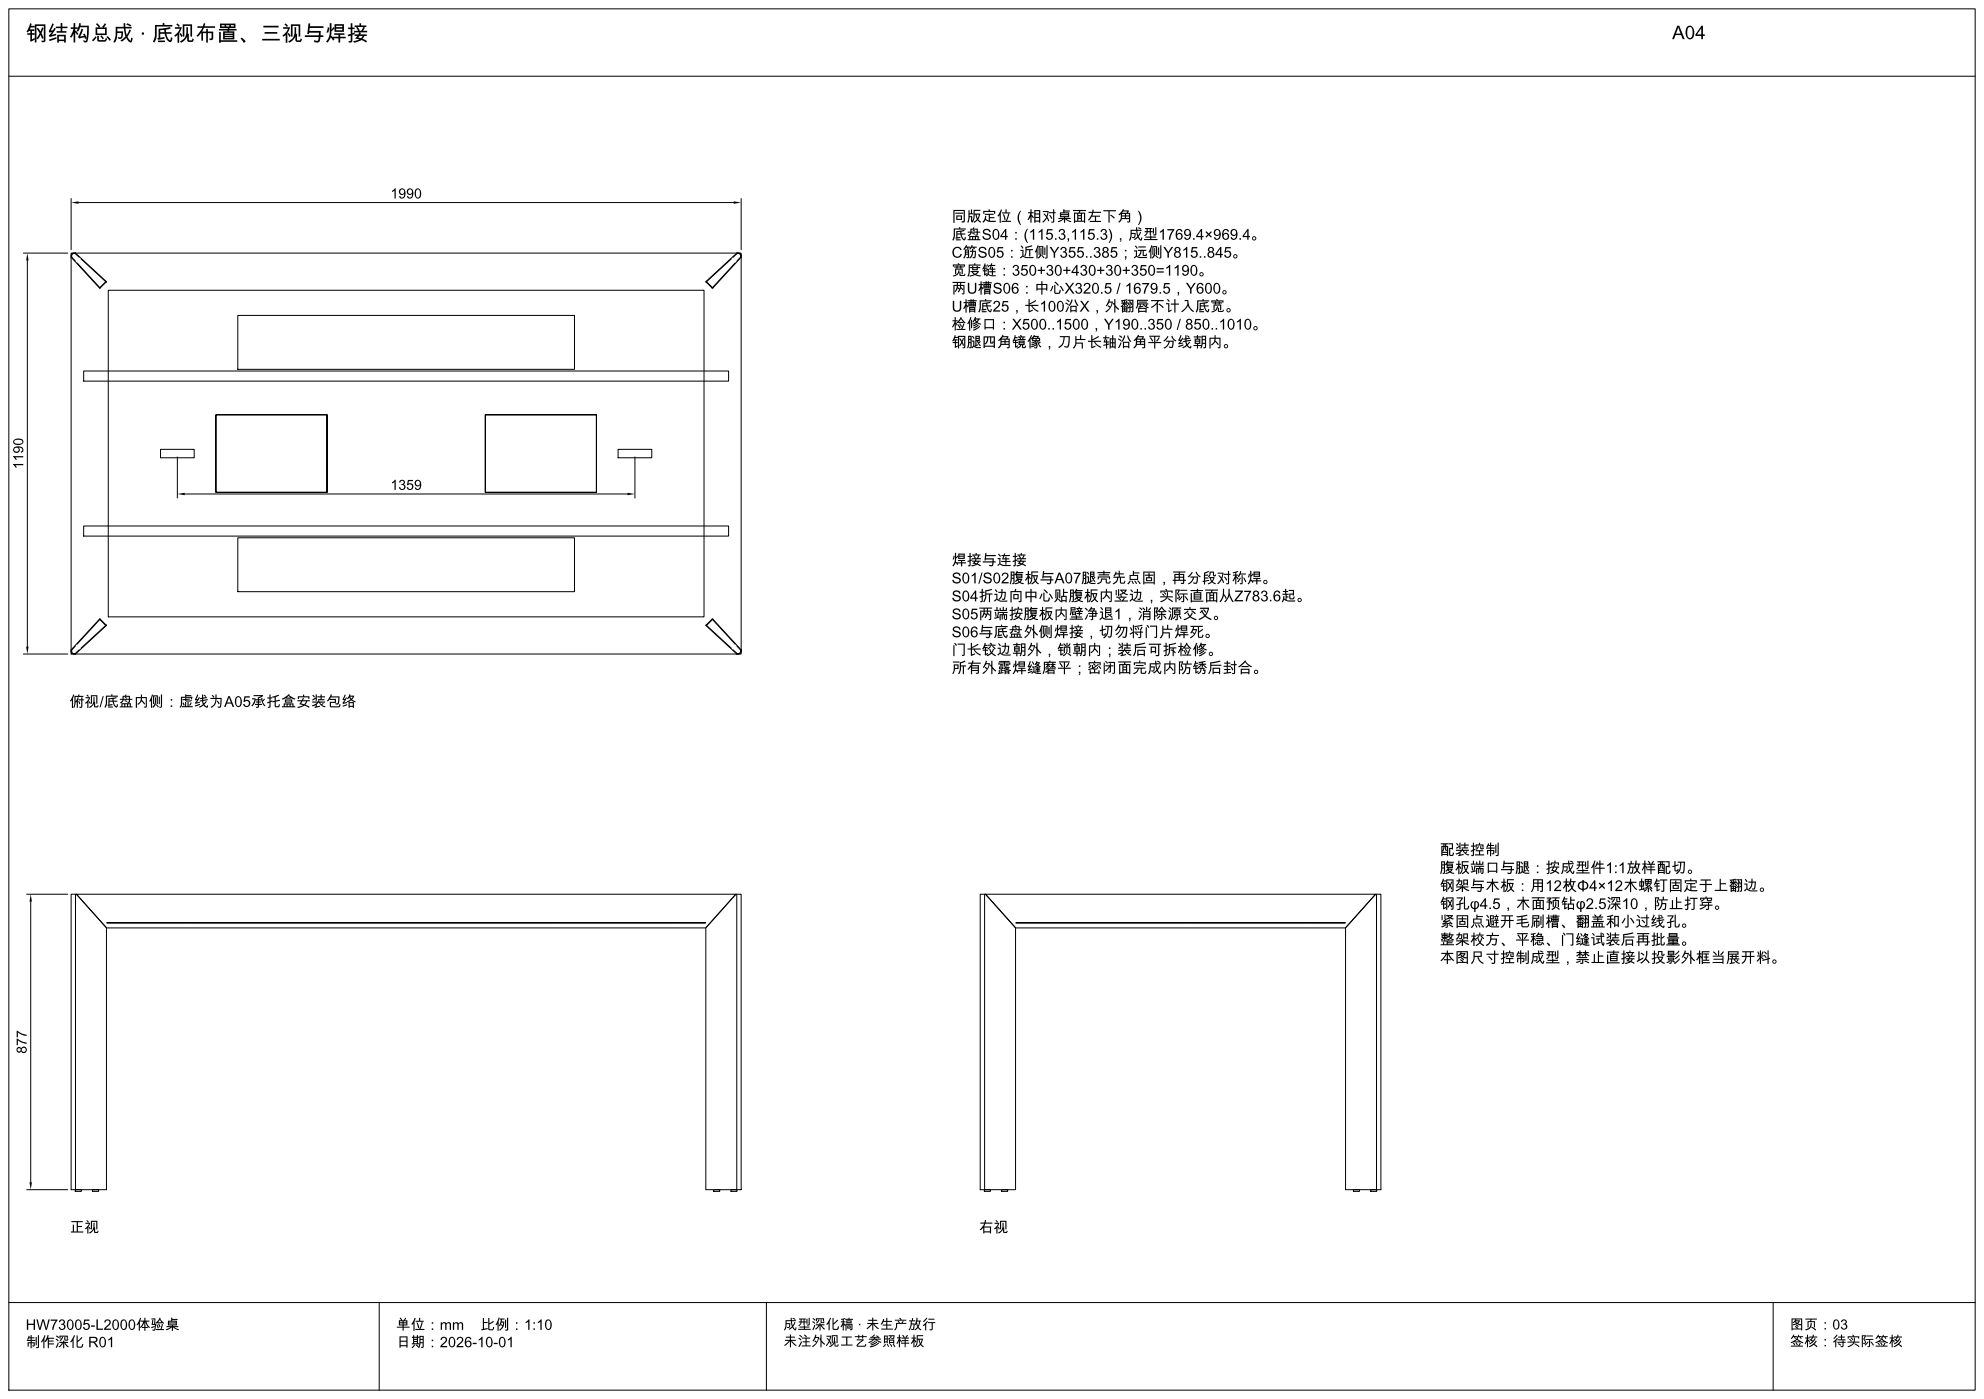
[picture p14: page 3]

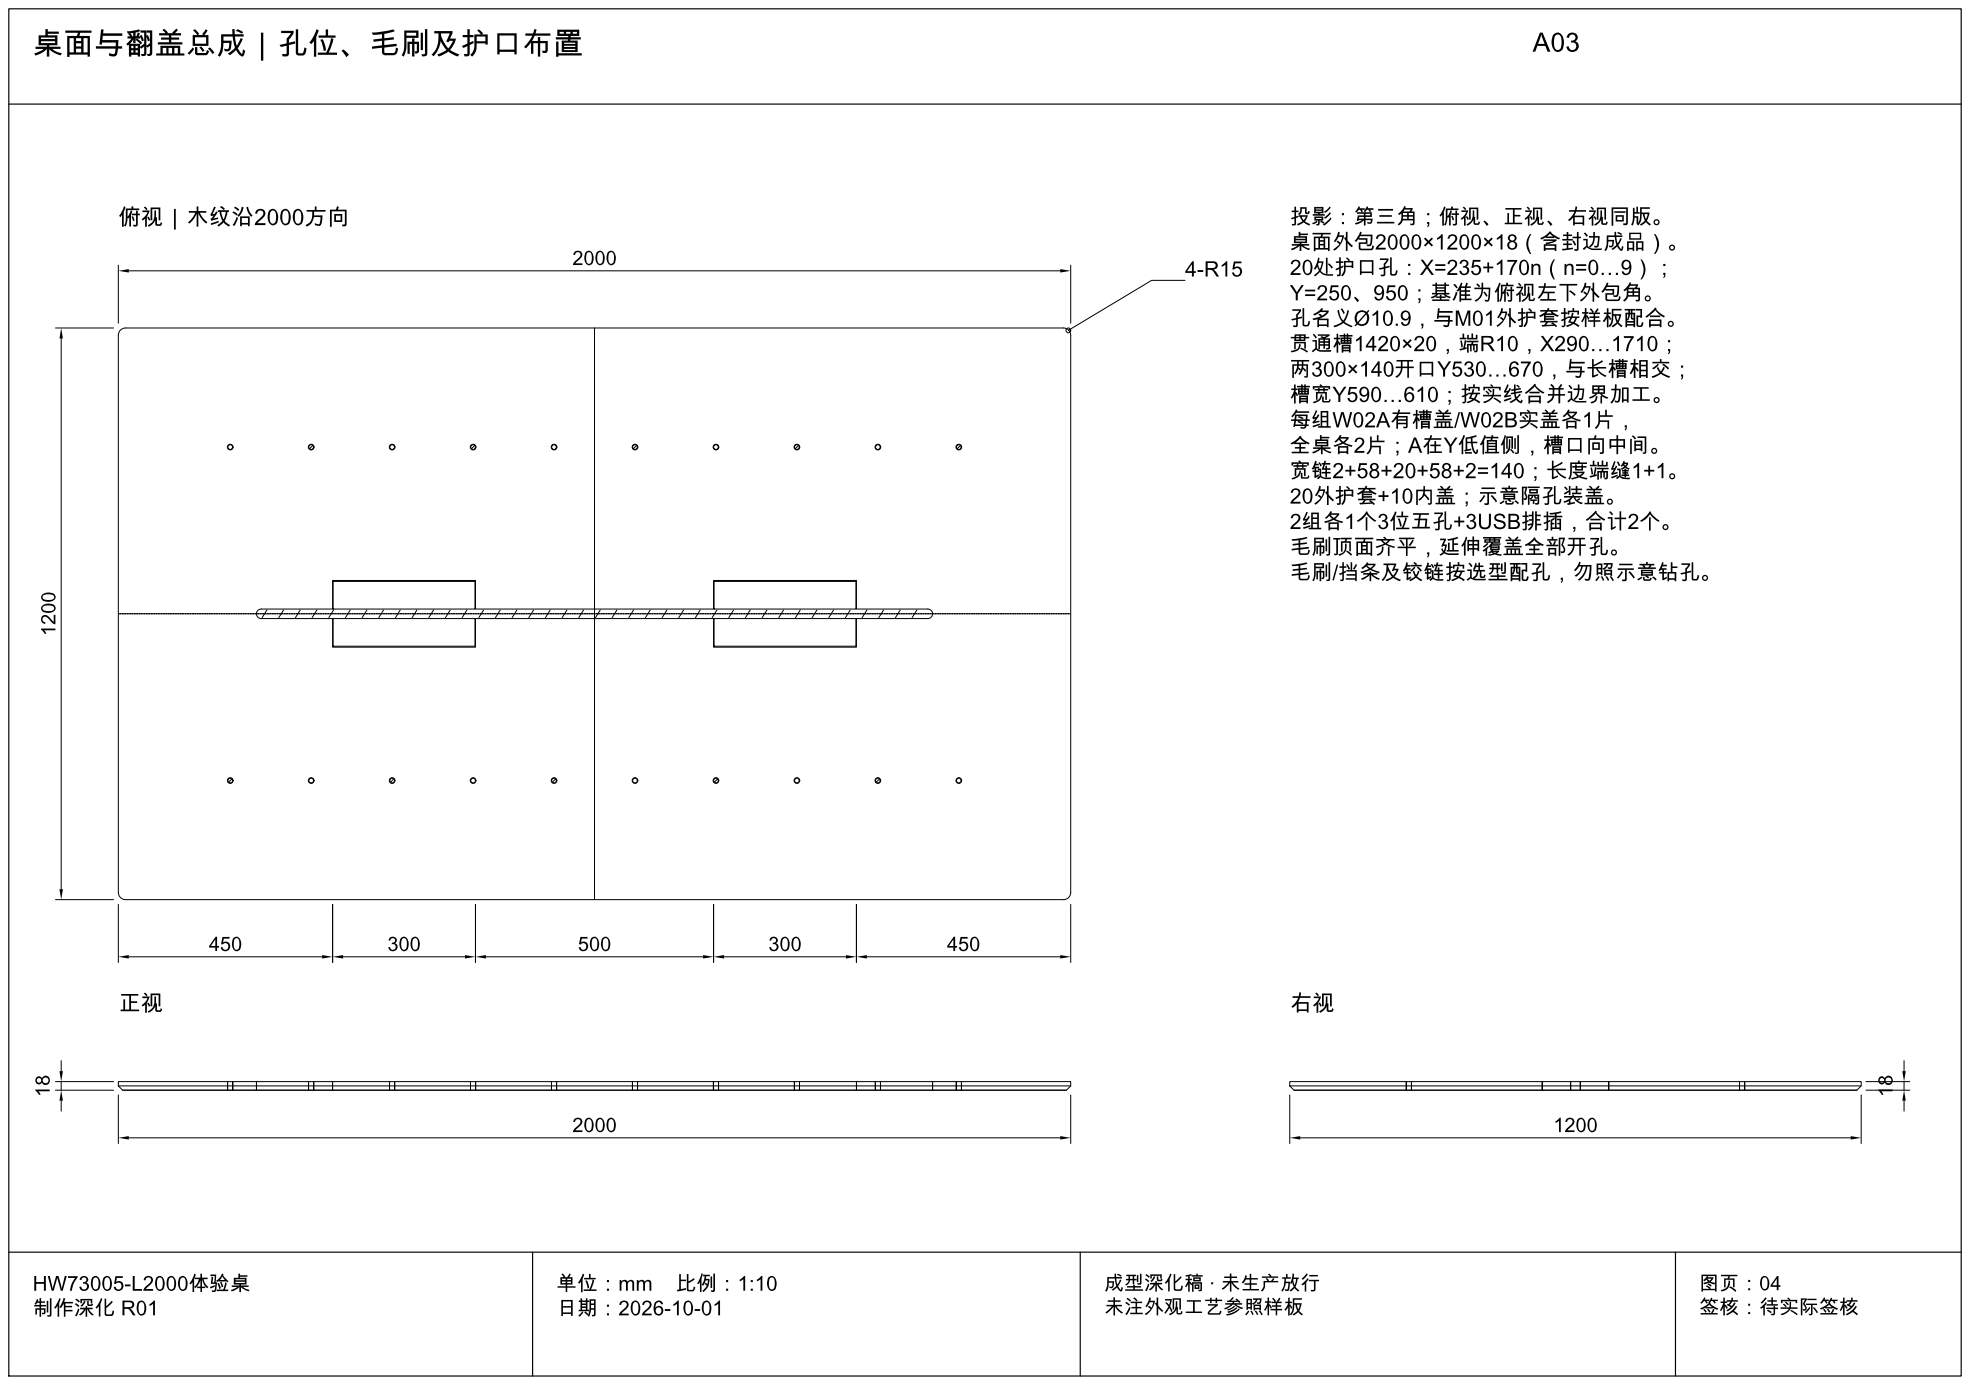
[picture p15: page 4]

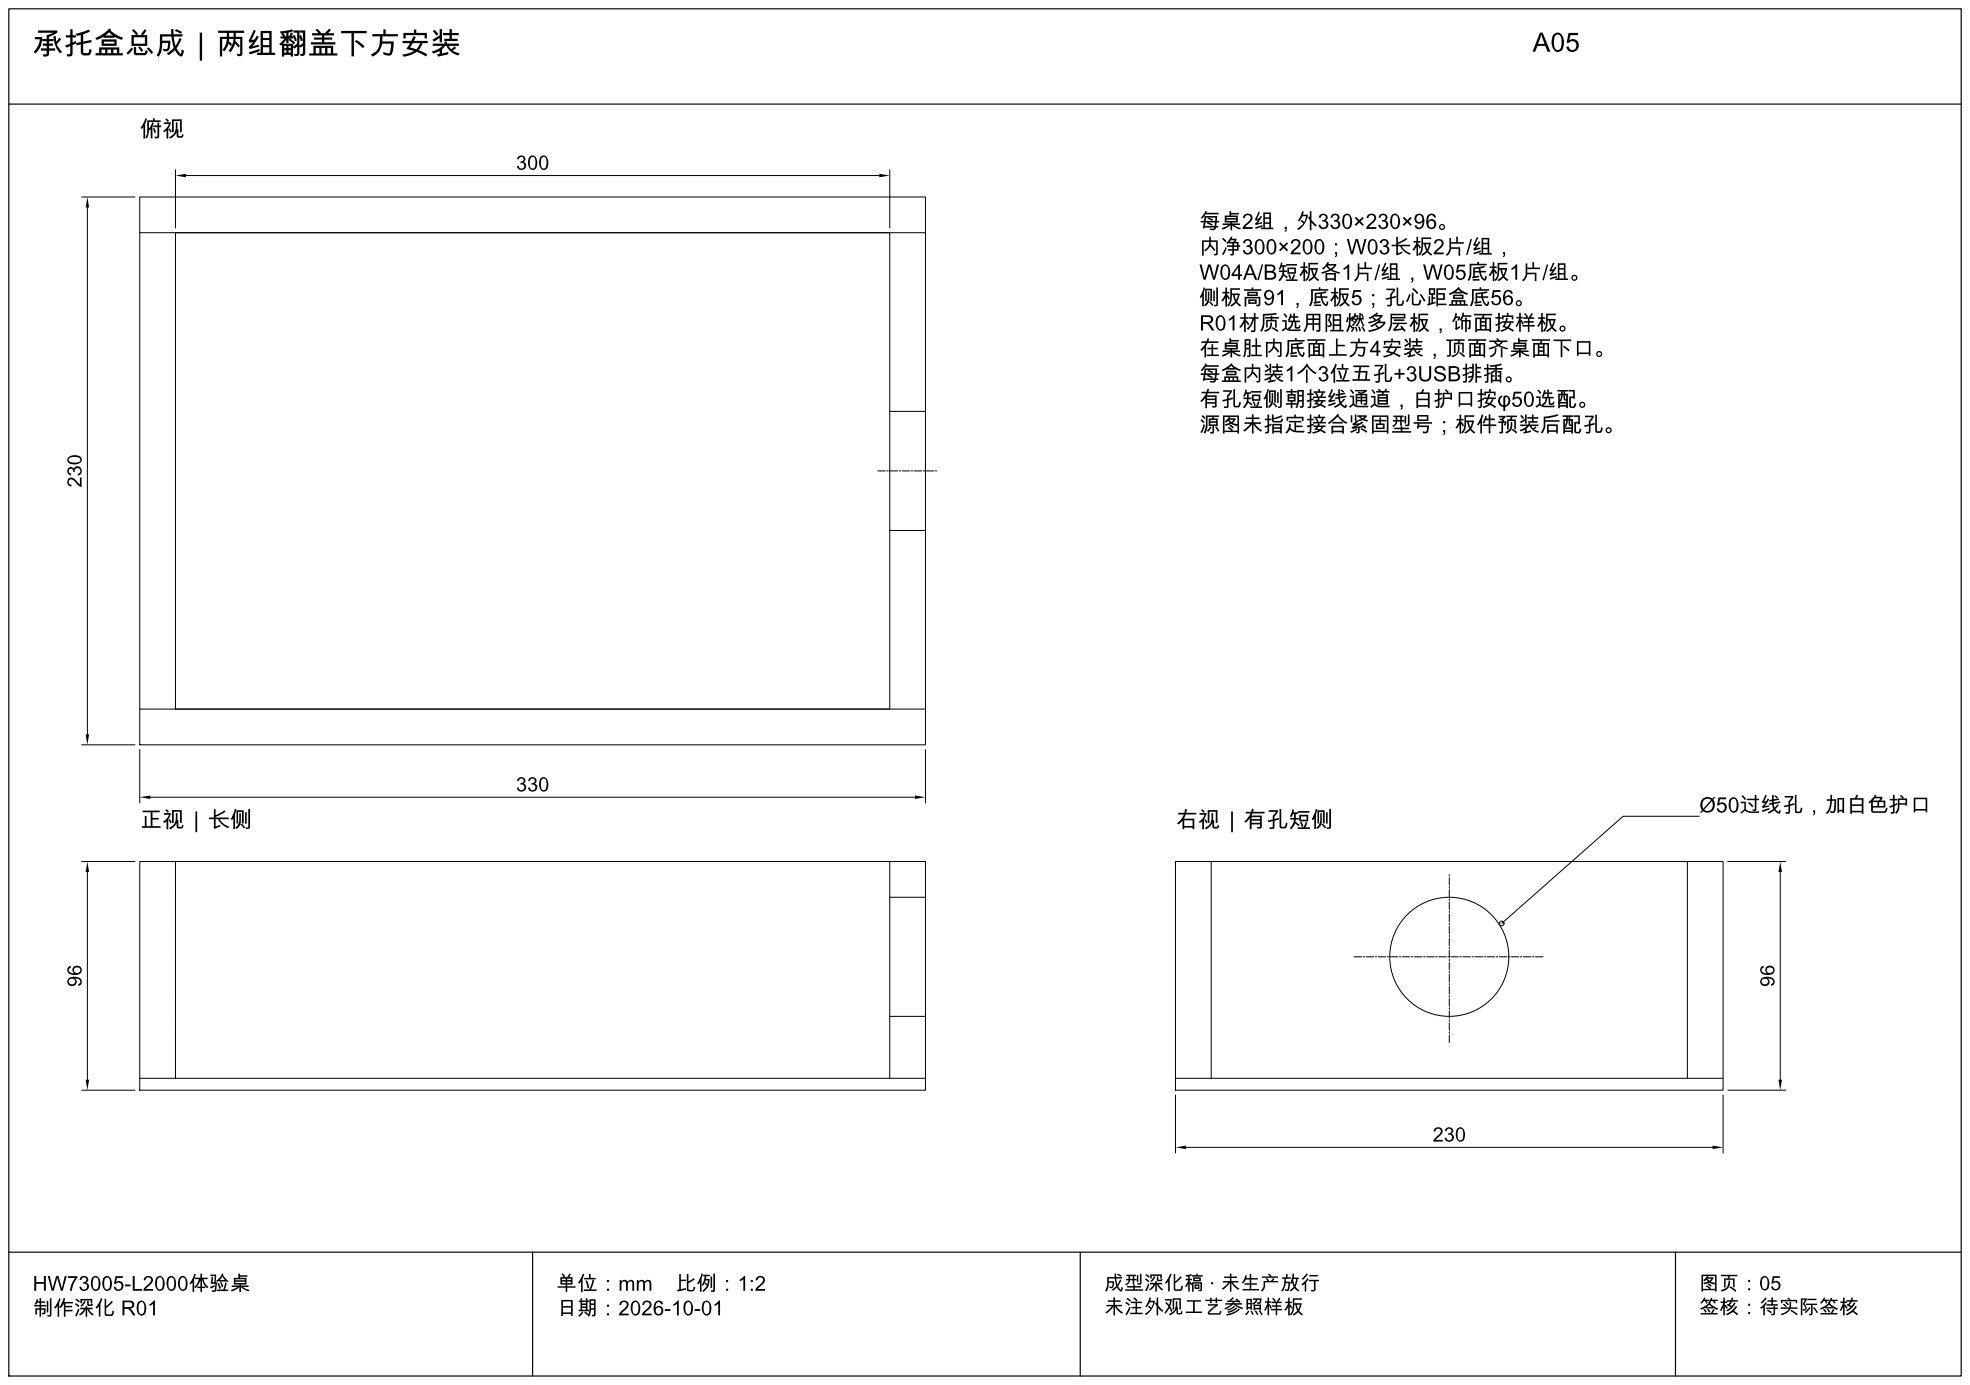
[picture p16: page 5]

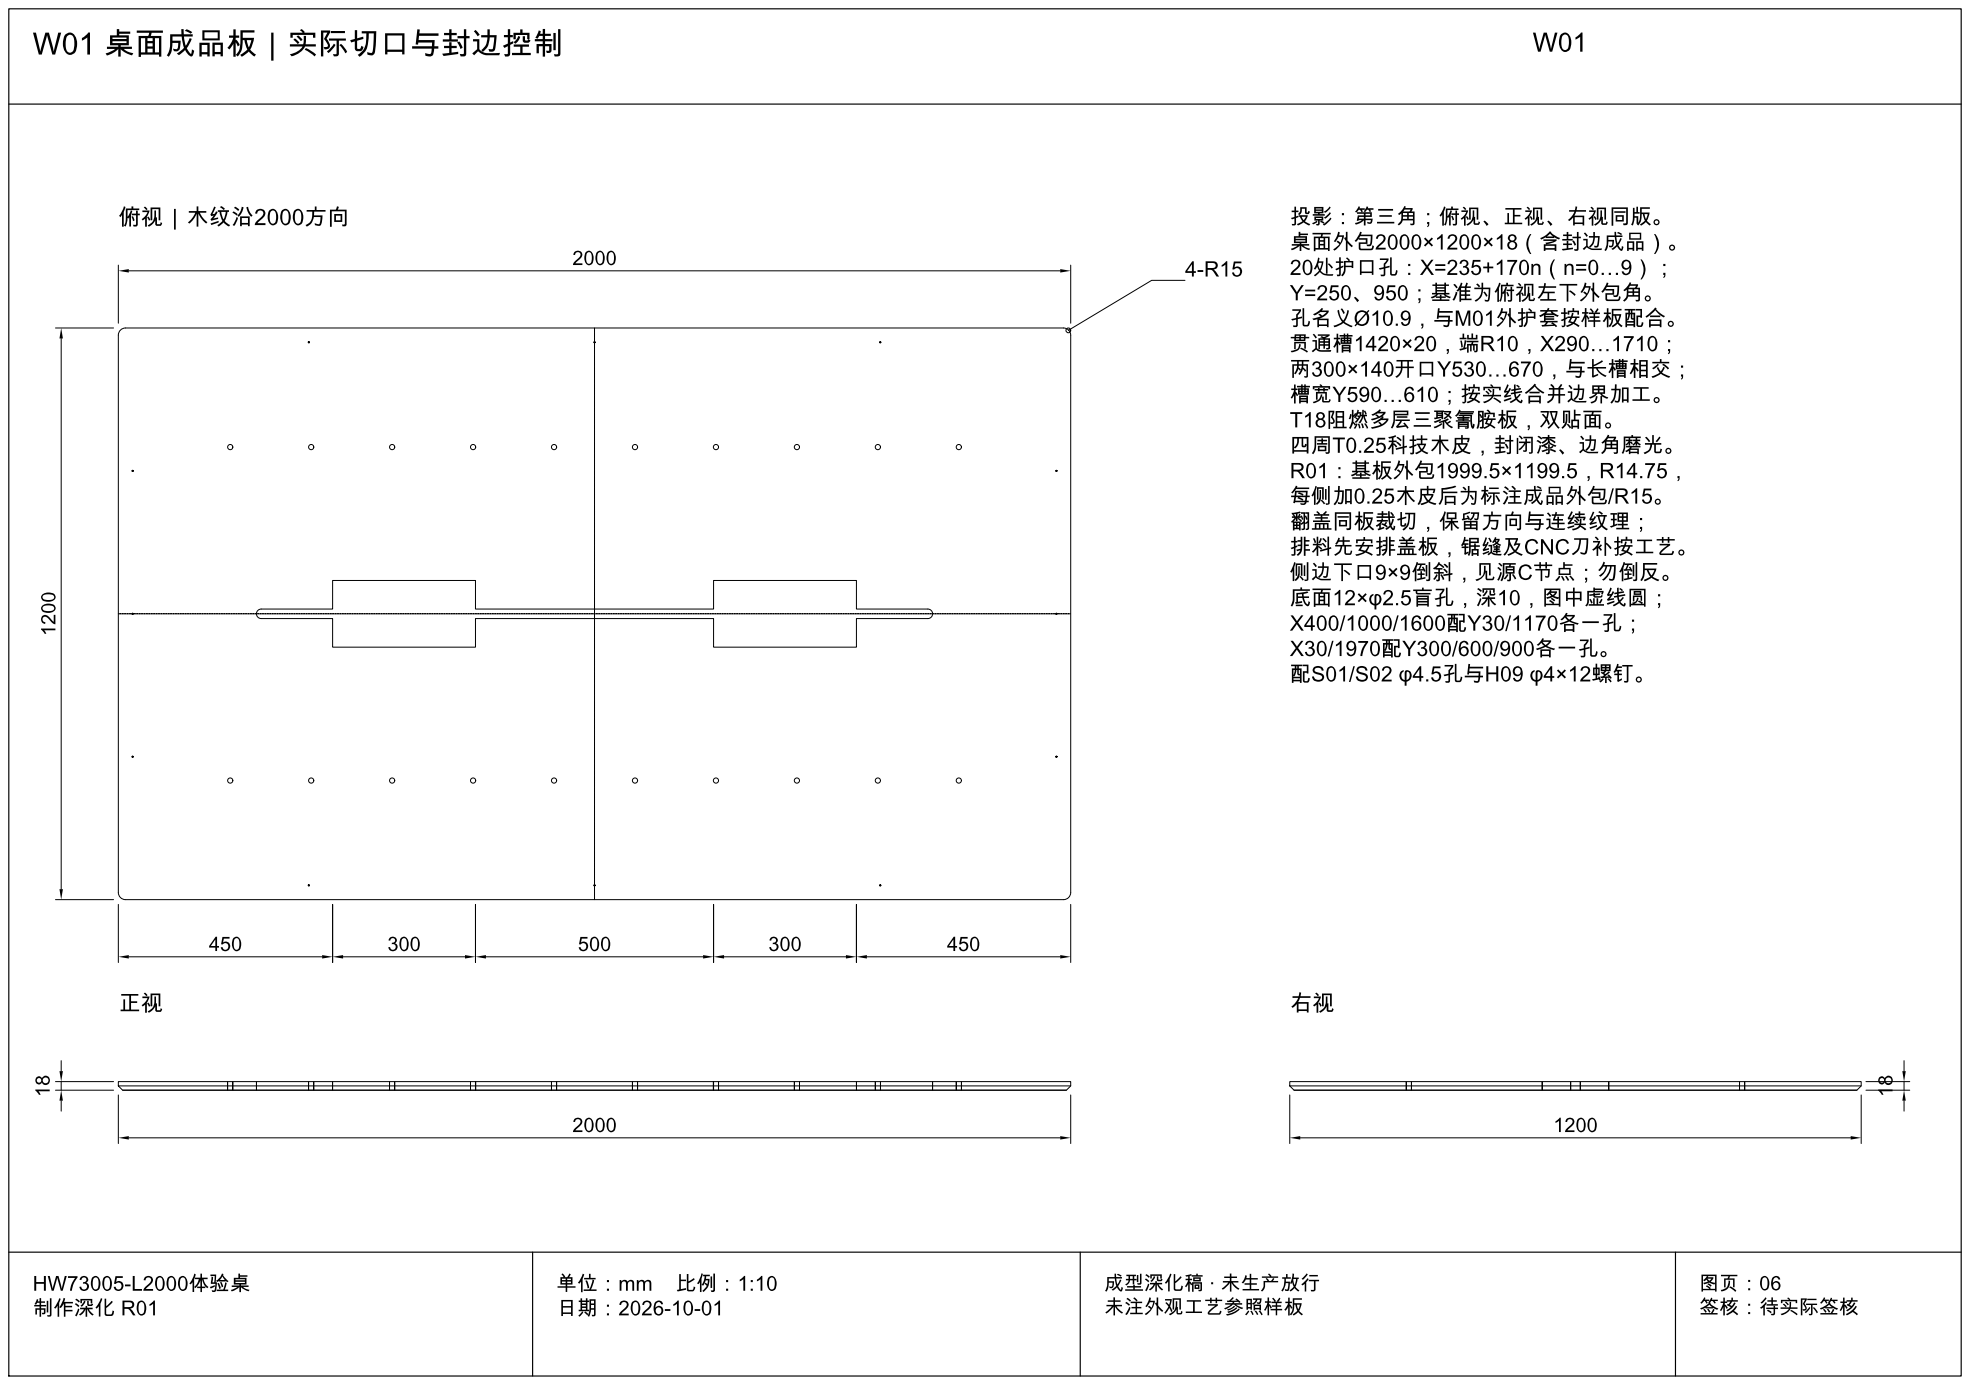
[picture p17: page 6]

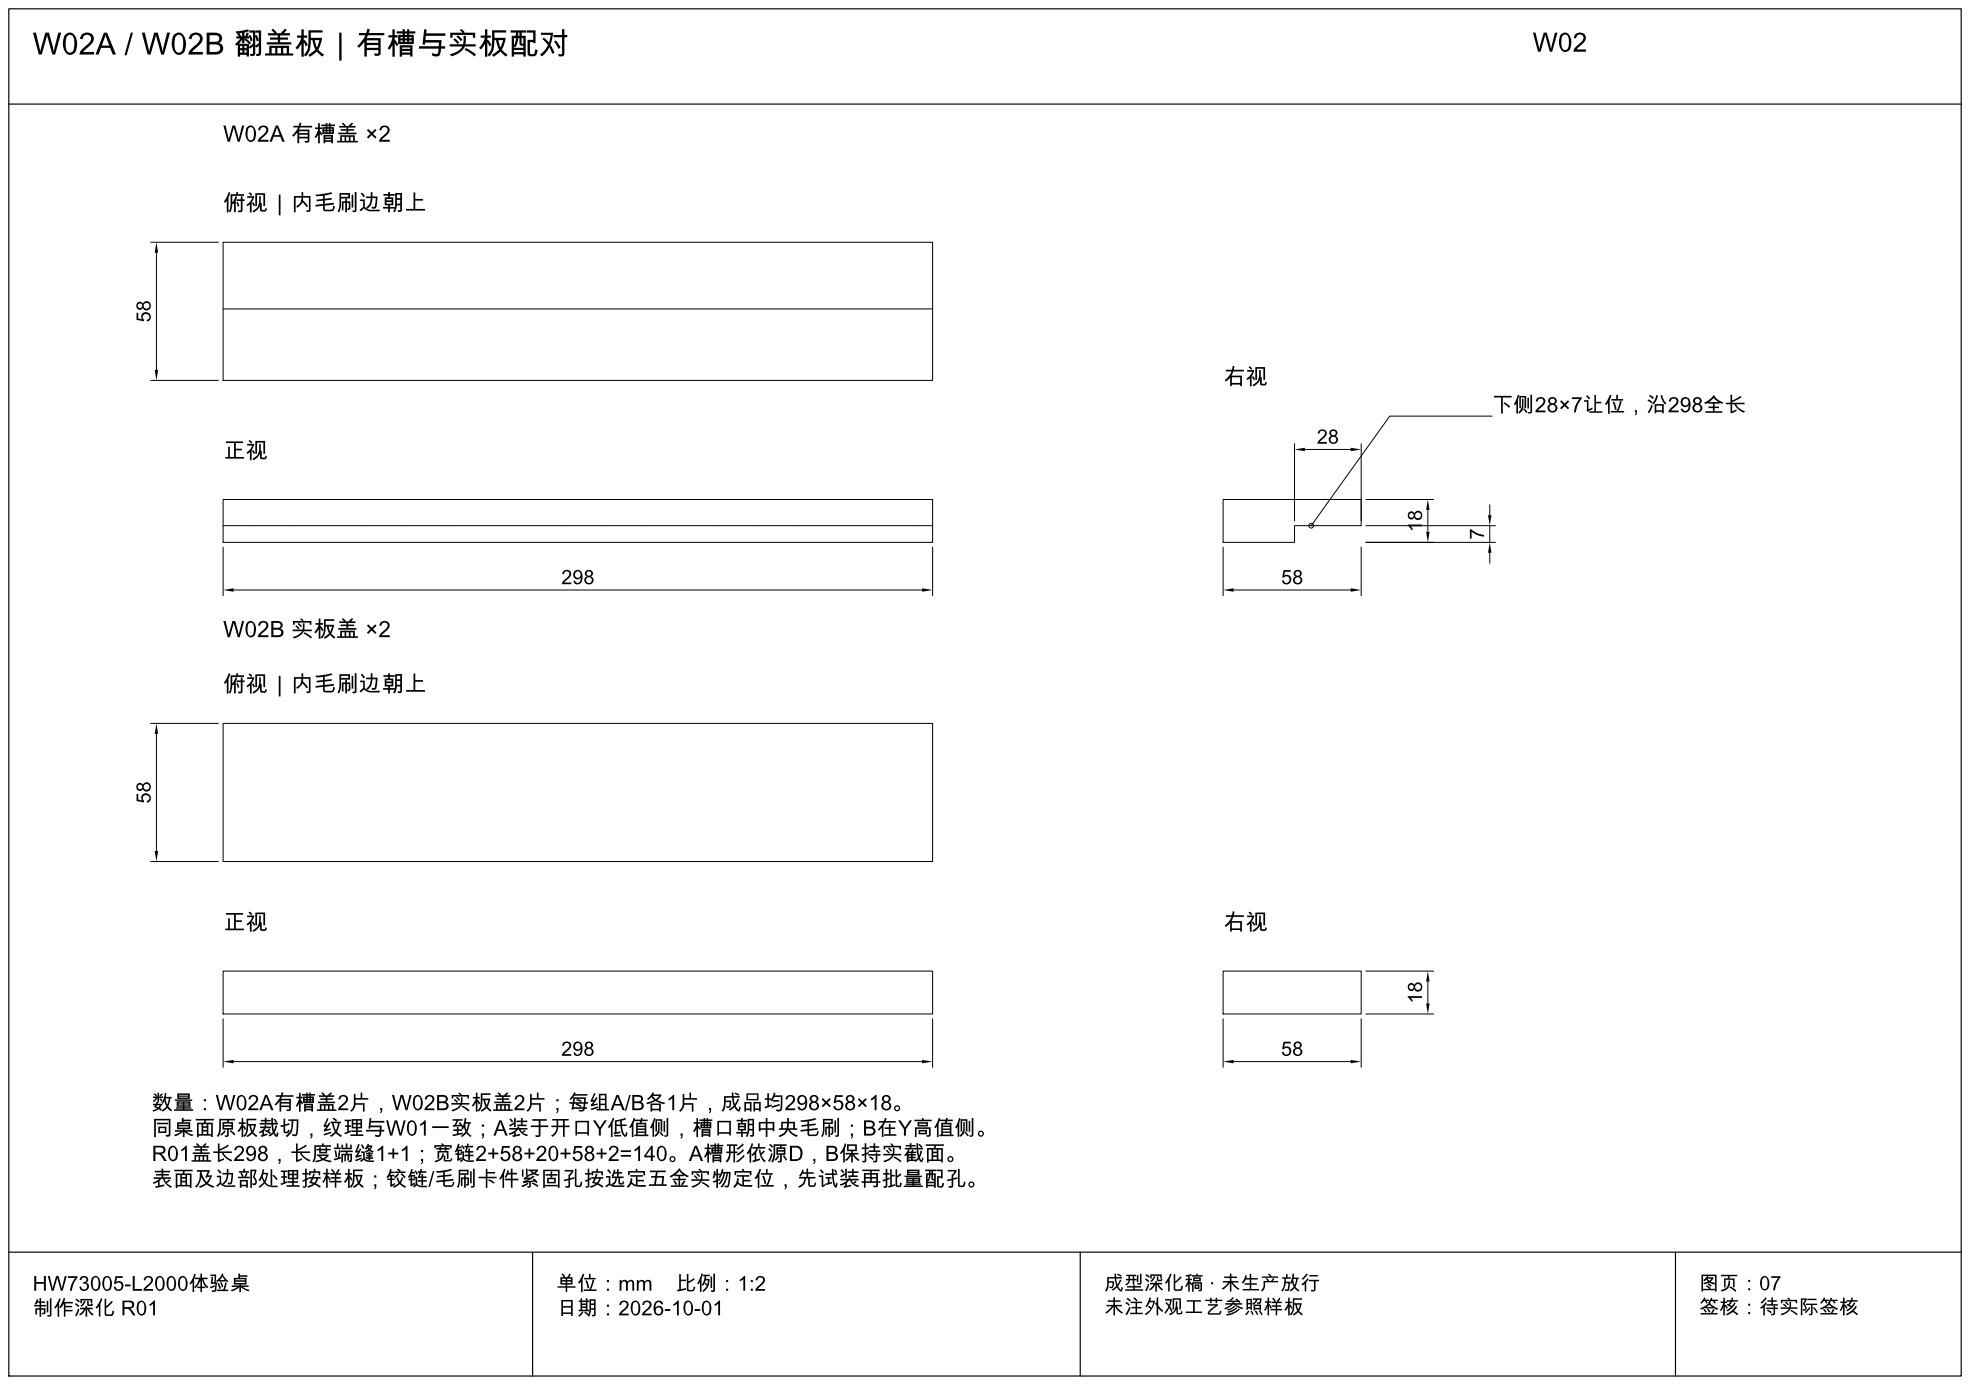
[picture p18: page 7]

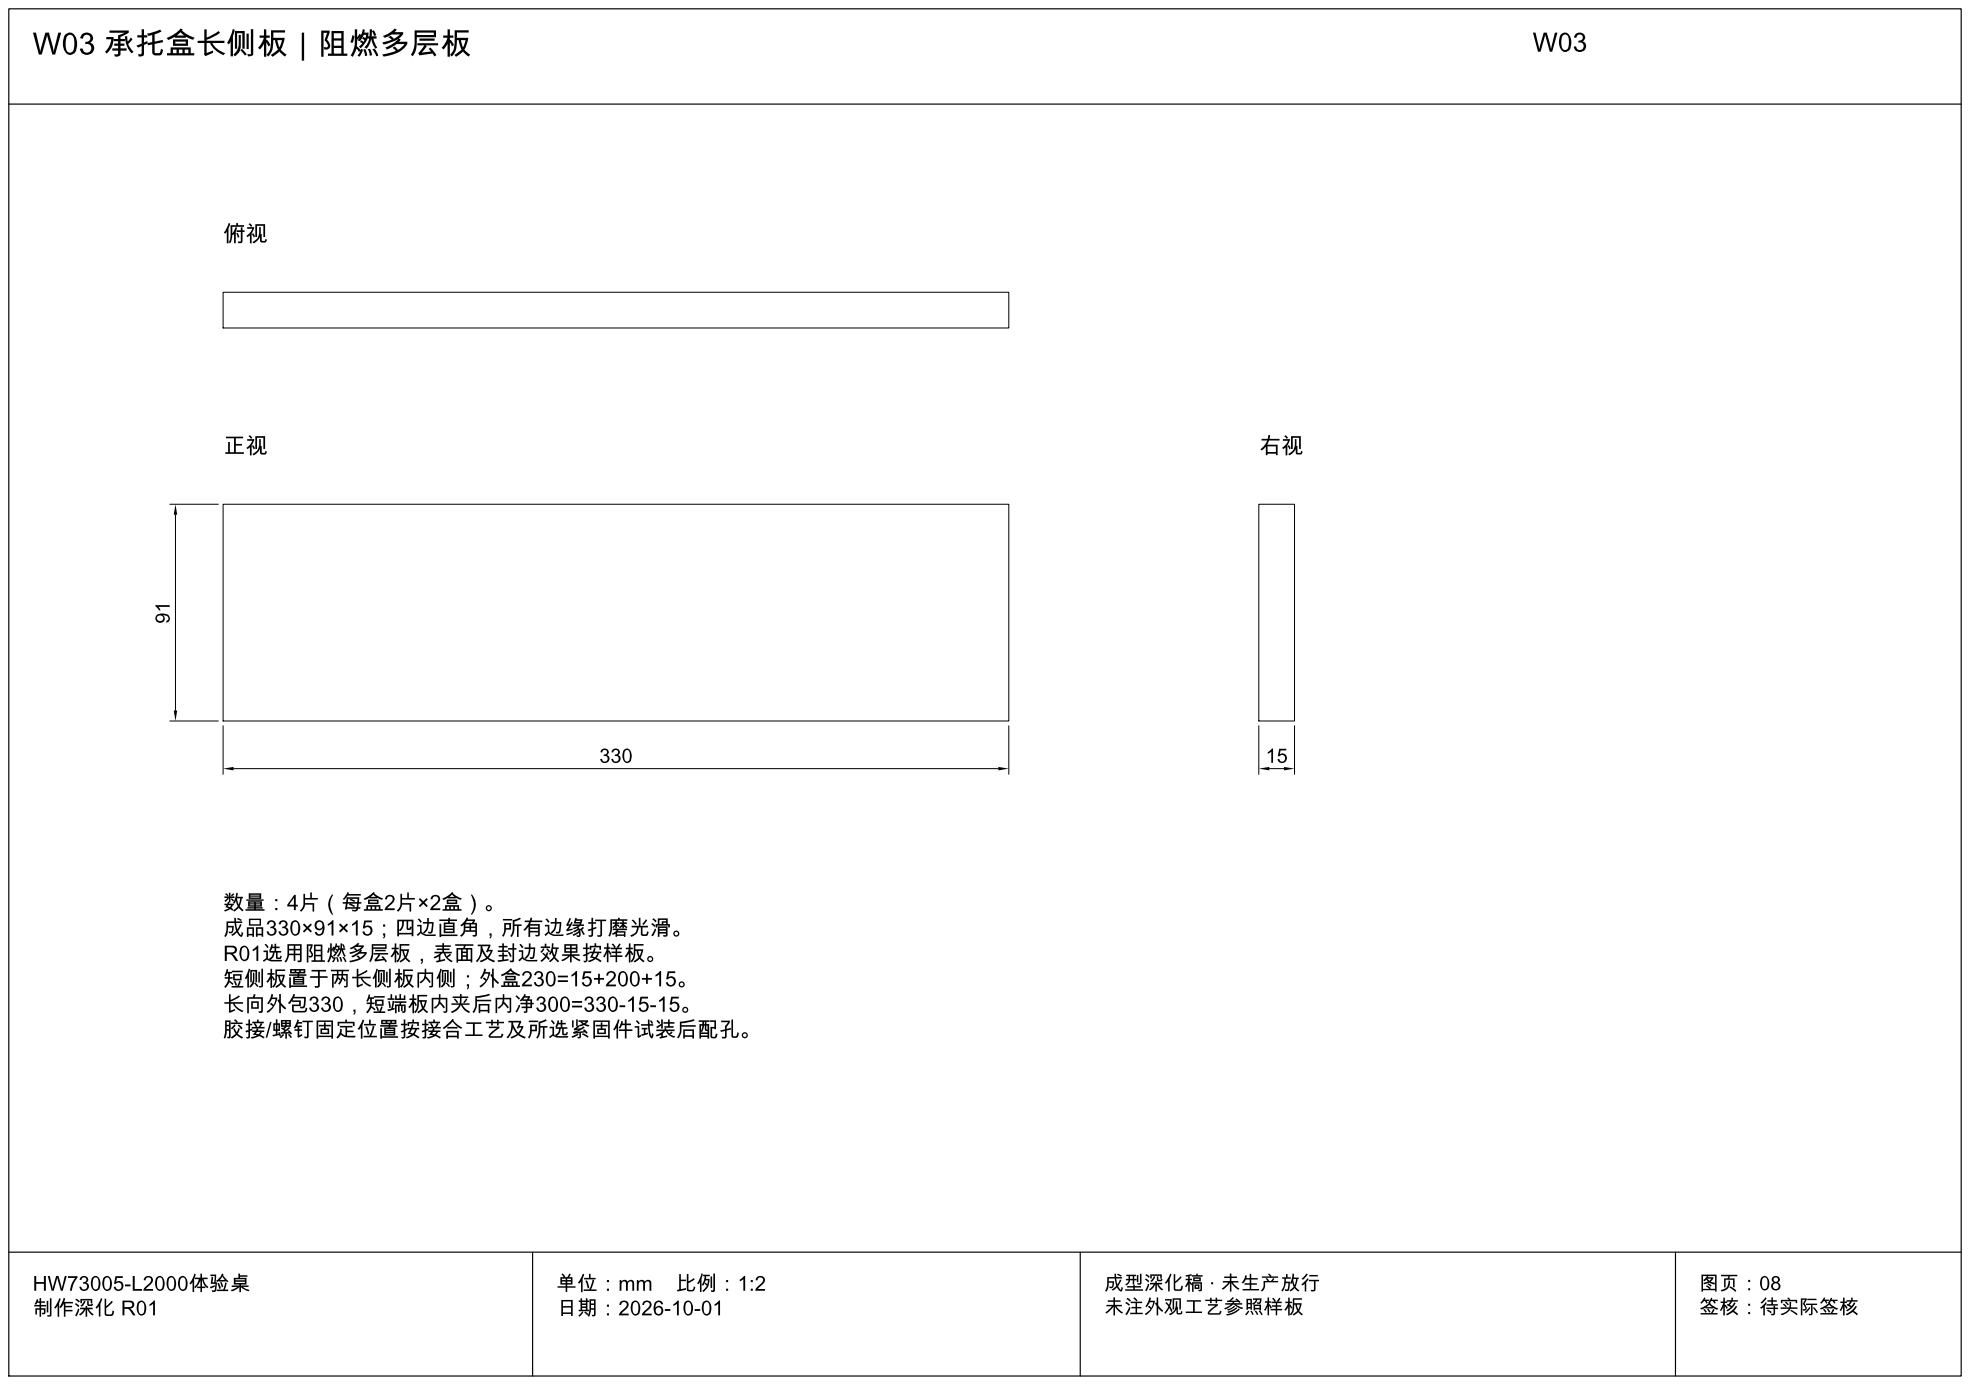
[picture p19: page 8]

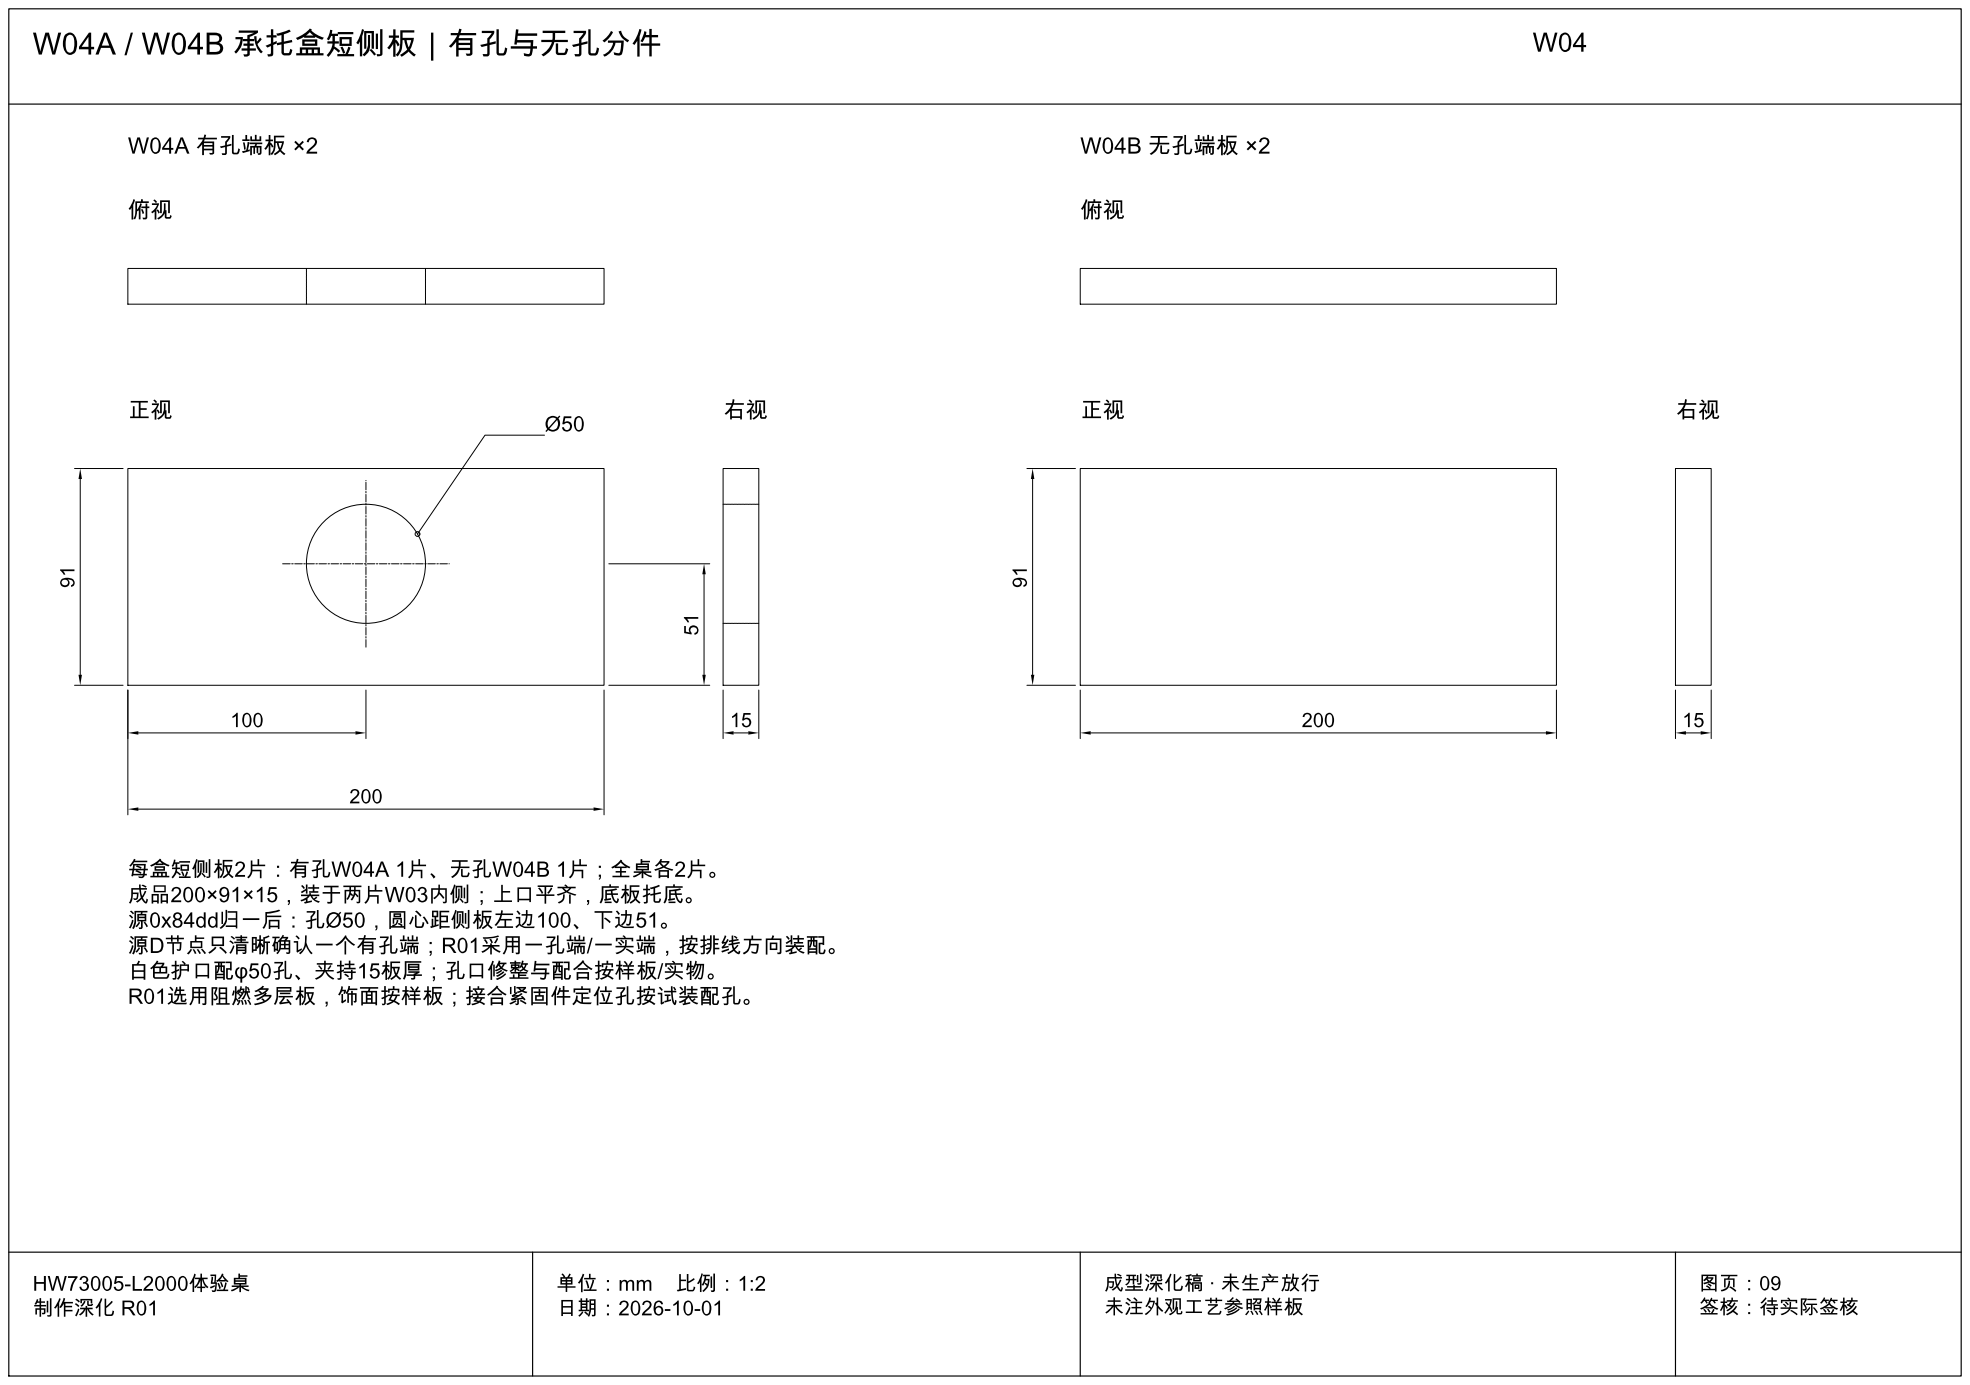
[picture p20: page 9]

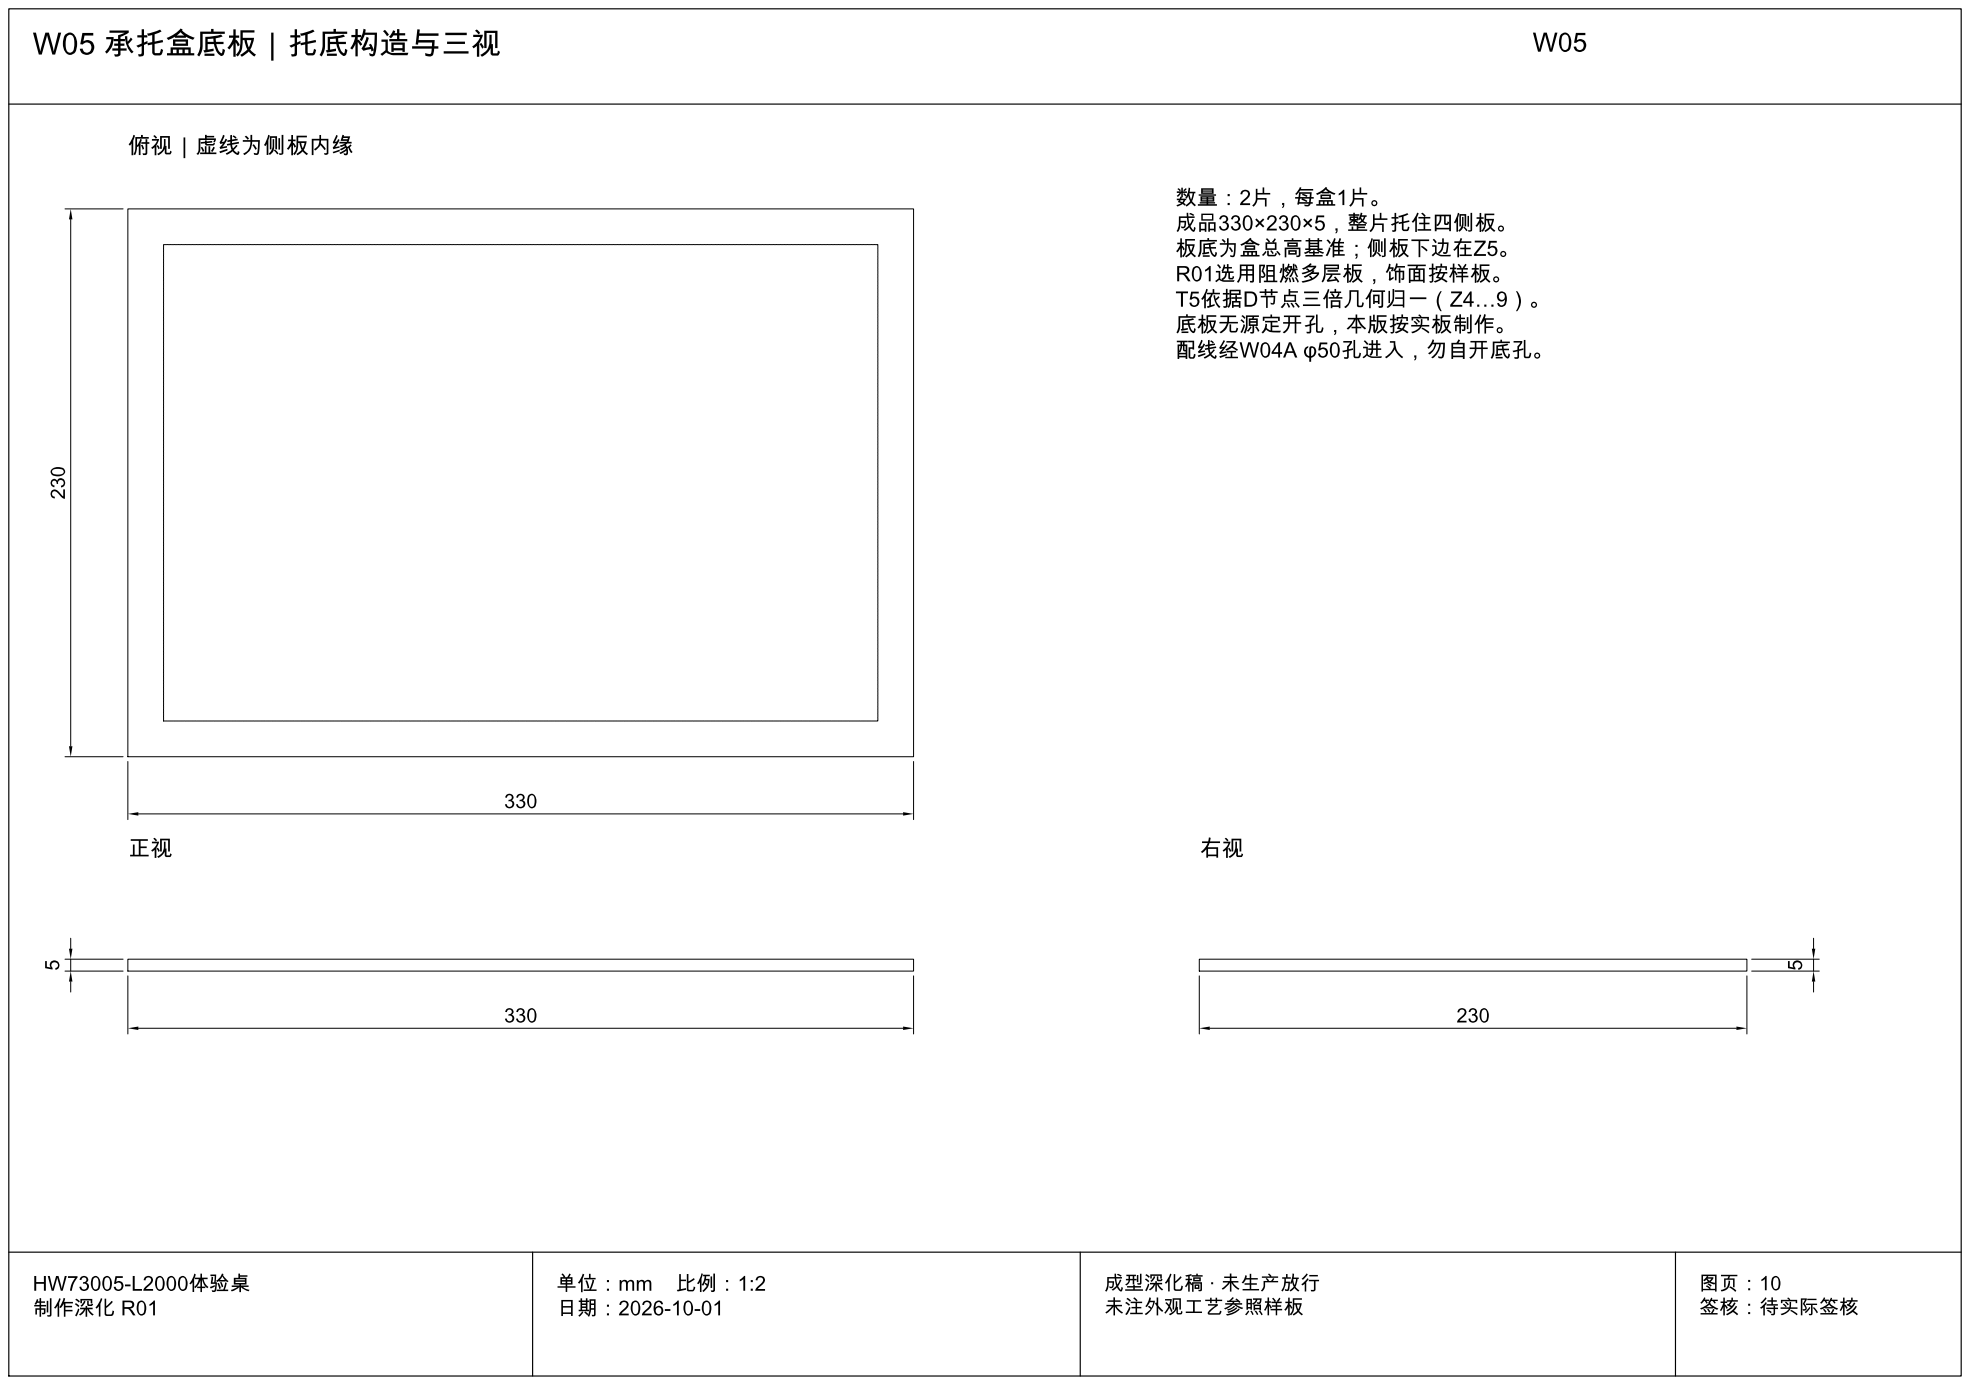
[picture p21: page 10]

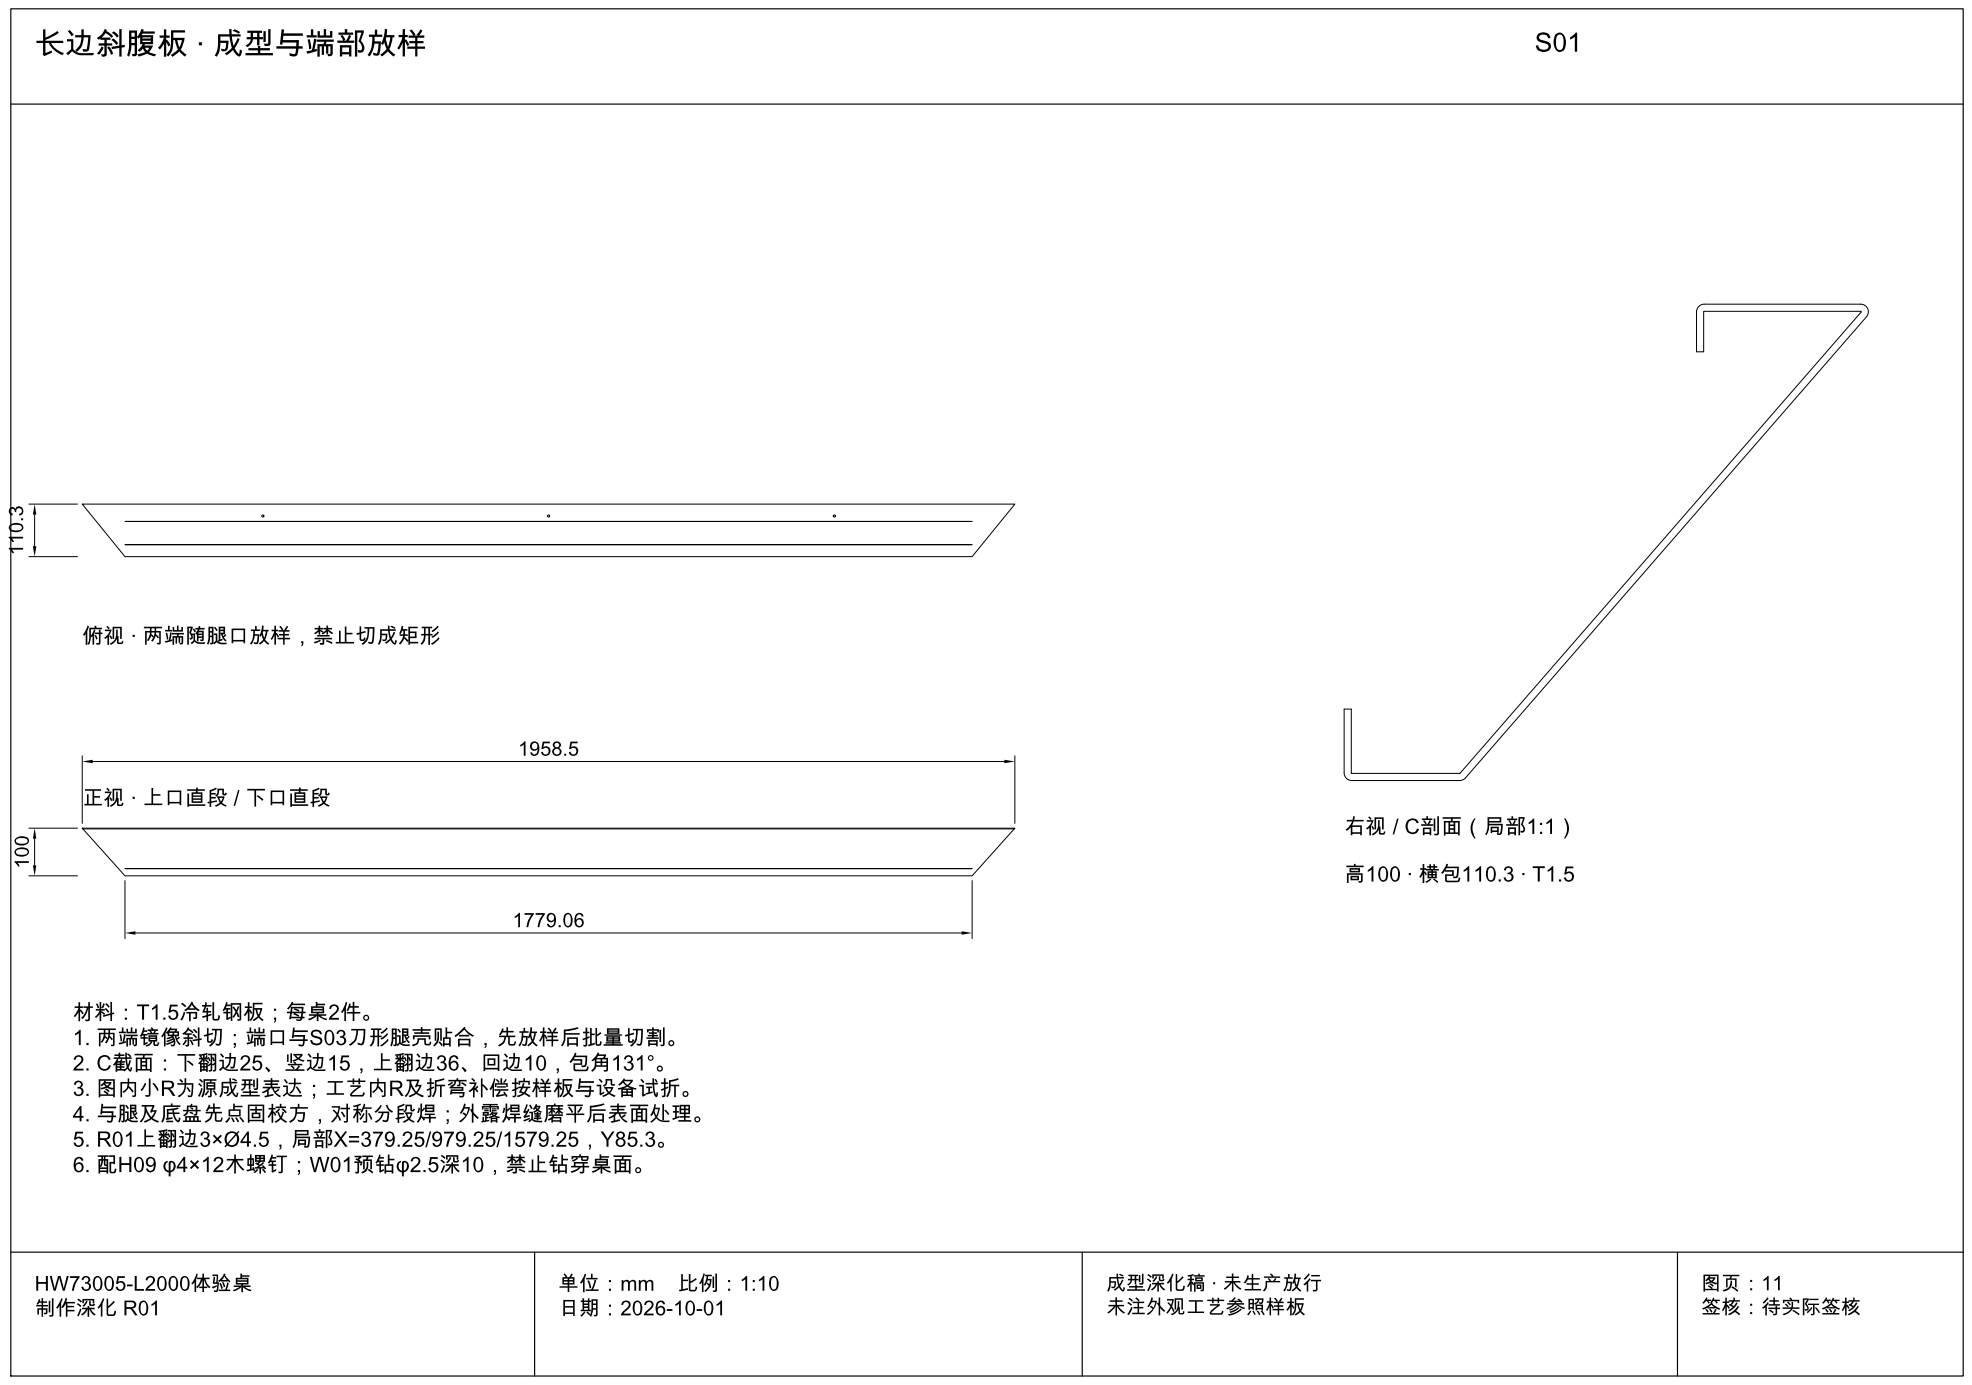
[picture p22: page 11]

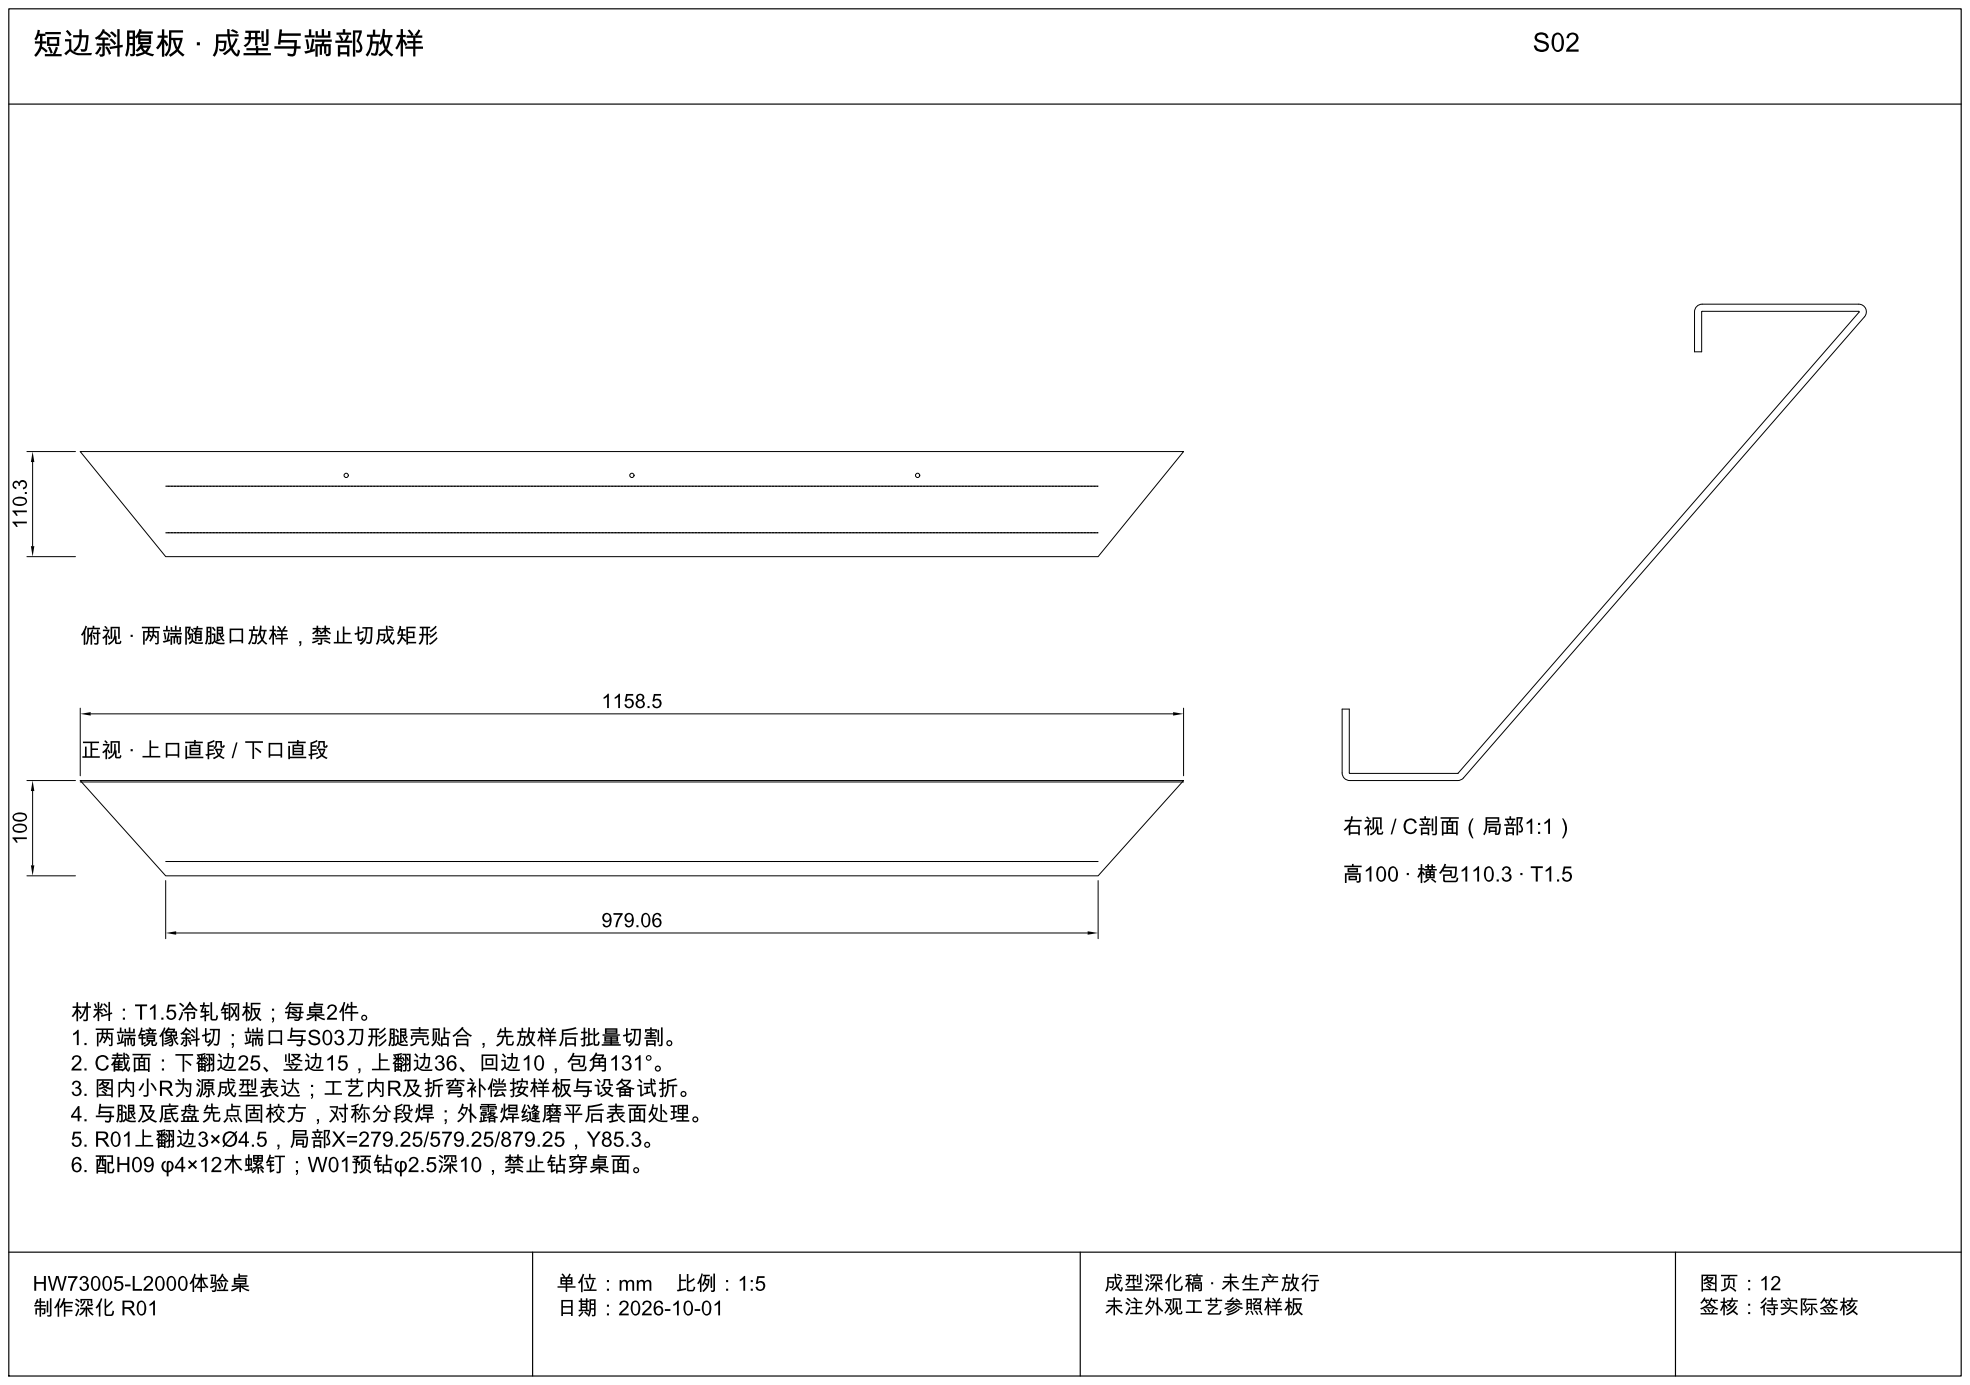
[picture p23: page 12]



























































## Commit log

2026-10-01 交付: 发布体验桌R01成型深化图册与清单
    [HW73005-L2000_R01.dwg, HW73005-L2000_R01_BOM.xlsx]
2026-10-01 交付: 发布体验桌R02检修深化与成品采购清单
    [HW73005-L2000_R02.dwg, HW73005-L2000_R02_BOM.xlsx, HW73005-L2000_R02_采购清单.xlsx]
2026-10-01 feat: 发布R03三维装配索引与制作交付包
    [HW73005-L2000_R03.dwg, HW73005-L2000_R03_BOM.xlsx, HW73005-L2000_R03_三维装配.dwg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]
2026-10-01 fix: 按版次刷新交付页资源缓存
2026-10-02 feat: 发布 HW73005 R04 制造审核交付资料
    [HW73005-L2000_R04.dwg, HW73005-L2000_R04_部件与五金采购清单.xlsx, 下料与工序索引.csv]
2026-10-02 docs: 发布AI接单能力蒸馏方案
2026-10-02 docs: 补充定制接单图纸模板与动态流程
2026-10-02 docs: 按接收人收紧制作图交付范围
2026-10-02 docs: 增加工程判断与反向审图闭环
2026-10-02 feat: 增加 R04 同版三维装配入口
